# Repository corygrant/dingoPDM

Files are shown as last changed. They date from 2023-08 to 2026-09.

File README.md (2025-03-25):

 






## dingoPDM
dingoPDM is an Infineon Profet based Power Distribution Module. 

# [**Documentation**](https://corygrant.github.io/dingoPDM/)

# [**Store**](https://dingo-electronics.square.site/product/dingopdm/1)

## Disclaimer
Please note that this product has been designed by a hobbyist, not a professional. It is intended for off-road and testing use only. Users should operate the product at their own discretion and risk. The designer explicitly disclaims any responsibility for damage or injury that may result from the use of this product.

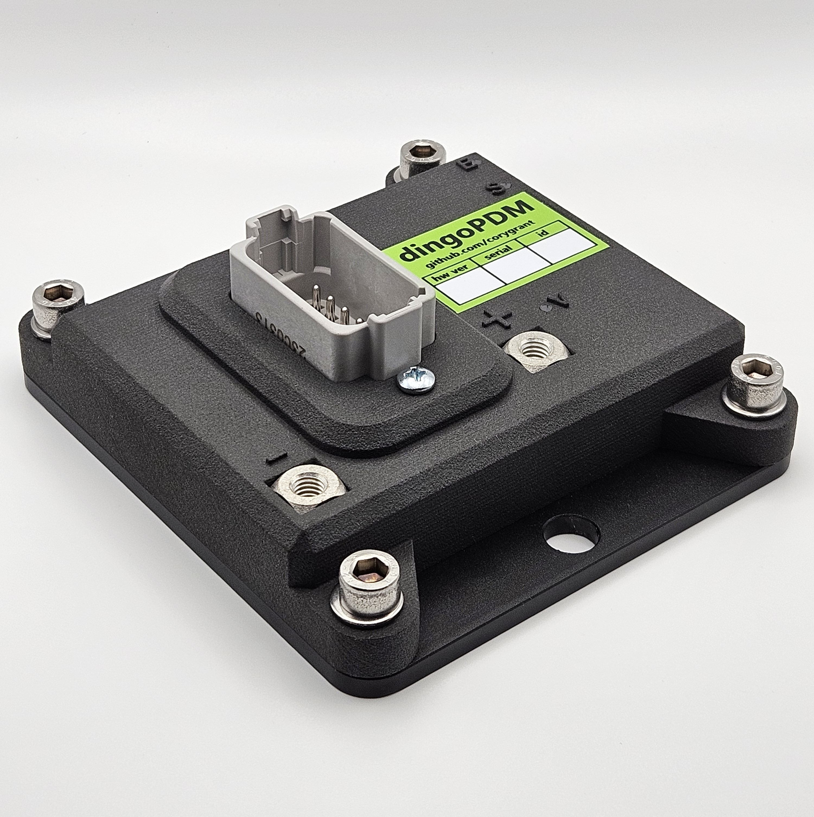
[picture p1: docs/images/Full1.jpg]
Full1


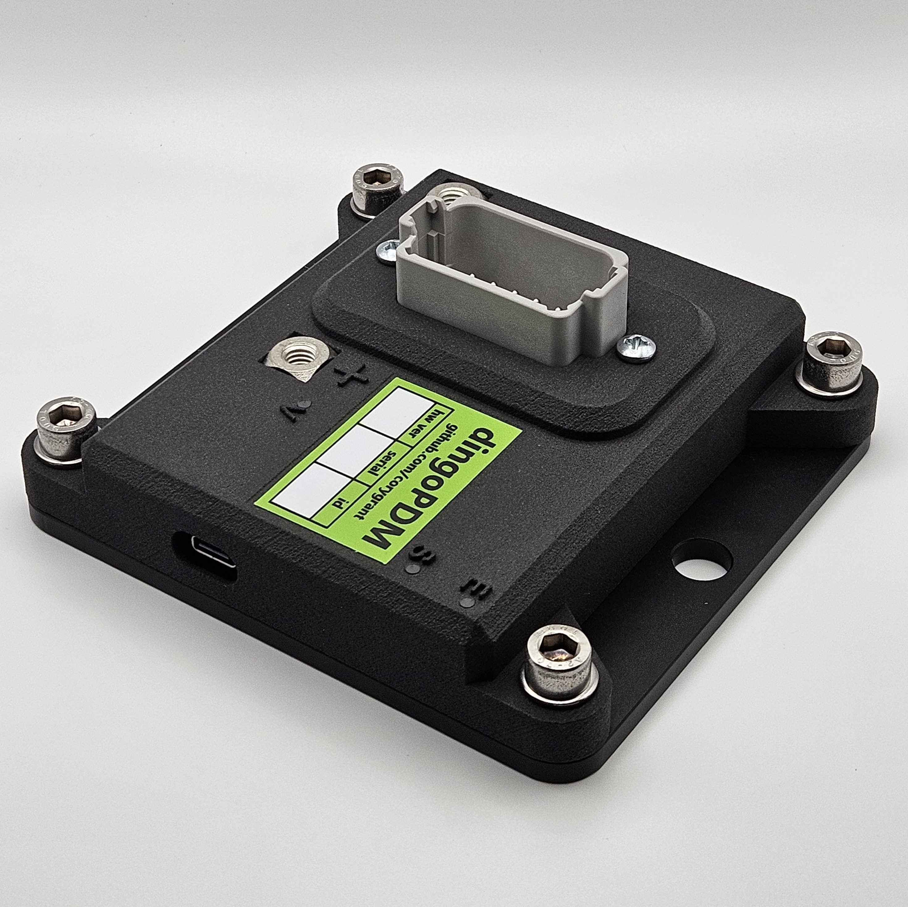
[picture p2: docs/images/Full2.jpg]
Full2


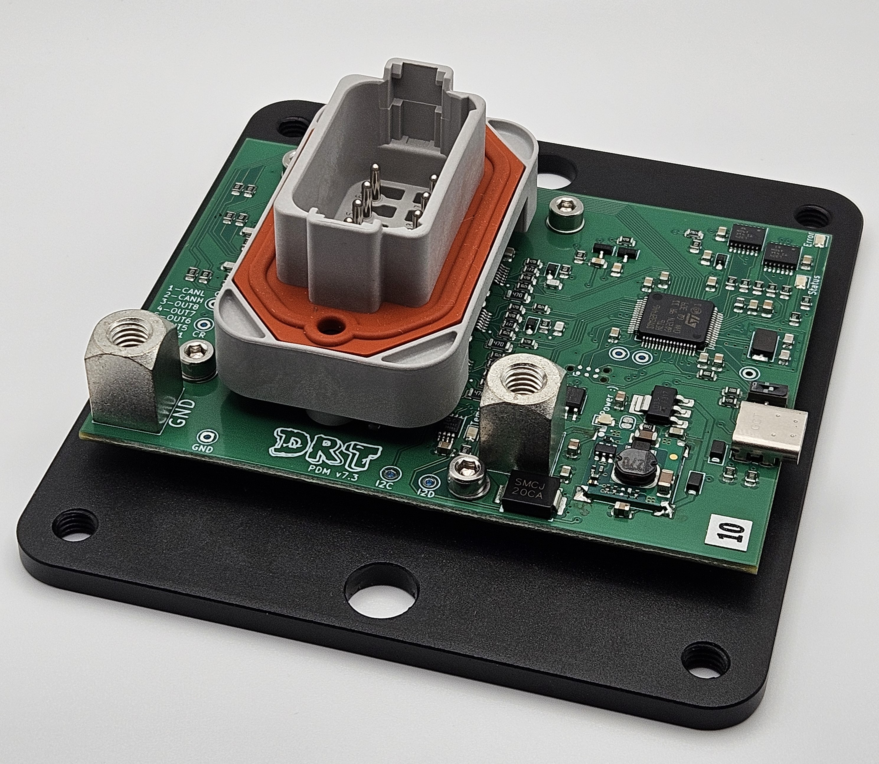
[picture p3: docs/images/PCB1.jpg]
PCB1


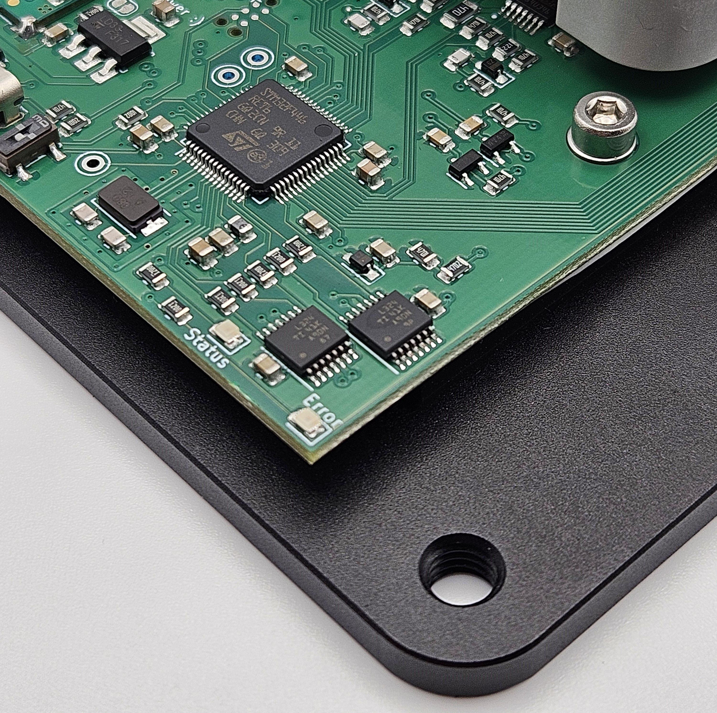
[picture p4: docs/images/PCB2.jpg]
PCB2


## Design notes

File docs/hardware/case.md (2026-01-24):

# Case

Exploded1
Exploded1

Exploded2
Exploded2

The mechanical design is centered around simple designs that can be created in a home shop. 

* 3D Printed Case
* Flat aluminum heatsink plate
* Flat aluminum baseplate
* The heatsink is designed to be 2 pieces. A heatsink plate and a baseplate
    * The heatsink plate provides clearance for the THT pins of the Deutsch connectors and the RedCube terminal while getting as close to the Profets as possible
    * !!! warning
        The heatsink plate should be covered on both sides with a thermal pad material to electricaly isolate the heatsink while still providing a thermal interface (Example: 3M 5583S)
    * The baseplate holds the case and also sandwiches the spacer plate to the PCB

## Exploded Assembly

| ID | Description | Details | Qty |
| ---- | --- | --- | --- |
| 1 | Baseplate | `Aluminum 6061` | 1 |
| 2 | Heatsink | `Aluminum 6061` | 1 |
| 3 | Case | `3D Print` | 1 |
| 4.1  | PCB | | 1 |
| 5.1  | Ring Lug | `M6` or `1/4"` | 1 |
| 5.2  | Lug Washers | `M6 Flat` | 2 |
| 5.3  | Lug Screws | `M6x1.0x14mm` | 2 |
| 5.5  | Case Washers | `M6 Flat` | 4 |
| 5.6  | Case Screws | `M6x1.0x14mm` | 4 |
| 5.7  | PCB Washers | `M3 Flat` | 4 |
| 5.8  | PCB Screws | `M3x0.5x12mm` | 4 |
| 6 | DT Connector | `12 Pin` | 1 |
| 10.1 | Light Pipe | `PLPC2-10MM` | 3 |
| 13 | Connector Screws | `No. 6, 5/8" Thread Forming` | 2 |

## Radlok

As an alternative, Amphenol Radlok 5.7mm connectors can be used for the battery connections instead of ring connectors. 

- Radlok 5.7mm pins and 4AWG connectors are rated at 120A
- Radlock 5.7mm 6AWG connectors are rated at 90A

???+ Note 

    Radlok M6 pin threads are slightly too long, use a washer under the pin to space the pin out. 

| Description | Detail | Rating | Qty | Part Number |
| --- | --- | --- | --- | --- |
| Pin | `M6x1.0` | 120A | 2 | `RL9057-101` |
| M6 Washer | `M6 Flat` | | 2 | |
| | | | | |
| Red Connector | `6AWG` / `16mm^2` | 90A | 1 | `RL0057-1-16RE` |
| Black Connector | `6AWG` / `16mm^2` | 90A | 1 | `RL0057-1-16BK` |
| Alternative Orange Connector | `6AWG` / `16mm^2` | 90A | 1 | `RL0057-1-16` |
| | | | | |
| Red Connector | `4AWG` / `25mm^2` | 120A | 1 | `RL00571-25RE`  |
| Black Connector | `4AWG` / `25mm^2` | 120A | 1 | `RL00571-25BK`  |
| Alternative Orange Connector | `4AWG` / `25mm^2` | 120A | 1 | `RL00571-25` |

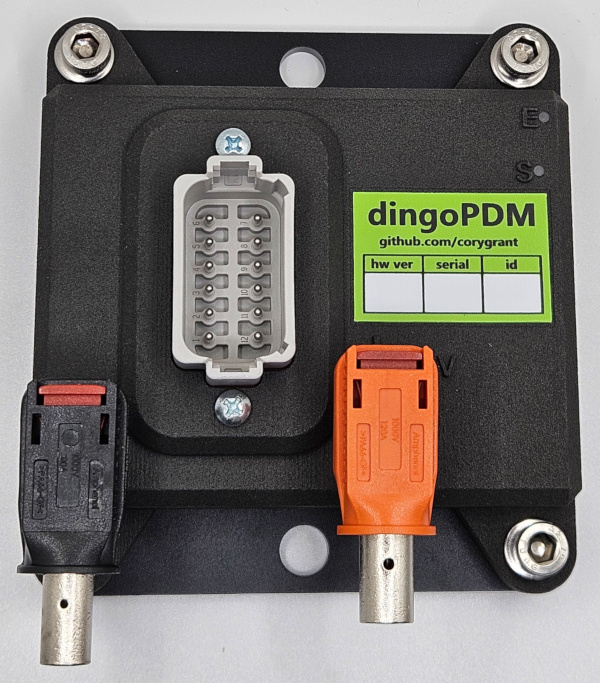
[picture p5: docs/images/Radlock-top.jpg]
RadlockTop


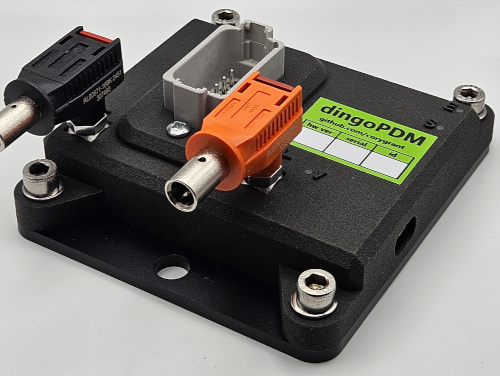
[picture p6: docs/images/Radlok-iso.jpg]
RadlockIso


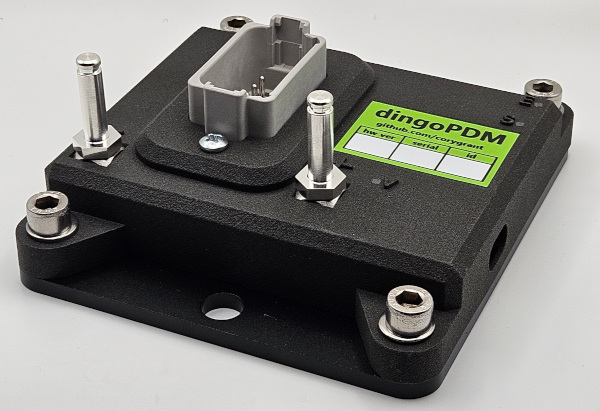
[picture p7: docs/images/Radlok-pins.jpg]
RadlockPins


## Models

Models of the baseplate, heatsink and case can be found here:

[**Case STEP Files**](https://github.com/corygrant/DingoPDM/tree/master/Export/V7.4/Case)

[**Complete STEP File**](https://github.com/corygrant/DingoPDM/tree/master/Export/V7.4) (DingoPDM_V7_4.step)

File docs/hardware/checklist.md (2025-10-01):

# Testing new boards 

These instructions will guide you through verifying some of the basic connections and functionalities.
It's adviced to go through the next steps **before** installing the main connector

|# | Task | Link |
| -| --- | --- |
| 1| Measure resistance between: TODO: verify measurement points | |
| 2| Connect USB and verify: 3v3, Power LED | |
| 3| Connect +12v and verify 5v | |
| 4| Write FW to processor | [FW Releases](https://github.com/corygrant/DingoPDM_FW/releases) |
| 5| Verify that the `Status` LED goes green after one power cycle of red LED (writed default config) | |
| 6| Enable each output in the Configurator. Verify that the output A values are 0. | |
| 7| Measure +12V at each output pad | |

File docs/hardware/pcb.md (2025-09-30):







# Introduction

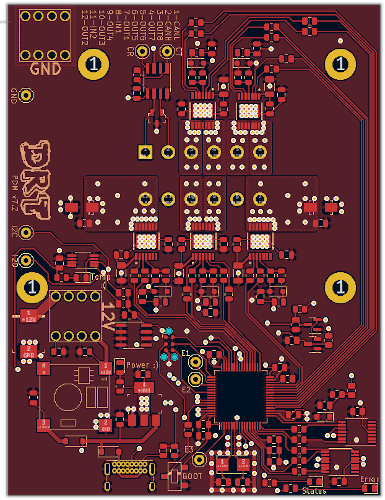
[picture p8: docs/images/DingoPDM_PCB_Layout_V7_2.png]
PCB Design


There are two versions of dingoPDM, standard and Max. 

dingoPDM = 8 outputs (shown above, low and medium current)

dingoPDM-Max = 4 outputs (high current)

## Components

**dingoPDM**

* 2x Profet `BTS7002-1EPP`
    * 2x 14A outputs 
    * With flyback diodes
* 3x Profet `BTS7008-2EPA`
    * 6x 8A outputs
* 2x Digital Inputs
    * Selectable pullup/pulldown
* `STM32F446RET6` Microcontroller
* 256Kbit `FRAM`
    * Settings storage
* CAN transceiver
    * No terminating resistor
* Board temperature measured using `MCP9808`
* 2x LEDs for power and temperature status
* 2x LEDs for status
* Onboard 12V to 5V to 3.3V regulation
* 2x M6 lug 12V power connection
    * Ground connection not used for output power, can be a small gauge (ex: 18AWG or 20AWG)
* 12V voltage measurement
* THT test pads for easy connection of logic analyzer (ex: Saleae leads)
* Deutsch `DT 12 pin` connector
    
**dingoPDM-Max (only differences listed)**

* 4x Profet `BTS70012-1ESP`
    * 4x 26A outputs 
    * With flyback diodes

## KiCad

* Designed using `KiCad v8.0.4`

## Design Notes

* Prior to V6, the design had a lot of features which meant a lot of parts
* To make the board cheaper, easier to source/produce and quicker to test the design was drastically simplified
* The Deutsch DT connector was selected due to it's popularity, part availability and ease of use
* BTS724 was used on V6, but removed for V7 due to thermal issues. It wouldn't trip until a very high current. 

## MCU Pinouts

### dingoPDM

| MCU Pin | Function | Type |
| --- | --- | --- |
| `PA0` | Output 1 Current Sense (IS) | Analog Input |
| `PA1` | Output 5/6 Current Sense (IS) | Analog Input |
| `PA2` | Output 7/8 Current Sense (IS) | Analog Input |
| `PA3` | Battery Voltage Sense | Analog Input |
| `PA4` | Output 8 Control Input (IN) | Digital Output |
| `PA5` | Output 7/8 Sense Select (DSEL)| Digital Output |
| `PA6` | Output 7/8 Sense Enable (DEN) | Digital Output |
| `PA7` | Output 7 Control Input (IN) | Digital Output |
| `PA8` | - | - |
| `PA9` | USB VBUS Sense | Digital Input  |
| `PA10`  | Input 1 | Digital Input  |
| `PA11`  | USB D- (DM) | |
| `PA12`  | USB D+ (DP) | |
| `PA13`  | SWDIO | |
| `PA14`  | SWCLK | |
| `PA15`  | - | - |
| `PB0` | Output 5/6 Sense Enable (DEN) | Digital Output |
| `PB1` | Output 1 Control Input (IN) | Digital Output |
| `PB2` | Output 1 Sense Enable (DEN) | Digital Output |
| `PB3` | SWO | |
| `PB4` | - | - |
| `PB5` | - | - |
| `PB6` | I2C1 SCL | |
| `PB7` | I2C1 SDA | |
| `PB8` | CAN RX | |
| `PB9` | CAN TX | |
| `PB10`  | Output 1 Control Input (IN) | Digital Output |
| `PB12`  | Output 4 Control Input (IN) | Digital Output |
| `PB13`  | - | - |
| `PB14`  | Output 3/4 Sense Select (DSEL)| Digital Output |
| `PB15`  | Output 3/4 Sense Enable (DEN) | Digital Output |
| `PC0` | Status LED | Digital Output |
| `PC1` | Error LED | Digital Output |
| `PC2` | Output 2 Current Sense (IS) | Analog Input |
| `PC3` | Output 3/4 Current Sense (IS) | Analog Input |
| `PC4` | Output 6 Control Input (IN) | Digital Output |
| `PC5` | Output 5/6 Sense Select (DSEL)| Digital Output |
| `PC6` | Output 3 Control Input (IN) | Digital Output |
| `PC7` | Output 2 Sense Enable (DEN) | Digital Output |
| `PC8` | Output 2 Control Input (IN) | Digital Output |
| `PC9` | Input 2 | Digital Input  |
| `PC10`  | Extra 1 | Undefined |
| `PC11`  | Extra 2 | Undefined |
| `PC12`  | CAN Standby | Digital Output |
| `PC13`  | Extra 3 | Undefined |
| `PC14`  | - | - |
| `PC15`  | - | - |
| `PD2` | - | - |
| `PH0` | Oscillator | |
| `PH1` | Oscillator | |

### dingoPDM-Max

| MCU Pin | Function | Type |
| --- | --- | --- |
| `PA0` | Output 3 Current Sense (IS) | Analog Input |
| `PA1` | Output 4 Current Sense (IS) | Analog Input |
| `PA2` | - | |
| `PA3` | Battery Voltage Sense | Analog Input |
| `PA4` | - | |
| `PA5` | Output 4 Sense Enable (DEN) | Digital Output |
| `PA6` | Output 4 Control Input (IN) | Digital Output |
| `PA7` | - | |
| `PA8` | - | - |
| `PA9` | USB VBUS Sense | Digital Input  |
| `PA10`  | Input 1 | Digital Input  |
| `PA11`  | USB D- (DM) | |
| `PA12`  | USB D+ (DP) | |
| `PA13`  | SWDIO | |
| `PA14`  | SWCLK | |
| `PA15`  | - | - |
| `PB0` | Output 3 Control Input (IN) | Digital Output |
| `PB1` | - | |
| `PB2` | - | |
| `PB3` | SWO | |
| `PB4` | - | - |
| `PB5` | - | - |
| `PB6` | I2C1 SCL | |
| `PB7` | I2C1 SDA | |
| `PB8` | CAN RX | |
| `PB9` | CAN TX | |
| `PB10`  | - | |
| `PB12`  | - | |
| `PB13`  | Output 1 Sense Enable (DEN) | Digital Output |
| `PB14`  | Output 1 Control Input (IN) | Digital Output |
| `PB15`  | - | |
| `PC0` | Status LED | Digital Output |
| `PC1` | Error LED | Digital Output |
| `PC2` | Output 2 Current Sense (IS) | Analog Input |
| `PC3` | Output 1 Current Sense (IS) | Analog Input |
| `PC4` | - | Digital Output |
| `PC5` | Output 3 Sense Enable (DEN) | Digital Output |
| `PC6` | Output 2 Sense Enable (DEN) | Digital Output |
| `PC7` | Output 2 Control Input (IN) | Digital Output |
| `PC8` | - | |
| `PC9` | Input 2 | Digital Input  |
| `PC10`  | Extra 1 | Undefined |
| `PC11`  | Extra 2 | Undefined |
| `PC12`  | CAN Standby | Digital Output |
| `PC13`  | Extra 3 | Undefined |
| `PC14`  | - | - |
| `PC15`  | - | - |
| `PD2` | - | - |
| `PH0` | Oscillator | |
| `PH1` | Oscillator | |

## BOMs

[dingoPDM BOM](../bom/dingoPDM/ibom.html)

[dingoPDM-Max BOM](../bom/dingoPDM-Max/ibom.html)

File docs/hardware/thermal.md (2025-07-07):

## Full Load Test

```vegalite 
{
    "schema-url": "assets/charts/dingopdm_stresstest.json"
}
```

```vegalite 
{
    "schema-url": "assets/charts/dingopdmmax_stresstest.json"
}
```

!!! Tip
    - Pan: click + drag
    - Zoom: mouse wheel
    - Reset: double click

!!! Warning
    If chart does not load, refresh the page

- Full load tests were conducted with a dummy load at 71A total.
- The device was mounted horizontaly (worst case).
- Ambient temperature `19°C`
- Resistive load on all outputs
- Temperature taken with onboard temperature sensor, unless otherwise noted
- All outputs on and under load
- All outputs wired using 14AWG TXL in free air and approx. 2 feet long
- Battery power wired using 4AWG cable and copper lug
- Ground wired using 20AWG TXL
- `DC_100`
    - `100%` duty cycle
    - No case
- `DC_50`
    - `50%` duty cycle @ `400Hz`
    - No case
- `CLOSED`
    - `100%` duty cycle
    - Case installed
- `TOP`
    - `100%` duty cycle
    - Case installed
    - Temperature taken at top of Profet (output 3/4) using thermocouple
- `Yellow`
    - Warning temperature limit `55°C`
    - Reaction: warning message sent
- `Red`
    - Critical temperature limit `80°C`
    - Reaction: device shutdown, power cycle required

!!! note "Notes"
    - Thermal performance is similar with or without PWM (on resistive loads)
    - The onboard temperature sensor follows the junction temperature within a few degrees after 10 minutes
    - Installing the case increases the temperature by a maximum of `5°C`
    - The temperatures seen by the onboard sensor and thermocouple are much lower than the maximum temperature of the Profet junction `150°C`

## Thermal Images

These images were captured during the 100% duty cycle full load test. 

The highest temperature recorded was 61°C at the top of the output 3/4 Profet (BTS7008-2EPA). 

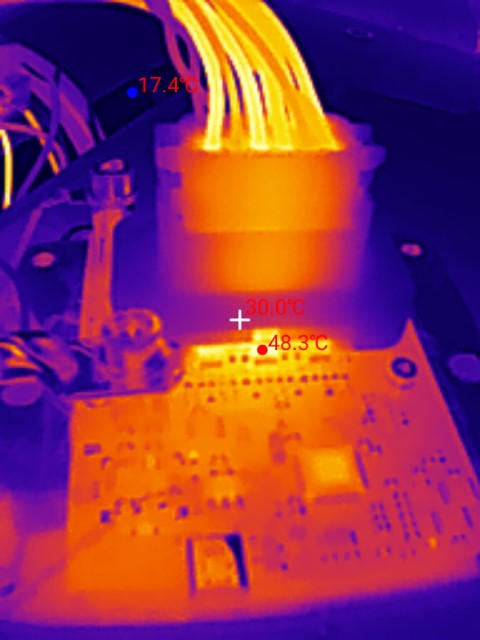
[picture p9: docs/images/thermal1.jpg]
Thermal1

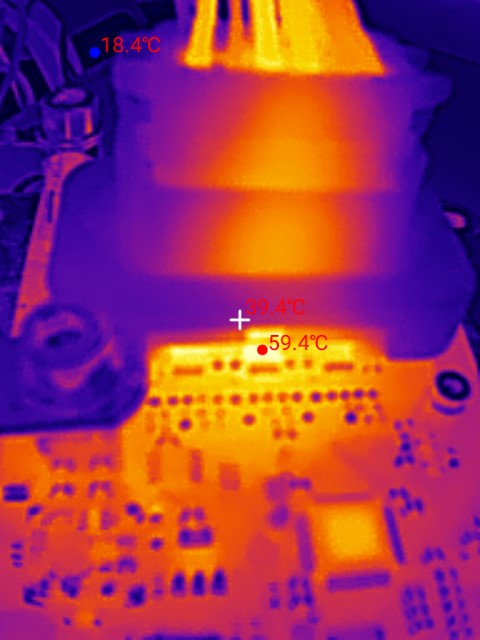
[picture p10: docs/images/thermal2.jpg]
Thermal2

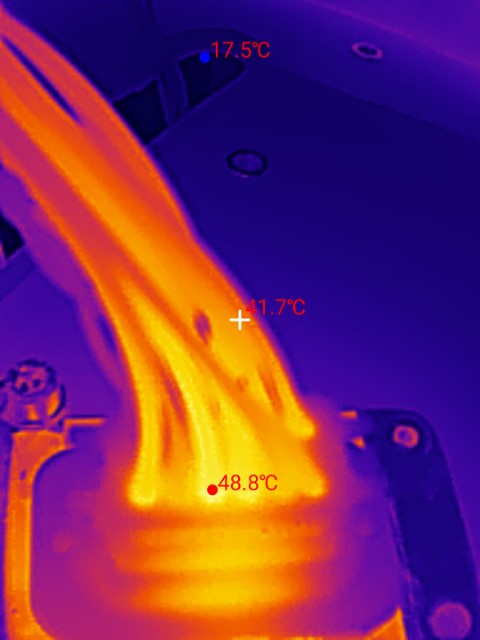
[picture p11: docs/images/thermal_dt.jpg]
ThermalDT

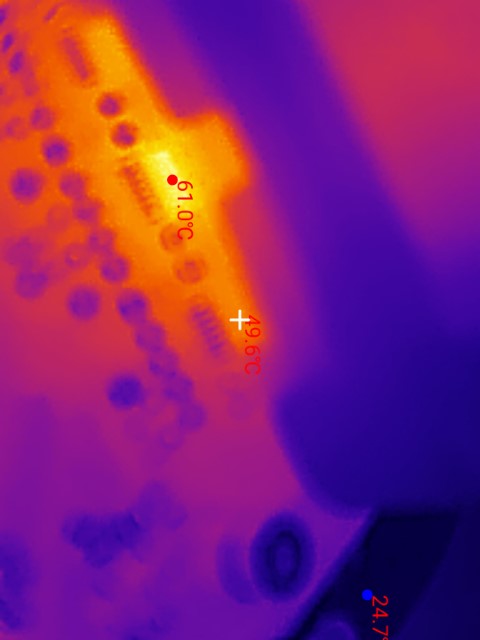
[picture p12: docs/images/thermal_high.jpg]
ThermalHigh


!!! note "Notes"
    - Deutsch DT connectors have an operating temperature range up to `125°C`
      - While we do not know the actual internal temperature, the highest recorded external temperature during these tests was around `50°C`
      - That is much lower than the rated operating temperature, which suggests higher current may be possible

## Thermal Resistance

Before building or testing any hardware, we can calculate the expected temperature on the top of the Profet. 

To do this, we need these values:

- Ambient temperature (°C)
- Total current (A)
- R<sub>thJA</sub> (K/W)
    - See Infineon datasheet section 4.4
    - Thermal Resistance Junction to Ambient, (K/W)=(C/W)
    - Temperature rise per dissipated watt from the internal junction to ambient
    - Value calculated by Infineon at natural convection on a 4 layer PCB:
        - 2oz outer copper
        - 1oz inner copper
        - 76.2mm x 114.3mm board
    - The resulting value is added to the ambient temperature
    - Infineon uses Kelvin/Watt, this is equal to Celsius/Watt
- Ψ<sub>JTOP</sub> (K/W)
    - See Infineon datasheet section 4.4
    - Thermal Characterization Parameter Junction Top, (K/W)=(C/W)
    - Thermal resistance between the internal junction and the top of chip case
    - Value calculated by Infineon using the same test parameters as R<sub>thJA</sub> above
    - The resulting value will be subtracted from the junction temperature to find the expected temperature at the top of the chip case
- R<sub>DS(ON)</sub> (mΩ)
    - See Infineon datasheet section 7.5.1
    - On State Resistance (mΩ)
    - Resistance between the battery connection and the output when the Profet is on, varies with junction temperature
    - Use this to calculate the heat generated by the chip
    - Assuming the junction temperature is 60°C, use R<sub>DS(ON)</sub> of 3.2mΩ and 11mΩ

BTS7002-1EPP

`Power(W)` = (Current x R<sub>DS(ON)</sub>) x Current = 12<sup>2</sup> x 3.2 = `0.461 W`

`Junction Temp(°C)` = Ambient + (Power x R<sub>thJA</sub>) = 19 + (0.461 x 30.7) = `33°C`

`Case Top(°C)` = Junction Temp - (Power * Ψ<sub>JTOP</sub>) = 33 - (0.461 x 3) = `32°C`

BTS7008-2EPA

`Power(W)` = (Current x R<sub>DS(ON)</sub>) x Current = 8<sup>2</sup> x 11 = `0.704 W` x 2 = `1.408 W`

`Junction Temp(°C)` = Ambient + (Power x R<sub>thJA</sub>) = 19 + (1.408 x 30.9) = `63°C`

`Case Top(°C)` = Junction Temp - (Power * Ψ<sub>JTOP</sub>) = 63 - (1.408 x 1.7) = `60°C`

Table format:

| Model | R<sub>DS(ON)</sub> @ 25°C (mΩ) | R<sub>DS(ON)</sub> @ 150°C (mΩ) | R<sub>DS(ON)</sub> (mΩ) | Current Per Output (A) | Dissipated Power (W) | # Channels | Total Dissipated Power (W) | Ambient Temp (°C) | R<sub>thJA</sub> (C/W) | Junction Temp (°C) | Ψ<sub>JTOP</sub> (C/W) | Case Top (°C) |
|:---:|:---:|:---:|:---:|:---:|:---:|:---:|:---:|:---:|:---:|:---:|:---:|:---:|
| BTS7002-1EPP | 2.6 | 4.8 | 3.2 | 12 | 0.461 | 1 | 0.461 | 19 | 30.7 | 33 | 3 | 32 |
| BTS7008-2EPA | 9 | 16 | 11 | 8 | 0.704 | 2 | 1.408 | 19 | 30.9 | 63 | 1.7 | 60 |

!!! note "Notes"
    - The BTS7008-2EPA expected case temperature (`60°C`) is close to the measured values
        - Thermocouple = `55°C` 
            - May be reduced due to glue used to hold thermocouple
        - Thermal camera = `61°C`
    - The BTS7002-1EPP expected case temperature (`32°C`) is lower than the measured value
        - Thermal camera = `50°C`
        - This may be caused by the adjacent BTS7008-2EPA which is at a higher temperature of `60°C`
    - The Profet maximum junction temperature is `150°C`, much higher than the temperatures we are seeing in these full load tests

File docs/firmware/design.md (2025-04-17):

# Design

## Device State

dingoPDM uses a simple state machine to control overtemperature, sleep and error behavior. 

``` mermaid
stateDiagram
    [*] --> Run : Power On
    Run --> OverTemp : Temp > Max
    OverTemp --> Run : Temp < Max
    Run --> Sleep : Timeout
    Sleep --> Run : Activity
    Run --> Error : Error
    OverTemp --> Error : Temp > Critical
    Error --> [*] : Power Cycle Required
```

See [Sleep](./sleep.md) for information on the sleep timeout and wake

See [Errors](./errors.md) for information on possible fatal errors

See [LEDs](./leds.md) for possible status and error LED states

- `Run`
    - Default state
- `Sleep`
    - All outputs off
    - Low power state
- `OverTemp`
    - Temperature sensor mounted to PCB over max temp
    - Warning message sent
    - Outputs remain on
- `Error`
    - Fatal error state, power cycle required to recover

## Files

dingoPDM firmware files can be divided between ChibiOS, OpenOCD and dingoPDM specific files

### ChibiOS

- cfg/ 
    - ChibiOS configuration files
- ChibiOS/
    - ChibiOS repository files
- boards/./board (.h / .c / .mk)
    - ChibiOS configuration files
    - Unique between dingoPDM and dingoPDM-Max
  
### OpenOCD

- interface/
    - ST Link debug interface
- target/
    - STM32F4 debug configuration
  
### dingoPDM

#### Folders

- boards/
    - dingoPDM and dingoPDM-Max specific config and utils
    - hw_devices
        - 
- boards/cortex-m4/
    - MCU specific utils (stop/bootloader)
- devices/ 
    - External devices (future)
- hardware/
    - Onboard hardware devices (FRAM/temperature)
- keypad/
    - CAN keypads
- wiper/
    - Wiper function

#### Declaration

| File | |
| :--- | :--- |
| dingopdm_config | FW version / delays / limits / etc. |
| enums | All enum declarations |

#### Entry Point

| File | |
| :--- | :--- |
| main | Init ChibiOS + start PDM |

#### PDM Main

| File | |
| :--- | :--- |
| pdm  | Main PDM logic |

#### Hardware

| File | |
| :--- | :--- |
| can  | CAN Tx/Rx - Post/Fetch Mailboxes |
| led  | Status/Error LEDs |
| usb  | USB Tx/Rx - Post/Fetch Mailboxes |

#### Configuration 

| File | |
| :--- | :--- |
| config_handler | Process setting change |
| config | Read/Write config in FRAM |
 
#### Functions

| File | |
| :--- | :--- |
| can_input | CAN Rx decoding / logic |
| condition | Condition logic |
| counter | Counter logic |
| digital | Digital input logic |
| flasher | Flasher logic |
| input | Momentary/latching logic |
| profet | Output logic + current measurement  |
| pwm | Output Pulse Width Modulation logic |
| starter | Starter disable logic |
| virtual_input | Virtual input logic |

#### Utilities

| File | |
| :--- | :--- |
| crc | Calculate CRC |
| edge | Detect edge - rising/falling  |
| error | Fatal error - Flash LED |
| mailbox | CAN/USB Tx/Rx mailbox buffers |
| msg | Status Tx messages |

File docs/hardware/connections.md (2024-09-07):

# Connections

## Connectors

Connections
Connections

|ID| Connector | Details | Qty | Note |
| -| --- | --- | --- | --- |
| 1| DT 12 Pos Connector | `DT06-12SA` | 1 | |
|  | DT 12 Wedgelock | `W12S` | 1 | |
|  | 14-16AWG Socket | `0462-209-16141` | 2 | |
|  | 16-20AWG Socket | `0462-201-16141` | 10  | |
| 2| 12V DC Power Lug | `M6` or `1/4"` lug  | 1 | Large gauge wire required (4 to 10AWG) |
| 3| Ground Lug | `M6` or `1/4"` lug  | 1 | Small gauge wire can be used (18 to 20 AWG) |
| 4| USB Type C | | 1 | USB C-C cables are not supported with v7.2 hardware |

## USB

!!!warning
    USB C-C cables are not supported with v7.2 hardware

| Hardware | USB C-C | USB A-C |
|---| ---| ---|
| v7.2 | :red_square:  | :green_square: |
| v7.3 and up | :green_square:| :green_square: |

## Pinout

DT 12
DT 12

# dingoPDM

| Pin | Function| Current |
| --- | --- | --- |
| 1 | CAN L | |
| 2 | CAN H | |
| 3 | Output 8| 8A |
| 4 | Output 7| 8A |
| 5 | Output 6| 8A |
| 6 | Output 5| 8A |
| 7 | Output 1| 13A |
| 8 | Input 1 | |
| 9 | Output 4| 8A |
| 10  | Output 3| 8A |
| 11  | Input 2 | |
| 12  | Output 2| 13A |

!!! note
    The current outputs are estimates and based on the maximum current rated by Deutsch.
    The possible current may be higher depending on the installation and configuration. 

!!! note
    No internal terminating resistor on CAN connection, must be added externally    

# dingoPDM-Max

| Pin | Function| Current |
| --- | --- | --- |
| 1 | Output 4| 26A |
| 2 | Output 4| 26A |
| 3 | CAN L | |
| 4 | CAN H | |
| 5 | Output 3| 26A |
| 6 | Output 3| 26A |
| 7 | Output 1| 26A |
| 8 | Output 1| 26A |
| 9 | Input 1 | |
| 10  | Input 2 | |
| 11  | Output 2| 26A |
| 12  | Output 2| 26A |

!!! note
    The current outputs are estimates and based on the maximum current rated by Deutsch.
    The possible current may be higher depending on the installation and configuration. 

!!! note
    No internal terminating resistor on CAN connection, must be added externally

## Test Points

Test Points
Test Points

| Label | Function | MCU Pin |
| --- | --- | --- |
| I2C | I2C1 Clock | `PB6` |
| I2D | I2C1 Data | `PB7` |
| CR | CAN Receive  | `PB8` |
| CT | CAN Transmit | `PB9` |
| E1 | Extra 1 | `PC10`  |
| E2 | Extra 2 | `PC11`  |
| E3 | Extra 3 | `PC13`  |
| GND | Ground | `Ground`|
| TagConnect| Debugger | |

## Wipers

To control a wiper motor directly from dingoPDM a WiperModule is required. 
The WiperModule uses 3 relays to properly control the slow, fast and brake functions of a wiper motor. 
The internal connections are made based on the slow input (which also supplies all power to the motor) and the fast input. 
The ground and park signals are passed through the module. 

Information about the WiperModule can be found here: [WiperModule](https://github.com/corygrant/WiperModule)

WiperModuleConnections
WiperModuleConnections

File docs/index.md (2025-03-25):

# dingoPDM

 


dingoPDM and dingoPDM-Max are open source Infineon Profet based Power Distribution Modules. 

<span style="font-size: 1.5em;">
**[Getting Started](./gettingstarted/introduction.md)**
</span>

Full1

Full2

PCB1

PCB2

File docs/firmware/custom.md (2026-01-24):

# Adding Custom Board Support to dingoPDM Firmware

## Overview

This guide walks you through adding support for a custom PDM board to the dingoPDM firmware. By following these steps, you'll build the firmware to run on your custom hardware while reusing existing functionality.

## Hardware

### Pins

The pins you need depend on which Profets (switching devices) you're planning to use.

#### BTS7002-1EPP

| Pin Type | Count | Name  | Purpose |
| --- | ----- | ----- | --- |
| Analog Input | 1 | `IS`  | Current feedback |
| Digital Output | 1 | `IN`  | Drive transistor ON/OFF (PWM-enabled) |
| Digital Output | 1 | `DEN` | Enable current sensing |

#### BTS7008-2EPP Variant

| Pin Type | Count | Name | Purpose |
| --- | ----- | --- | --- |
| Analog Input | 1 | `IS` | Current feedback |
| Digital Output | 1 | `IN` | Drive transistor ON/OFF (PWM-enabled) |
| Digital Output | 1 | `DSEL` | Select which output's current is measured |
| Digital Output | 1 | `DEN`  | Enable current sensing |

> **Note:** The BTS7008-2EPP uses a single shared current feedback channel with multiplexing via `DSEL`, while the BTS7002-1EPP has a dedicated feedback pin. All `IN` pins must support PWM; other outputs can use regular GPIO.

### PCB Design

!!! warning "To Do"
    *Schematic recommendations and layout guidelines*

---

## Firmware

The dingoPDM firmware is modular—adding a new board requires minimal changes outside the `boards/` folder. Follow these steps in order:

### Overview

- [ ] Copy and rename an existing board folder
- [ ] Update the `.ld` linker script
- [ ] Configure `board.mk`
- [ ] Define pins in `board.h`
- [ ] Set output count in `port.h`
- [ ] Declare outputs in `hw_devices.cpp`
- [ ] Update message handling in `msg.cpp`
- [ ] Update root `Makefile`
- [ ] Add PWM configuration in `port_pwm.h`
- [ ] Enable timers in `mcuconf.h` (if needed)

---

### Files

#### Linker Script (`.ld`)

**Location:** `boards/your_board_name/`

**Changes needed:**
- Rename the `.ld` file to match your board name exactly

---

#### Board Configuration (`board.mk`)

**Location:** `boards/your_board_name/`

???+ Example

    ```makefile
    # List of all the board related files
    BOARDSRC = ./boards/your_board_name/board.c

    # Required include directories
    BOARDINC = ./boards/your_board_name
    ```

---

#### Pin Definitions (`board.h`)

**Location:** `boards/your_board_name/`

This file initializes all MCU pins and their configurations. Define each pin type with the settings below:

!!! Note
    Refer to ChibiOS documentation on `board.h` configuration

???+ abstract "`IN` Pin Configuration"

    ```c
    Mode     = OUTPUT
    Otype    = PUSHPULL
    Ospeed   = HIGH
    Pupdr    = PULLDOWN
    Odr      = LOW
    Afio     = AF
    ```

???+ abstract "`DEN` Pin Configuration"

    ```c
    Mode     = OUTPUT
    Otype    = PUSHPULL
    Ospeed   = HIGH
    Pupdr    = PULLDOWN
    Odr      = LOW
    Afio     = AF
    ```

???+ abstract "`DSEL` Pin Configuration"

    ```c
    Mode     = OUTPUT
    Otype    = PUSHPULL
    Ospeed   = HIGH
    Pupdr    = PULLDOWN
    Odr      = LOW
    Afio     = AF
    ```

???+ abstract "`IS` Pin Configuration"

    ```c
    Mode     = ANALOG
    Otype    = PUSHPULL
    Ospeed   = LOW
    Pupdr    = FLOATING
    Odr      = LOW
    Afio     = AF
    ```

---

#### Counts (`port.h`)

**Location:** `boards/your_board_name/`

???+ Example

    ```c
    #define PDM_TYPE 2              // 0 = PDM, 1 = PDM-MAX, 2 = your new board
    #define PDM_NUM_OUTPUTS 8       // Total number of Profet outputs on your board
    #define PDM_NUM_INPUTS 2        // Total number of digital inputs on your board
    ```

!!! warning "To Do"

    Setting up and using VarMap

---

#### Output Declarations (`hw_devices.cpp`)

**Location:** `boards/your_board_name/`

**Key points:**
- Only modify the `#if PDM_TYPE == 2` section (match your PDM_TYPE value)
- Declare outputs in order: `IN`, `DEN`, `DSEL`, `IS`
- `&PWMD` specifies the timer module (must be unique per output)
- `&pwmCfg` references the PWM configuration (defined in `port_pwm.h`)

???+ Example

    ```c
    #if PDM_TYPE == 2
    // Output declarations for your board
    // Each output needs timer assignment and config reference
    #endif
    ```

---

#### CAN/USB Message Handling (`msg.cpp`)

**Location:** `common/` (root-level modification)

Update this file to transmit the status of your new outputs in both CAN and USB streams. Check existing board implementations for the pattern.

---

#### Root Makefile

**Location:** `Makefile` (repository root)

???+ Example "Changes needed"

    ```makefile
    ifeq ($(BOARD),)
        BOARD = your_board_name
    endif
    ```

---

#### PWM Configuration (`port_pwm.h`)

**Location:** `boards/your_board_name/`

**Steps:**
1. Copy an existing PWM configuration and rename it for your board
2. Declare the `.callback` member for each output
3. Add callback functions in two sections:
   - **Output PWM period callbacks** – called when PWM period changes
   - **Output PWM duty cycle callbacks** – called when duty cycle changes

???+ Example "Example callback pattern"

    ```c
    static void your_board_pwm_period_callback(uint16_t value) {
        // Handle period change
    }

    static void your_board_pwm_duty_callback(uint16_t value) {
        // Handle duty cycle change
    }
    ```

---

#### Timer Configuration (`mcuconf.h`)

**Location:** `boards/your_board_name/`

**When needed:**
- Enable new timer peripherals **only if** your PWM configuration uses timers not already enabled
- Check existing boards to see which timers are already configured
- If reusing timers from the reference board, no changes needed

---

## Build and Flash

Once all files are configured:

- **Build the firmware**
   ```bash
   make BOARD=your_board_name
   ```

- **Flash to your STM32**
    - Follow the existing [firmware flashing wiki](https://corygrant.github.io/dingoPDM/firmware/updating/)

---

## Validation Checklist

Before testing your custom board:

- [ ] All pin definitions in `board.h` match your schematic
- [ ] `PDM_NUM_OUTPUTS` matches your physical output count
- [ ] `PDM_NUM_INPUTS` matches your physical input count
- [ ] `PDM_TYPE` is unique and consistent across all files
- [ ] All PWM timer assignments are unique (no conflicts)
- [ ] `msg.cpp` includes your outputs in CAN/USB telemetry
- [ ] `.ld` linker script is renamed correctly
- [ ] Firmware builds without errors: `make BOARD=your_board_name`

---

## Common Issues & Troubleshooting

| Issue | Cause | Solution |
| --- | --- | --- |
| **Linker errors** | `.ld` file not renamed or path wrong | Verify `.ld` filename matches board name exactly |
| **Undefined PDM_TYPE** | Inconsistent `PDM_TYPE` values across files | Search all files and ensure consistency |
| **PWM conflicts** | Timer assigned to multiple outputs | Review `hw_devices.cpp` and use unique timers |
| **Build fails: unknown board** | Root Makefile not updated | Add board to `ifeq` block in root `Makefile` |
| **Outputs not responding** | Wrong pin configuration | Double-check `board.h` pin modes and alternate functions |

---

## Reference: File Structure

```
DingoPDM_FW/
├── Makefile
├── boards/
│   ├── existing_board_1/
│   │   ├── board.c
│   │   ├── board.h
│   │   ├── board.mk
│   │   ├── board_name.ld
│   │   ├── hw_devices.cpp
│   │   ├── mcuconf.h
│   │   ├── port.h
│   │   └── port_pwm.h
│   └── your_board_name/          ← Copy here
│       ├── board.c
│       ├── board.h
│       ├── board.mk
│       ├── your_board_name.ld
│       ├── hw_devices.cpp
│       ├── mcuconf.h
│       ├── port.h
│       └── port_pwm.h
└── common/
    ├── msg.cpp                    ← Update here
    └── ...
```

---

## Next Steps

After building and flashing:

- Verify all outputs turn on/off correctly
- Monitor current feedback (`IS`) pins via CAN/USB telemetry
- Test PWM duty cycle control on `IN` pins
- Validate multiplexing on `DSEL` (BTS7008-2EPP only)

For questions, refer to the main [dingoPDM GitHub repository](https://github.com/corygrant/DingoPDM_FW)

!!! Note
 
    Thanks to **jabbarider** for this write up

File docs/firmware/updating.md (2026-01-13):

dingoPDM firmware can be updated using the onboard USB-C connection. 

## Latest Firmware

The latest built firmware can be found on the repo on [the release page](https://github.com/corygrant/DingoPDM_FW/releases)

## STM32CubeProgrammer

To update the firmware, the STMicroelectronics STM32CubeProgrammer is used. 

This software can be downloaded here: [STM32CubeProgrammer](https://www.st.com/en/development-tools/stm32cubeprog.html)

## Entering Bootloader

To update the firmware, the device must be put into the bootloader. 

This can be done using one of these methods:

* Remove the case and move the [boot switch](#boot-switch) to the bootloader position
* Use DingoConfigurator [FwUpdate button](#fwupdate) to jump the device to the bootloader

## Boot Switch

To update the firmware, the device must be put into bootloader

One option is using the `boot` switch on the PCB. 

!!! Note
    The case must be removed to access the boot switch.

    * Remove the DT connector and any wires going to the power/ground connections
    * Remove the 2x Philips screws next to the DT connector
    * Remove the 4x M6 screws around the perimeter of the device
    * Slide/wiggle the case up and off the device

To enter the bootloader, move the slide switch to the position that aligns it with the lines on the switch body

BootSwitch1
BootSwitch1

!!! Warning
    After updating, remember to set the boot switch back to the original position

## FwUpdate

After connecting to the dingoPDM using dingoConfigurator, the `FwUpdate` button on the toolbar to send the `~BOOTL` message to put the device into the bootloader.

!!! Warning
    Pressing the `FwUpdate` button will stop the PDM and drop communication to DingoConfigurator

## Connection

Connect a USB-C to USB-A cable to the PC. 

!!! Note
    V7.2 PCBs do not support USB-C to USB-C cables, a USB-C to USB-A cable must be used

!!! Note
    12V power is not required to perform the firmware update, the device will be powered by the USB cable

To verify that the device has entered the bootloader:

* Open the Windows `Device Manager`
* Expand `Universal Serial Bus devices`
* The `STM32 BOOTLOADER` should be listed
* DeviceManager

## Applying Update

* Install `STM32CubeProgrammer`
* Open `STM32CubeProgrammer`
* Change connection type to `USB`
* Press the refresh button to update the port

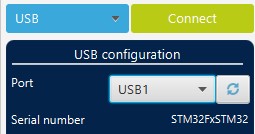
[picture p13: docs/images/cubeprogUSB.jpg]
CubeProgUSB
* 

* Press the `Connect` button, after successful connection the `Target Information` should be updated
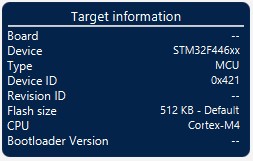
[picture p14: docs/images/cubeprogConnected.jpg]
CubeProgConnected
* 
* Select the second icon on the left, `Erasing & Programming`
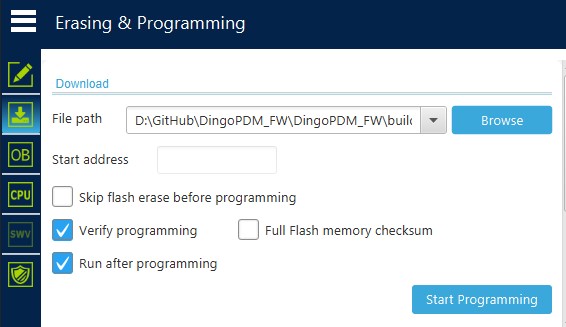
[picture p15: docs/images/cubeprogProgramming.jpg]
CubeProgProgramming
* 
* Press `Browse` and select the new firmware .hex file
* Verify `Skip flash erase before programming` is unchecked
* Verify `Verify programming` and `Run after programming` are checked
* Press `Start Programming`
* After successful programming, the device will disconnect
* You should also receive pop-ups verifying successful programming
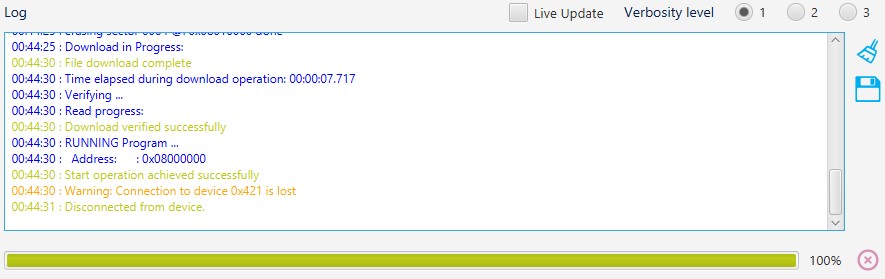
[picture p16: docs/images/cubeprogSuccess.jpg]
CubeProgSuccess
* 

## Success

Congrats! You successfuly updated the dingoPDM firmware. 

The firmware version can be verified using DingoConfigurator

!!! Warning
    Don't forget to set the boot switch back to the original position!

!!! Danger
    A POWER CYCLE IS REQUIRED any time the boot switch is changed

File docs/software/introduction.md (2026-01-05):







!!! warning
    DingoConfigurator has been replaced by [dingoConfig](https://github.com/corygrant/dingoConfig/releases). Documentation will be updated. 

DingoConfigurator is a Windows application designed to configure and monitor dingoPDM. 

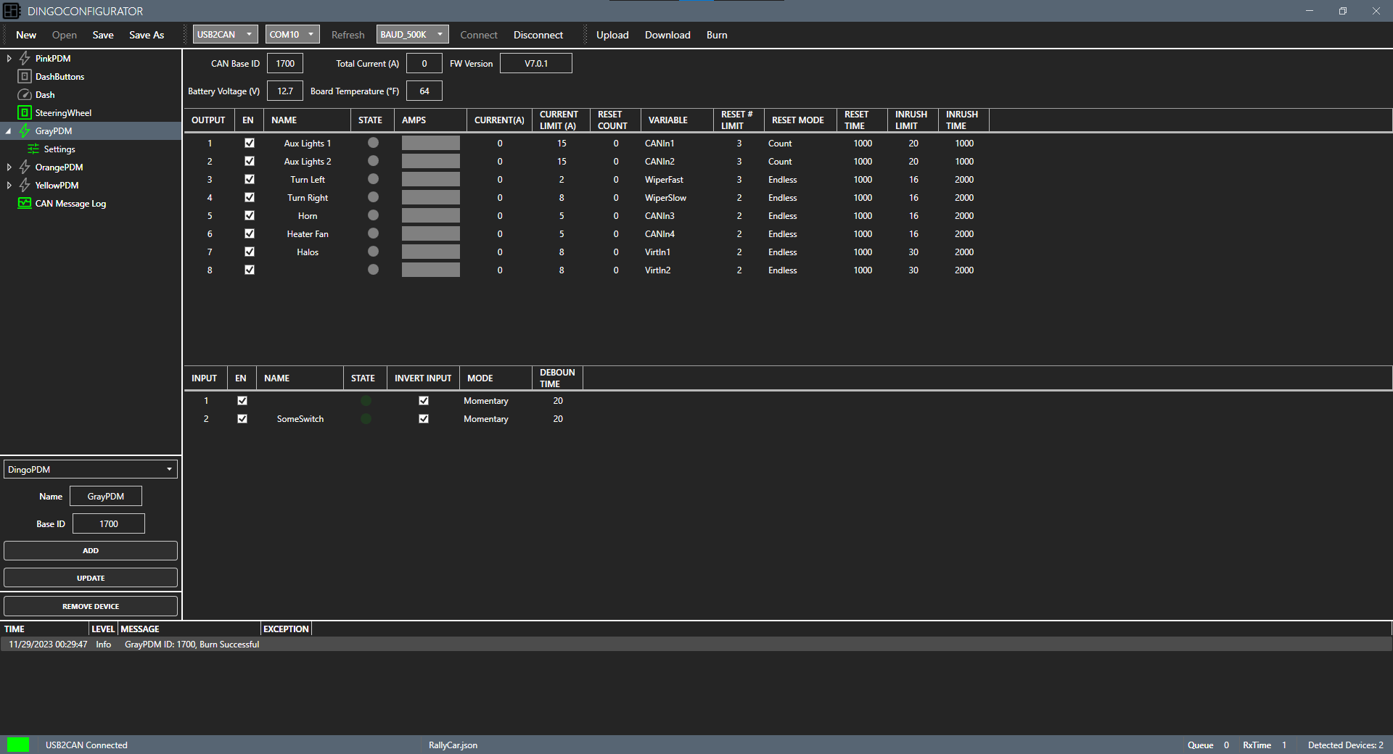
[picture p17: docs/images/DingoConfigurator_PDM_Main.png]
PDM Main


## Download

The latest version can be downloaded here: [DingoConfigurator](https://github.com/corygrant/DingoConfigurator/releases)

## Installation

!!!Info
    The installer has not been built yet.

    First install [STM32CubeProgrammer](https://www.st.com/en/development-tools/stm32cubeprog.html) 

    Download the `.zip` from the link above, unzip and run `DingoConfigurator.exe`

## Supported Devices

DingoConfigurator currently supports these devices:

| Manufacturer | Device |
| --- | --- |
| Dingo Electronics | [dingoPDM](https://github.com/corygrant/dingoPDM) |
| Dingo Electronics | [CANBoard](https://github.com/corygrant/CANBoard_HW)  |

!!! Note
    New devices can/will be added when I have access to the hardware 

## Supported CAN Interfaces

DingoConfigurator currently supports these CAN interfaces.

| Manufacturer | Device |
| --- | --- |
| Dingo Electronics | [USB2CAN](https://github.com/corygrant/USB2CAN_HW) |
| PEAK-System | [PCAN-USB](https://www.peak-system.com/PCAN-USB.199.0.html?&L=1)  |

!!! Note
    New devices can/will be added when I have access to the hardware 

## Sections

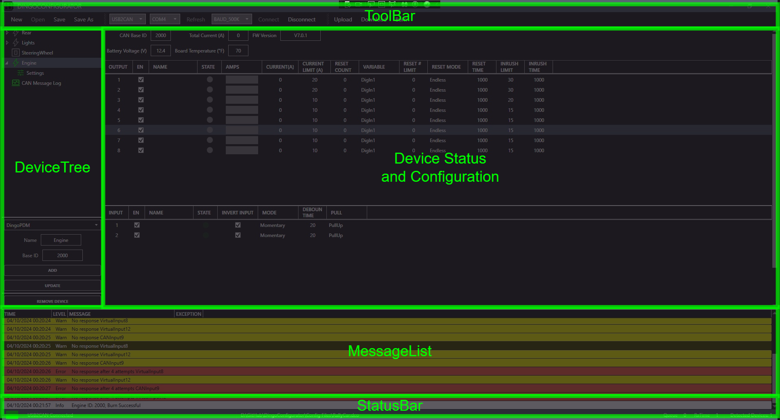
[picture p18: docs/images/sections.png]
PDM Sections


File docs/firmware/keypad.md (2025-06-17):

## Introduction

dingoPDM supports up to 2 CANopen keypads per device as the keypad CANopen master node. 
 
As the keypads CANopen master node dingoPDM will:

- Send the start transmitting message
- Set the backlight color
- Set the button colors or LEDs

Each keypad needs only 1 CANopen master node. 

Additional keypad CANopen messages can be configured as CAN inputs without needing to be the CANopen master node. 

### Models

!!! Warning
    Only CANopen keypads are currently supported

- :green_square: : Tested
- :yellow_square: : Supported, Untested
- :blue_square: : Supported in the future
- :red_square: : Unsupported
  
| Brand | Model | Protocol  | Status |
| :--- | :--- | :--- | :---: |
| `Blink Marine` | `PKP-1600-SI` | `CANopen` | :yellow_square: |
| `Blink Marine` | `PKP-2200-SI` | `CANopen` | :yellow_square: |
| `Blink Marine` | `PKP-2300-SI` | `CANopen` | :yellow_square: |
| `Blink Marine` | `PKP-2400-SI` | `CANopen` | :yellow_square: |
| `Blink Marine` | `PKP-2500-SI` | `CANopen` | :yellow_square: |
| `Blink Marine` | `PKP-2600-SI` | `CANopen` | :green_square:  |
| `Blink Marine` | `PKP-3500-SI` | `CANopen` | :yellow_square: |
| `Blink Marine` | `PKP-3500-SI-MT` | `CANopen` | :yellow_square: |
| `Blink Marine` | `PKP-1200-LI` | `CANopen` | :yellow_square: |
| `Blink Marine` | `PKP-1500-LI` | `CANopen` | :yellow_square: |
| `Blink Marine` | `PKP-2200-LI` | `CANopen` | :yellow_square: |
| `Blink Marine` | `PKP-2400-LI` | `CANopen` | :yellow_square: |

!!! Note
    If you've tested one of the :yellow_square: marked models above please let me know

## Initial Setup

### Setting Node ID

### Setting Transmit Rate

## Blink Marine

### Backlight

### Button Backlight

### Dial

## Grayhill

### Button LEDs

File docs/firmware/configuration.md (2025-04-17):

## Introduction

To enable changes to the dingoPDM configuration and to persist those changes across a power cycle dingoPDM uses a configuration struct that is read from and written to FRAM over I2C. 

## Read

When dingoPDM is powered on, the first thing it does after initializing ChibiOS and I2C is read the configuration from FRAM over I2C. 

Read sequence:

1. Check the FRAM I2C communication and chip IDs (manufacturer and product ID)
2. Read the configuration starting at address 0
3. Check the version number stored in the configuration matches the current configuration
4. Read the configuration checksum stored at the memory address immediatley following the end of the configuration
5. Calculate the configuration checksum for the current configuration read from FRAM
6. Verify that the checksum stored in FRAM matches the one calculated from the configuration stored in FRAM
7. Continue intialization

## Updating

The values of the dingoPDM configuration are updated using CAN or USB messages. 

The format of these messages can be found in [CAN](./can.md)

There is no special mode required to update configuration values, update settings messages can be sent at any time (besides a fatal error state). 

!!! Note
    When a value is updated using a CAN or USB the value is immediately changed in the dingoPDM firmware

    But, the value will not persist over a power cycle

    To keep the updated value send a Burn message to write the new configuration to FRAM

## Write

To reduce the number of writes to FRAM the configuration is not written to FRAM on configuration changes. 

The updated value is immediately changed in the dingoPDM firmware but a Burn message must be received to write the new configuration to FRAM

The [Burn](./can.md#burn) message is the only way to trigger a write of the current configuration. 

Write sequence:

1. Check the FRAM I2C communication and chip IDs (manufacturer and product ID)
2. Write the configuration starting at address 0
3. Calculate the checksum of the current configuration
4. Write the checksum to the memory address immediatley following the end of the configuration
5. Send the write result out on the Burn response message (0 = fail, 1 = success)
    
## Read Failure

If checking I2C communication and chip IDs fails dingoPDM enters the fatal error state and will not go into run.

If any of the other read steps fail:

- Check for I2C errors
    - Errors = true, go to the fatal error state
- Write the firmware default configuration to FRAM
    - If this fails, check for I2C errors again:
        - Errors = true, go to the fatal error state
    - If this succeeds, go to the fatal error state

!!! Info
    Writing the firmware default configuration on a failure allows dingoPDM to recover from a firmware configuration change. 

    Some firmware updates include a change to the configuration struct which means the configuration stored in FRAM no longer matches what the firmware expects.

    On the next power cycle, FRAM will contain the correct memory values and will pass the version and CRC checks but the configuration will be the default blank configuration.

    Write the new desired configuration with the updated format to the dingoPDM using DingoConfigurator.

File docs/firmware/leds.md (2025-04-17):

## `V` - Power

The Power LED, `V` on the case, indicates that the 3.3V power is on. 

!!! Tip
    To reduce power consumption, this LED can be disabled by cutting a jumper on the PCB.

    To restore the LED, the jumper can be bridged with solder. 

## `S` - Status

The Status LED, 'S' on the case, is used to indicate the status of the device. 

## `E` - Error

The Error LED, 'E' on the case, is used to indicate an error on the device. 

See [Error State](./errors.md) for more information. 

## States

- :black_large_square: : LED Off
- :green_square: or :red_square: : LED On
- :green_square: :fontawesome-solid-burst: or :red_square: :fontawesome-solid-burst: : LED Blinking
- :red_square: :fontawesome-solid-burst::octicons-number-24: : LED Blinking Code

| V | S | E | State | Description |
| :---: | :---: | :---: | :---: | :--- |
| :black_large_square: | :black_large_square: | :black_large_square: | | Power off or power not ok. Check power input |
| :green_square: | :black_large_square: | :black_large_square: |  `Sleep` | Device sleep |
| :green_square: | :green_square: | :black_large_square: | `Run` | Device operating properly |
| :green_square: | :green_square: :fontawesome-solid-burst: | :black_large_square: | `Run` | Output overcurrent detected |
| :green_square: | :green_square: :fontawesome-solid-burst: | :red_square: | `Run` | Output overcurrent count limit reached |
| :green_square: | :green_square: :fontawesome-solid-burst: | :red_square:  :fontawesome-solid-burst: | `Overtemp` | Device overtemp reached (State=`Overtemp`) |
| :green_square: | :black_large_square: | :red_square: :fontawesome-solid-burst::octicons-number-24: |  `Error` | Blink error number, see [Error State](./errors.md) |

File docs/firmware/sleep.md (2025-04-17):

Sleep state will be be entered when these conditions are met:

- No USB connected
- No CAN traffic for 30 seconds
- No outputs on for 30 seconds

Sleep state can be exited by one of these Wake inputs:

- Any CAN traffic
- Digital Input changing state
- USB cable connected

!!!Tip
    To further reduce power consumption, the power LED can be disabled by cutting the solder bridge near the LED

!!!Note "v7.2 Hardware"
    v7.2 hardware does not have the power LED solder bridge or CAN disable pin connected.

    To further reduce consumption, the LED or resistor must be de-soldered. 

    A jumper wire can be added between E3 test pad and the CAN transceiver pin 8 (Rs)

Test results

- :green_square: : Enabled
- :red_square: : Disabled
- :yellow_square: : Requires modification

| State | LED | CAN Transceiver | Current (@12V) | v7.2 HW |
| --- | --- | ---  | --- | --- |
| Run (no outputs) | :green_square: | :green_square:  | 40-50mA | :green_square:  |
| Run (no outputs) | :red_square: | :green_square:  | 35-45mA | :yellow_square: |
| Sleep | :green_square: | :green_square:  | 17mA | :green_square:  |
| Sleep | :red_square: | :green_square:  | 13mA | :yellow_square: |
| Sleep | :green_square: | :red_square: | 8mA | :yellow_square: |
| Sleep | :red_square: | :red_square: | 6mA | :yellow_square: |

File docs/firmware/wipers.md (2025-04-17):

# Functionality

dingoPDM includes the ability to control a simple DC wiper motor. 

## Wiring

To wire the wiper motor to the dingoPDM, a [WiperModule](https://dingo-electronics.square.site/product/wipermodule/4) or similar relay setup is required. 

The relays are used to correctly isolate the slow and fast motor windings. 

See [Wiper Connections](../hardware/connections.md#wipers) for more information. 

## Outputs

To control the wiper motor, dingoPDM uses 2 outputs. 

These outputs are available in the var map and can be set to any outputs. 

- Slow output
- Fast output

## Inputs

### Park Switch

To correctly control the wiper motor, dingoPDM requires 1 input to be wired to the park switch of the wiper motor. 

The parked position logic level can be changed using the `Park Stop Level` setting.

### Slow In

- Slow input = true
    - Wiper motor runs at slow speed
- Slow input = false
    - Motor moves to the park position. 

### Fast In

- Fast input = true
    - Wiper motor runs at fast speed
- Fast input = false
    - Motor moves to the park position. 

### Intermittent In

When the intermittent input is true, the wiper motor runs at slow speed and pauses at the end of every cycle. After the pause is elapsed, the motor does another cycle and repeats. 

The intermittent time can be set as a fixed value or a variable value depending on the [mode](#modes). 

### Wash In

On the rising edge of the wash input the wiper motor runs at slow speed (unless previously running at fast speed). 

When the input goes false, the wiper motor continues to run for the number of cycles set in Wash/Wipe cycles.

After completing the cycles the wiper motor parks.

!!! Tip
    To control a washer pump motor, use the `Wash In` variable as the output variable for a dingoPDM output wired to the pump motor

### Swipe In

On the rising edge of the swipe input the wiper motor runs at fast speed for one cycle and then parks. 

### Speed In

When in the `IntIn` or `MixIn` mode this numeric input is used to set the speed from the speed map. 

### On in

When in `MixIn` mode the on input controls whether the motor is running or not. 

## Modes

A dingoPDM wiper can be controlled using a few different modes. 

- `DigIn`
- `IntIn`
- `MixIn`

### DigIn

In `DigIn` mode the wiper motor is controlled with simple digital inputs. 

Intermittent pause delay is set the value in `Intermit 1` and is not variable. 

Required inputs:

- `Park In`
- `Slow In`

Optional inputs:

- `Fast In`
- `Inter In`
- `Swipe In`
- `Wash In`

Unused inputs:

- `On In`
- `Speed In`

### IntIn

In `IntIn` mode the wiper motor is controlled using a numeric input value.

This could be a CAN input value or a Counter value. 

The value of the numeric input is mapped to the values set in `Wiper Speed Map`

!!! Example
    - `Speed 0` = `Park`
    - `Speed 1` = `Slow`
    - `Speed 2` = `Fast`
    - `Speed 3` = `Inter1`
    - `Speed 4` = `Inter2`
    - `Speed 5` = `Inter3`
    - `Speed 6` = `Inter4`
    - `Speed 7` = `Inter5`

      `Speed In` value sets motor to:

      - `Speed In` = 2
          - `Fast`
      - `Speed In` = 5
          - `Intermittent` with a delay of `Intermit 3`

The numeric input value can be any value between 0 and 7, all values do not have to be provided.

>Note: One value must always be `Park` or the motor will never stop

Required inputs:

- `Park In`
- `Speed In`

Optional inputs:

- `Swipe In`
- `Wash In`

Unused inputs:

- `Slow In`
- `Fast In`
- `Inter In`
- `On In`

### MixIn

`MixIn` mode is similar to `IntIn` mode but with the addition of `On In`. 

The speed map works the same as `IntIn` mode but `Park` is not required as a possible speed. 

The wiper motor uses the `On In` to control whether the motor is running:

- `On In` = On
    - Motor running
- `On In` = Off
    - Motor parking/parked

Required inputs:

- `Park In`
- `Speed In`
- `On In`

Optional inputs:

- `Swipe In`
- `Wash In`

Unused inputs:

- `Slow In`
- `Fast In`
- `Inter In`

## States

dingoPDM wipers can be in one of these states:

- `Parked`
    - At the park position
    - Waiting for inputs to change state
    - Slow = off
    - Fast = off
- `Parking`
    - Inputs off, moving to the park position
    - Outputs = previous state (slow or fast)
- `Slow`
    - Slow input on
    - Slow = on
    - Fast = off
- `Fast`
    - Fast input on
    - Slow = off
    - Fast = on
- `IntermittentPause`
    - Intermittent input on
    - At the park position
    - Waiting for intermittent delay to expire
    - Slow = off
    - Fast = off
- `IntermittentOn`
    - Intermittent input on
    - Motor moving at slow speed
    - Slow = on
    - Fast = off
- `Wash`
    - Wash input on or (off and wipes not complete)
    - Outputs = previous state (slow or fast)
- `Swipe`
    - Swipe input on
    - Motor moving at fast speed
    - Slow = off
    - Fast = on

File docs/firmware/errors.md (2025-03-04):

## Error State

The device will enter an error state when a non-recoverable issue occurs.

A [message](./can.md#messages) will be sent over CAN and/or USB and the [Error LED](./leds.md#e---error) will flash the error number. 

!!! Warning
    The only way to reset from an error is to cycle power on the device. 

## Error Numbers

| Error # | Description |
|:---:|---|
| 1 | Watchdog |
| 2 | Message Queue |
| 3 | Task |
| 4 | Configuration |
| 5 | FRAM |
| 6 | ADC |
| 7 | Temperature Sensor |
| 8 | USB |
| 9 | CAN |
| 10 | CRC |
| 11 | I2C |
| 12 | RCC |
| 13 | Temperature |
| 14 | PWM |

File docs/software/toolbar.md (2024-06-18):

ToolBar

The ToolBar is divided into 3 sections:

* [File Operations](./toolbar.md#file-operations)

* [Interface Connection](./toolbar.md#interface-connection)

* [Settings Communication](./toolbar.md#settings-communication)

!!! Note
    The sections of the ToolBar can be rearranged by dragging the sections using the handle on the left of each section

## Keyboard Shortcuts

| Function | Key |
| --- | ---  |
| New | ++ctrl+n++ |
| Open | ++ctrl+o++ |
| Save | ++ctrl+s++ |
| Connect | ++ctrl+c++ |
| Disconnect | ++ctrl+d++ |
| Read | ++ctrl+r++ |
| Write | ++ctrl+w++ |
| Burn | ++ctrl+b++ |

## File Operations

DingoConfigurator uses standard `JSON` configuration files with the extension `.dco`. 

The modified extension enables setting the Windows default app to DingoConfigurator.

!!! warning
    Do not edit the `.dco` file outside of DingoConfigurator unless you are familiar with `JSON`. 

    Errors will make the file unusable with DingoConfigurator. 

### New

`New` clears the current configuration.

No file is created, just a new clean configuration. 

After adding new devices, press `Save As` to save the new `.dco` file. 

!!! warning
    Save the current configuration before pressing `New` to prevent losing the current configuration settings

### Open

`Open` launches a file dialog to select a `.dco` file. 

The directory will repeat to the same directory as previously used after the first use. 

!!! warning
    `Open` clears the current configuration, `Save` before pressing `Open` to prevent losing the current configuration settings

### Save

`Save` saves the `.dco` file after an `Open` or `Save As`

### Save As

`Save As` saves a new `.dco` file from a new configuration or saves a copy of an existing configuration

## Interface Connection

### Interfaces

Select the interface to connect to the devices. 

Currently supported interfaces:

| Interface |
| --------  |
| USB2CAN   |
| PCAN      |
| USB       |

!!! Note
    USB only allows connection to one device at a time, versus CAN which connects to all devices on the bus

### Port

Select the COM port to use with the selected interface, if required. 

`PCAN` does not require a COM port, therefore the port selection is disabled when `PCAN` is selected.

### Refresh

`Refresh` updates the `Port` selection with the current list of available COM ports. 

### Baud

Select the required CAN baud rate. 

`USB` does not require a baud rate, therefore the baud rate selection is disabled when `USB` is selected. 

### Connect

`Connect` opens a connection to the interface device.

After a successful connection, the StatusBar at the bottom of the window should update with a green box and the name of the interface followed by "Connected".

The StatusBar will also update with the number of Detected Devices in the bottom right. 

!!! Tip
    The Detected Devices count means messages in the range of the configured devices are being received.

    For each device the count is increased by 1 

### Disconnect

`Disconnect` closes the currently open connection. 

## Settings Communication

The `Settings Communication` section of the ToolBar enables uploading, downloading and burning the configuration to the currently selected Device. 

!!! Tip
    To enable the buttons, select a device in the DeviceTree. 

!!! Note
    Some devices do not support settings communication, therefore the buttons are disabled. 

### Read

`Read` reads the settings from the selected device and updates the current configuration. 

!!! Warning
    `Read` will overwrite the current configuration settings for the selected device

### Write 

`Write` sends the current configuration to the selected device. 

### Burn

`Burn` sends a burn command to the selected device. 

This command tells the device to write the current configuration to non-volatile memory. 

!!! Danger
    If a `Burn` is not performed after a `Download` the current configuration in the device will be lost on a power cycle

### Sleep/Wake

`Sleep` sends a sleep command to the selected device. 

This command immediately sets the device to sleep state. 

`Wake` sends a wake command to the selected device.

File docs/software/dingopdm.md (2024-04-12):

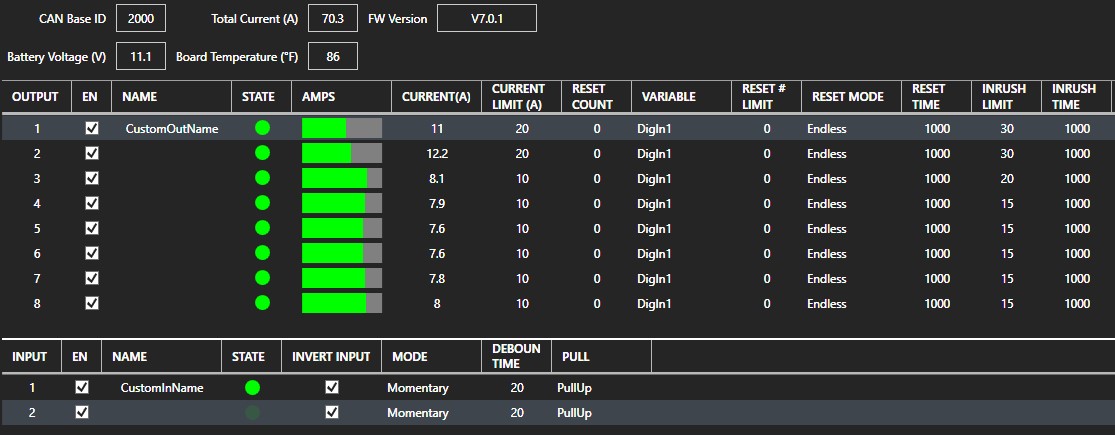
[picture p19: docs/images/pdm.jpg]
dingoPDM


## Settings

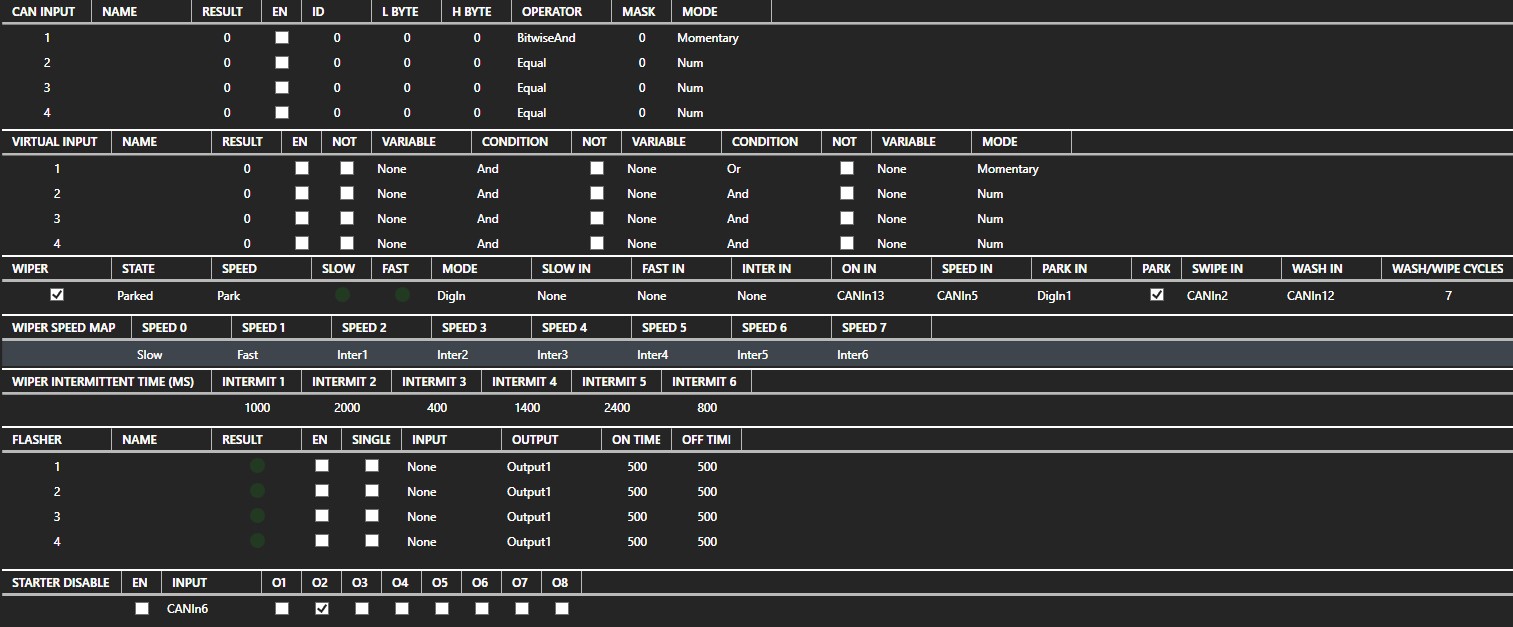
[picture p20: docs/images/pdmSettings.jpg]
dingoPDMsettings


## CAN Input

### Enable

The CAN Input is enabled and evaluated in the device. 
Setting the unused inputs to not enabled reduces the amount of processing time on the device. 

### ID

### Low Byte

### High Byte

### Operator

### Mask

### Mode

### Examples

## Virtual Input

### Enable

The Virtual Input is enabled and evaluated in the device. 
Setting the unused inputs to not enabled reduces the amount of processing time on the device. 

### Not

### Variable

### Condition

### Mode

### Examples

## WiperModule

To control a wiper motor directly from dingoPDM a WiperModule is required. 
The WiperModule uses 3 relays to properly control the slow, fast and brake functions of a wiper motor. 
The internal connections are made based on the slow input (which also supplies all power to the motor) and the fast input. 
The ground and park signals are passed through the module. 

Information about the WiperModule can be found here: [WiperModule](https://github.com/corygrant/WiperModule)

WiperModuleConnections
WiperModuleConnections

## Wiper

### Enable

The Wiper is enabled and evaluated in the device. 
Setting the unused Wiper to not enabled reduces the amount of processing time on the device. 

### State

### Speed

### Slow

### Fast

### Mode

### Slow In

### Fast in

### Intermittent In

### On In

### Speed In

### Park In

### Park Stop Level

### Swipe In

### Wash In

### Wash/Wipe Cycles

## Wiper Speed Map

### Speed 0-7

## Wiper Intermittent Time

### Intermittent Time 1- 6

## Flasher

### Enable

The Flasher is enabled and evaluated in the device. 
Setting the unused Flahser to not enabled reduces the amount of processing time on the device. 

### Single

### Input

### Output

### On Time

### Off Time

## Starter Disable

### Enable

The Starter Disable is enabled and evaluated in the device. 
Setting the unused Starter Disable to not enabled reduces the amount of processing time on the device. 

### Input

### O1-8

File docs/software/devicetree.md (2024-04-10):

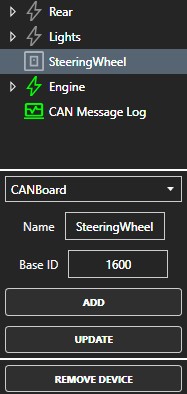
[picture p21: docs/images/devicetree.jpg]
DeviceTree


The DeviceTree is divided into 2 sections:

* `DeviceTree`

* `Device Management`

## DeviceTree

### Icons

Each device type has a different icon in the DeviceTree. 

When the device is detected the icon change from gray to green. 

| Device Type | Icon |
| --- | --- |
| dingoPDM | dingoPDM |
| CANBoard | CANBoard |
| CANMsgLog | CANMsgLog |

!!! Note
    Devices are considered detected when CAN messages are received in their ID range based on the `Base ID`

### Device Order

The order of devices in the DeviceTree is based on the `Base ID`.

The lowest `Base ID` are shown at the top. 

`CANMsgLog` always has a `Base ID` value of `9999`, making sure it is always at the bottom.

## Device Management

### Type

Select the `Type` of device to add. 

### Name

Set or edit the `Name` of the device in the DeviceTree.

### Base ID

Set or edit the `Base ID` of the device. 

!!! Info
    Currently `Base ID` must be within the 11 bit range of the standard CAN ID (0-2048)

### Add

`Add` a new device to the DeviceTree with the `Name` and `Base ID` as set.

### Update

`Update` the `Name` and/or `Base ID` values of the selected device in the DeviceTree.

### Remove

`Remove` the selected device from the DeviceTree.

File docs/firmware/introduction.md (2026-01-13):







!!! bug
    Firmware documentation is a work in progress

dingoPDM uses [ChibiOS](https://www.chibios.org/dokuwiki/doku.php) RTOS 

Chibi

dingoPDM and dingoPDM-Max both use the same firmware, with only a variable change during build.

## Download

The latest version can be downloaded here: [DingoPDM_FW](https://github.com/corygrant/DingoPDM_FW/releases)

## Update

See [Updating](./updating.md) for firmware updating instructions

## Build

To build dingoPDM firmware on your machine refer to [Build](./build.md)

## Custom PCB Firmware

dingoPDM firmware was designed to be easily modified to work on custom PCBs with varying numbers of outputs and inputs. 

See [Customization](./custom.md) for information on customizing dingoPDM firmware to match your custom hardware.

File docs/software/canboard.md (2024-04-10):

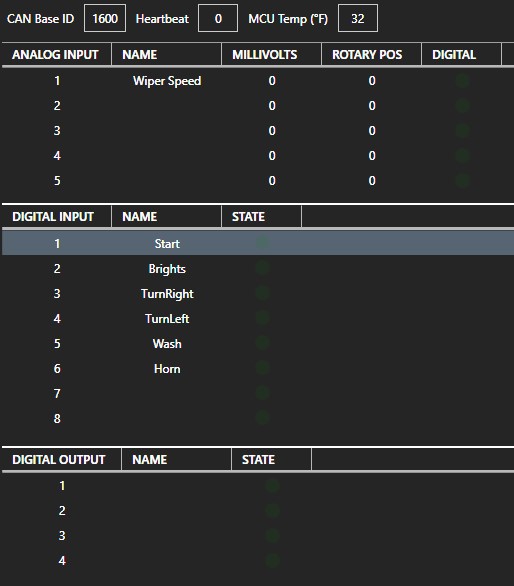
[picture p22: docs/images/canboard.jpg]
CANBoard


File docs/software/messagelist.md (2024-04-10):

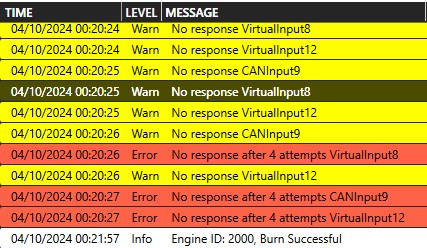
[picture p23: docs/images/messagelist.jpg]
MessageList


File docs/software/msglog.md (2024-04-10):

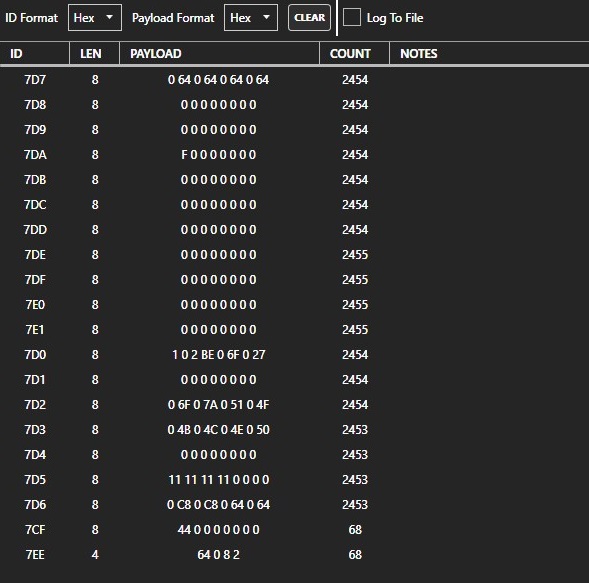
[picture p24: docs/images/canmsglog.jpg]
msglog


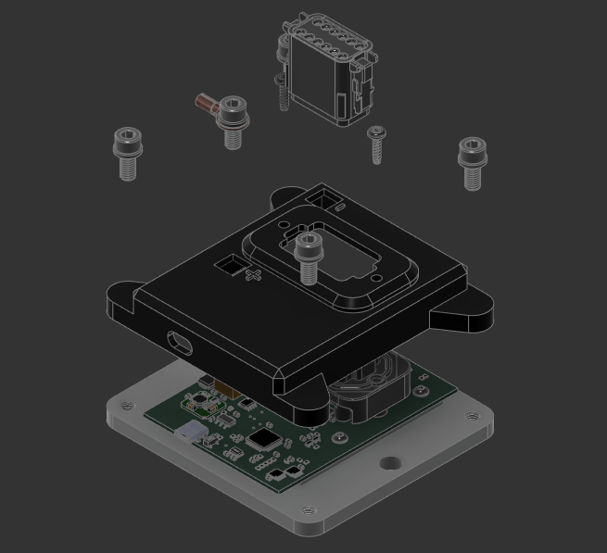
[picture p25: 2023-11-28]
docs/images/DingoPDM_Case_Explode.png

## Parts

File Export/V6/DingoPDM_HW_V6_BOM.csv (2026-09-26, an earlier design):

Reference | Value | Footprint | Digi-Key_PN | LCSC | Qty
C1 | 100nF | Capacitor_SMD:C_0805_2012Metric | 478-1395-1-ND | C49678 | 1
C2 | 100nF | Capacitor_SMD:C_0805_2012Metric | 478-1395-1-ND | C49678 | 1
C3 | 10uF | Capacitor_SMD:C_0805_2012Metric | 445-11516-1-ND | C15850 | 1
C4 | 22uF | Capacitor_SMD:C_0805_2012Metric | 490-10749-1-ND | C45783 | 1
C5 | 100nF | Capacitor_SMD:C_0805_2012Metric | 478-1395-1-ND | C49678 | 1
C6 | 10uF | Capacitor_SMD:C_0805_2012Metric | 445-11516-1-ND | C15850 | 1
C7 | 27pF | Capacitor_SMD:C_0805_2012Metric | 478-10518-1-ND | C1808 | 1
C8 | 27pF | Capacitor_SMD:C_0805_2012Metric | 478-10518-1-ND | C1808 | 1
C9 | 100nF | Capacitor_SMD:C_0805_2012Metric | 478-1395-1-ND | C49678 | 1
C11 | 100nF | Capacitor_SMD:C_0805_2012Metric | 478-1395-1-ND | C49678 | 1
C12 | 100nF | Capacitor_SMD:C_0805_2012Metric | 478-1395-1-ND | C49678 | 1
C13 | 100nF | Capacitor_SMD:C_0805_2012Metric | 478-1395-1-ND | C49678 | 1
C14 | 4.7uF | Capacitor_SMD:C_0805_2012Metric | 1276-2873-1-ND | C1779 | 1
C15 | 10nF | Capacitor_SMD:C_0805_2012Metric | 311-1136-1-ND | C1710 | 1
C16 | 1uF | Capacitor_SMD:C_0805_2012Metric | 311-1365-1-ND | C28323 | 1
C17 | 100nF | Capacitor_SMD:C_0805_2012Metric | 478-1395-1-ND | C49678 | 1
C18 | 1uF | Capacitor_SMD:C_0805_2012Metric | 311-1365-1-ND | C28323 | 1
C19 | 10nF | Capacitor_SMD:C_0805_2012Metric | 311-1136-1-ND | C1710 | 1
C20 | 10nF | Capacitor_SMD:C_0805_2012Metric | 311-1136-1-ND | C1710 | 1
C21 | 100nF | Capacitor_SMD:C_0805_2012Metric | 478-1395-1-ND | C49678 | 1
C22 | 47nF | Capacitor_SMD:C_0805_2012Metric | 399-1166-1-ND | C520039 | 1
C23 | 100nF | Capacitor_SMD:C_0805_2012Metric | 478-1395-1-ND | C49678 | 1
C24 | 10nF | Capacitor_SMD:C_0805_2012Metric | 311-1136-1-ND | C1710 | 1
C25 | 220pF | Capacitor_SMD:C_0805_2012Metric | 399-1138-1-ND | C576920 | 1
C26 | 47nF | Capacitor_SMD:C_0805_2012Metric | 399-1166-1-ND | C520039 | 1
C27 | 100nF | Capacitor_SMD:C_0805_2012Metric | 478-1395-1-ND | C49678 | 1
C28 | 10nF | Capacitor_SMD:C_0805_2012Metric | 311-1136-1-ND | C1710 | 1
C29 | 220pF | Capacitor_SMD:C_0805_2012Metric | 399-1138-1-ND | C576920 | 1
C30 | 47nF | Capacitor_SMD:C_0805_2012Metric | 399-1166-1-ND | C520039 | 1
C31 | 100nF | Capacitor_SMD:C_0805_2012Metric | 478-1395-1-ND | C49678 | 1
C32 | 220pF | Capacitor_SMD:C_0805_2012Metric | 399-1138-1-ND | C576920 | 1
D1 | 3.3V | Diode_SMD:D_SOD-323_HandSoldering | 1727-5150-1-ND | C177016 | 1
D2 | SMCJ20CA | digikey-footprints:DO-214AB_TVS | SMCJ20CABCT-ND | C152086 | 1
D3 | GRN | LED_SMD:LED_0805_2012Metric | 475-1410-1-ND | C2899888 | 1
D4 | NUP2105LT1G | digikey-footprints:SOT-23-3 | NUP2105LT1GOSCT-ND | C2976509 | 1
D5 | RED | LED_SMD:LED_0805_2012Metric | 475-1278-1-ND | C2899997 | 1
D6 | BAT54S | Package_TO_SOT_SMD:SOT-23 | BAT54SLT1GOSCT-ND | C47546 | 1
D7 | BAT54S | Package_TO_SOT_SMD:SOT-23 | BAT54SLT1GOSCT-ND | C47546 | 1
D8 | BYG23M | digikey-footprints:DO-214AC | BYG23M-E3/TR3GICT-ND | C141573 | 1
D9 | 3.3V | Diode_SMD:D_SOD-323_HandSoldering | 1727-5150-1-ND | C177016 | 1
D10 | BYG23M | digikey-footprints:DO-214AC | BYG23M-E3/TR3GICT-ND | C141573 | 1
D11 | 3.3V | Diode_SMD:D_SOD-323_HandSoldering | 1727-5150-1-ND | C177016 | 1
D12 | 3.3V | Diode_SMD:D_SOD-323_HandSoldering | 1727-5150-1-ND | C177016 | 1
FB1 | Ferrite_Bead_Small | Resistor_SMD:R_0805_2012Metric | 490-1054-1-ND | C85840 | 1
J1 | RedCubeTerminal | RedCube:M6_Hole_8Pin_7461084 | 732-3203-ND |  | 1
J2 | RedCubeTerminal | RedCube:M6_Hole_8Pin_7461084 | 732-3203-ND |  | 1
J3 | Conn_01x12 | Deutsch_DT:DT15-12PA | 1734-1027-ND |  | 1
R1 | 47k | Resistor_SMD:R_0805_2012Metric | 311-47.0KCRCT-ND | C327035 | 1
R2 | 10k | Resistor_SMD:R_0805_2012Metric | 311-10.0KCRDKR-ND | C17414 | 1
R3 | 120R | Resistor_SMD:R_0805_2012Metric | 311-120CRCT-ND | C229076 | 1
R4 | 10k | Resistor_SMD:R_0805_2012Metric | 311-10.0KCRDKR-ND | C17414 | 1
R5 | 1k | Resistor_SMD:R_0805_2012Metric | 311-1.0KARCT-ND | C17513 | 1
R6 | 10k | Resistor_SMD:R_0805_2012Metric | 311-10.0KCRDKR-ND | C17414 | 1
R7 | 10k | Resistor_SMD:R_0805_2012Metric | 311-10.0KCRDKR-ND | C17414 | 1
R8 | 120R | Resistor_SMD:R_0805_2012Metric | 311-120CRCT-ND | C229076 | 1
R9 | 4.7k | Resistor_SMD:R_0805_2012Metric | 311-4.70KCRCT-ND | C17673 | 1
R10 | 4.7k | Resistor_SMD:R_0805_2012Metric | 311-4.70KCRCT-ND | C17673 | 1
R11 | 1.2k | Resistor_SMD:R_0805_2012Metric | 311-1.20KCRCT-ND | C727987 | 1
R12 | 1.2k | Resistor_SMD:R_0805_2012Metric | 311-1.20KCRCT-ND | C727987 | 1
R13 | 4.7k | Resistor_SMD:R_0805_2012Metric | 311-4.70KCRCT-ND | C17673 | 1
R14 | 4.7k | Resistor_SMD:R_0805_2012Metric | 311-4.70KCRCT-ND | C17673 | 1
R15 | 1.2k | Resistor_SMD:R_0805_2012Metric | 311-1.20KCRCT-ND | C727987 | 1
R16 | 47R 1/4W | Resistor_SMD:R_1206_3216Metric | 311-47.0FRCT-ND | C2907508 | 1
R17 | 4.7k | Resistor_SMD:R_0805_2012Metric | 311-4.70KCRCT-ND | C17673 | 1
R18 | 4.7k | Resistor_SMD:R_0805_2012Metric | 311-4.70KCRCT-ND | C17673 | 1
R19 | 4.7k | Resistor_SMD:R_0805_2012Metric | 311-4.70KCRCT-ND | C17673 | 1
R20 | 4.7k | Resistor_SMD:R_0805_2012Metric | 311-4.70KCRCT-ND | C17673 | 1
R21 | 1.2k | Resistor_SMD:R_0805_2012Metric | 311-1.20KCRCT-ND | C727987 | 1
R22 | 47R 1/4W | Resistor_SMD:R_1206_3216Metric | 311-47.0FRCT-ND | C2907508 | 1
R23 | 4.7k | Resistor_SMD:R_0805_2012Metric | 311-4.70KCRCT-ND | C17673 | 1
R24 | 4.7k | Resistor_SMD:R_0805_2012Metric | 311-4.70KCRCT-ND | C17673 | 1
R25 | 1.2k | Resistor_SMD:R_0805_2012Metric | 311-1.20KCRCT-ND | C727987 | 1
R26 | 4.7k | Resistor_SMD:R_0805_2012Metric | 311-4.70KCRCT-ND | C17673 | 1
R27 | 4.7k | Resistor_SMD:R_0805_2012Metric | 311-4.70KCRCT-ND | C17673 | 1
R28 | 4.7k | Resistor_SMD:R_0805_2012Metric | 311-4.70KCRCT-ND | C17673 | 1
R29 | 4.7k | Resistor_SMD:R_0805_2012Metric | 311-4.70KCRCT-ND | C17673 | 1
R30 | 1.2k | Resistor_SMD:R_0805_2012Metric | 311-1.20KCRCT-ND | C727987 | 1
R31 | 47R 1/4W | Resistor_SMD:R_1206_3216Metric | 311-47.0FRCT-ND | C2907508 | 1
R32 | 4.7k | Resistor_SMD:R_0805_2012Metric | 311-4.70KCRCT-ND | C17673 | 1
R33 | 4.7k | Resistor_SMD:R_0805_2012Metric | 311-4.70KCRCT-ND | C17673 | 1
R34 | 4.7k | Resistor_SMD:R_0805_2012Metric | 311-4.70KCRCT-ND | C17673 | 1
R35 | 4.7k | Resistor_SMD:R_0805_2012Metric | 311-4.70KCRCT-ND | C17673 | 1
R36 | 4.7k | Resistor_SMD:R_0805_2012Metric | 311-4.70KCRCT-ND | C17673 | 1
R37 | 4.7k | Resistor_SMD:R_0805_2012Metric | 311-4.70KCRCT-ND | C17673 | 1
U1 | VXO780x-500-M | CUI_Regulators:VXO78x-500-M | 102-VXO7805-500-M-CT-ND |  | 1
U2 | LD1117S33CTR | digikey-footprints:SOT-223 | 497-1241-1-ND | C35879 | 1
U3 | PCA82C250 | Package_SO:SOIC-8_3.9x4.9mm_P1.27mm | 568-10316-1-ND | C7439 | 1
U4 | STM32F303CCTx | Package_QFP:LQFP-48_7x7mm_P0.5mm | 497-13318-ND | C81523 | 1
U5 | MB85RC256V | Package_SO:SOIC-8_3.9x4.9mm_P1.27mm | 865-1261-1-ND | C47538 | 1
U6 | MCP9808 | Package_SO:MSOP-8_3x3mm_P0.65mm | MCP9808T-E/MSCT-ND | C129490 | 1
U7 | LM324 | Package_SO:TSSOP-14_4.4x5mm_P0.65mm | 497-7330-1-ND | C7944 | 1
U8 | BTS700n-1EPP | Profet:TDSO-14 | BTS70021EPPXUMA1CT-ND | C534824 | 1
U9 | BTS700n-1EPP | Profet:TDSO-14 | BTS70021EPPXUMA1CT-ND | C534824 | 1
U11 | BTS7008-2EPA | Profet:TDSO-14 | BTS70082EPAXUMA1CT-ND | C2150060 | 1
U12 | BTS724G | Package_SO:Infineon_PG-DSO-20-32 | BTS724GXUMA1CT-ND | C82656 | 1
Y1 | 8mHz | Crystals_Modify:Crystal_SMD_5032-2Pin_5.0x3.2mm_HandSoldering | 535-10630-1-ND | C144380 | 1

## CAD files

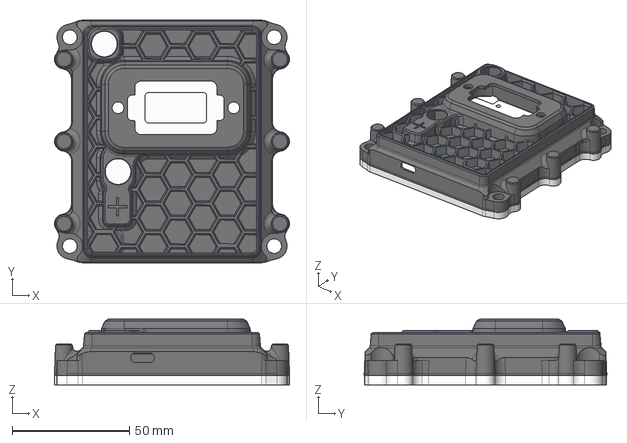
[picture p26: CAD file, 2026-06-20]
Export/V7.5/Case/Enclosure - paleppp/STEP/Case+Baseplate+Heatsink assy.step
100.1 x 103.4 x 28.1 mm

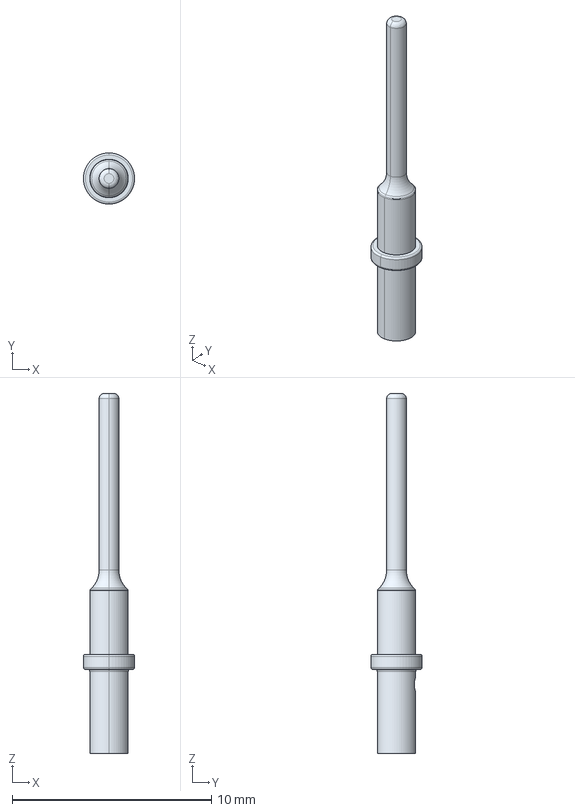
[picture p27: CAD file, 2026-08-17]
DingoPDM/Models/c-0460-202-20141-c-3d.stp
2.57 x 2.57 x 18.1 mm

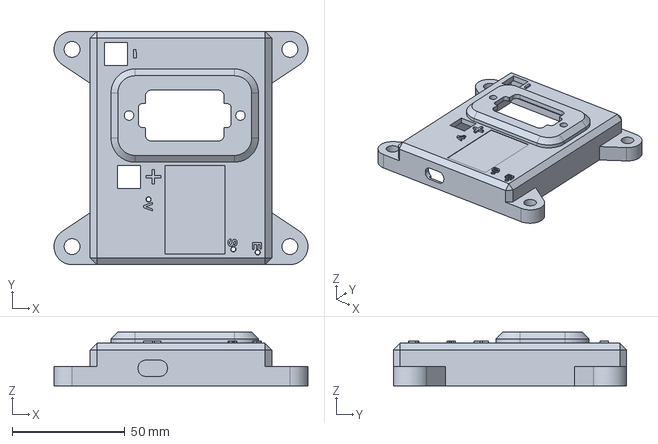
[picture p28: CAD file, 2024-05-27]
Export/V7.5/Case/Case.step
112.4 x 103.3 x 23.9 mm

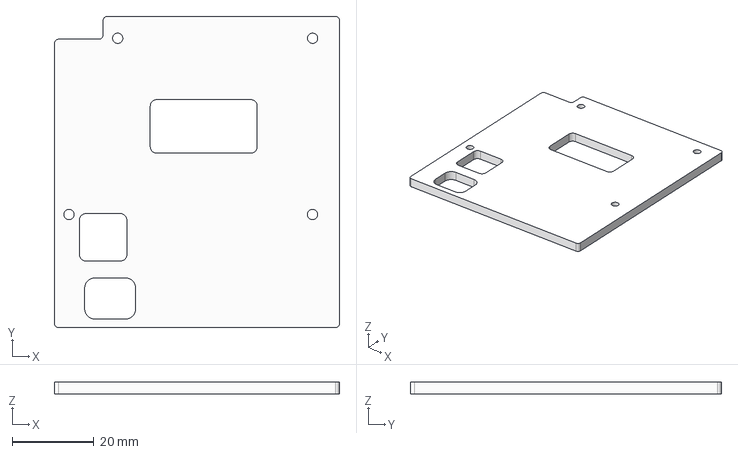
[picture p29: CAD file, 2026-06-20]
Export/V7.5/Case/Enclosure - paleppp/STEP/Heatsink.step
69.8 x 76.2 x 3.00 mm

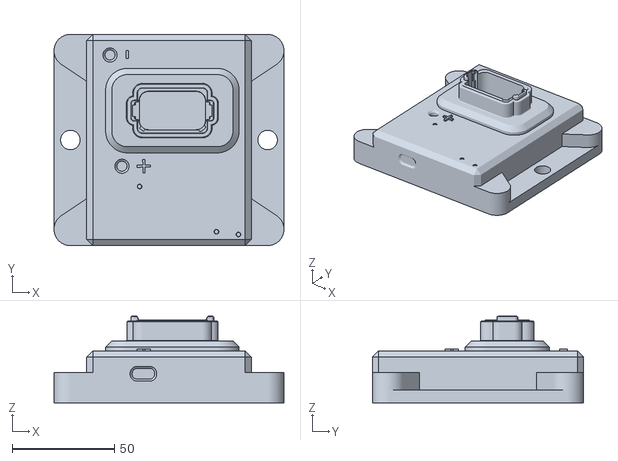
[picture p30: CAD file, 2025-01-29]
Export/V7.5/DingoPDM_V7_WiringAid.stl
112.4 x 103.2 x 42.3

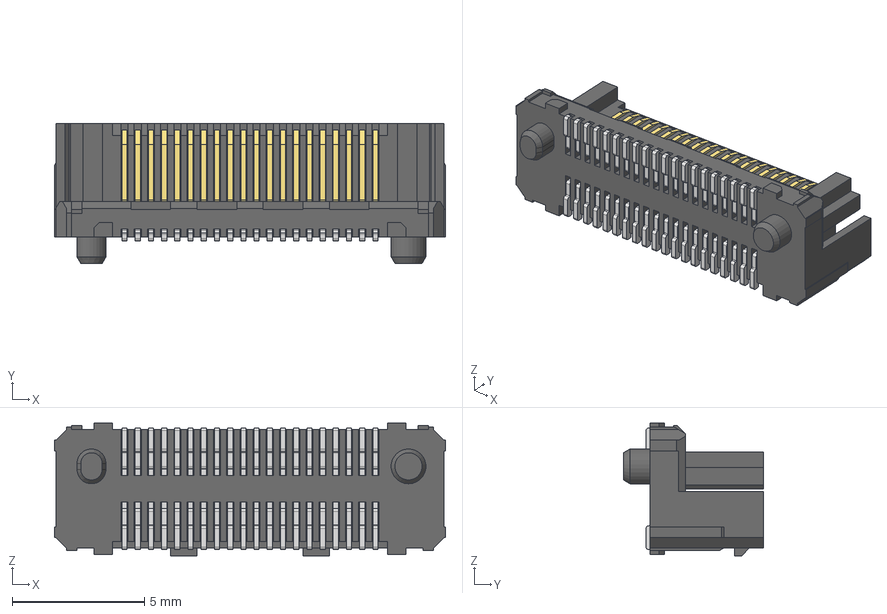
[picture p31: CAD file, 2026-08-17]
DingoPDM/Models/LSHM-120-03.0-L-DV-A-N-K-TR.step
14.8 x 5.30 x 5.03 mm
C-185--20-03.0-DV1P2 L__C-185--20-03.0-DV1P2 L
C-185--20-03.0-L-DV1P__C-185--20-03.0-L-DV1P
LSHM-20-03.0-DV-A-N_STRIP__LSHM-20-03.0-DV-A-N_STRIP

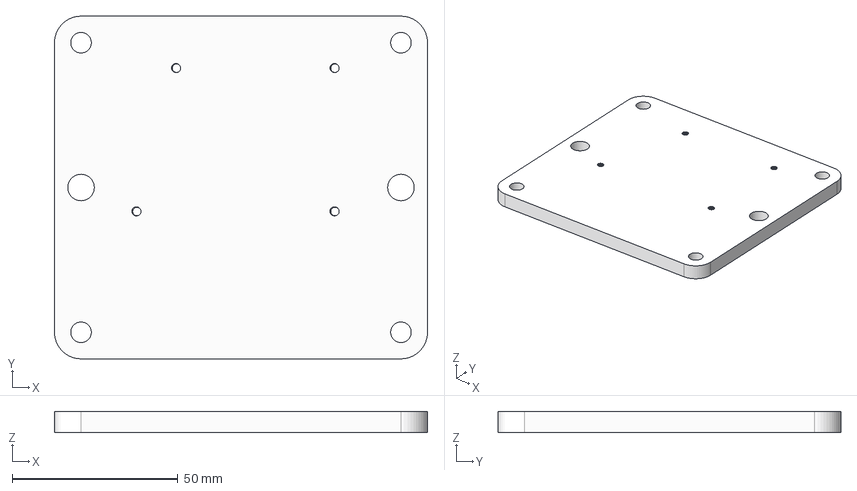
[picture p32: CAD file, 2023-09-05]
Export/V7.5/Case/Baseplate.step
112.4 x 103.2 x 6.35 mm

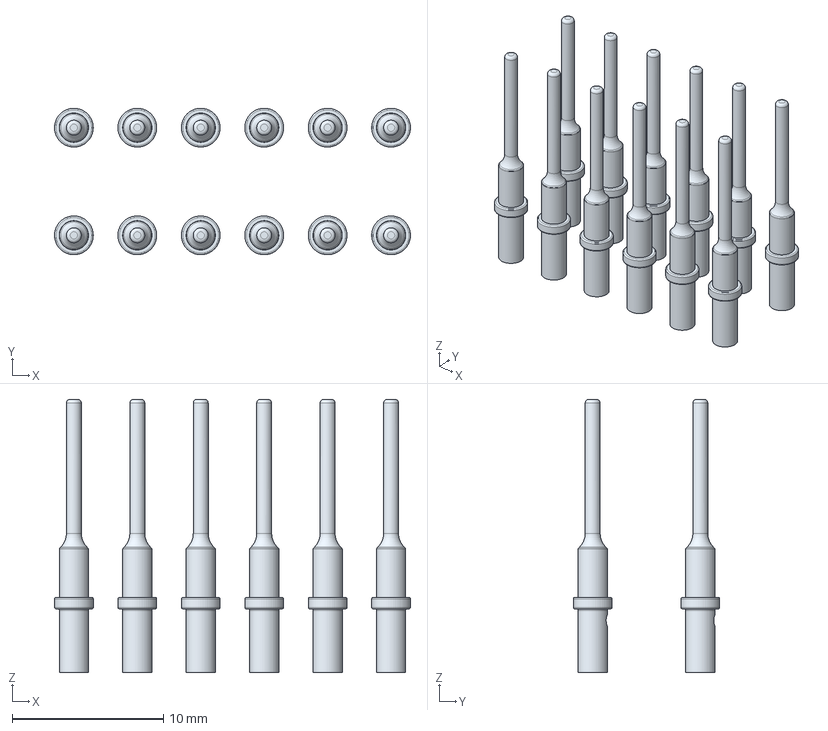
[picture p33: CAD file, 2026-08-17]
DingoPDM/Models/DTM_12Pins.step
23.5 x 9.67 x 18.1 mm

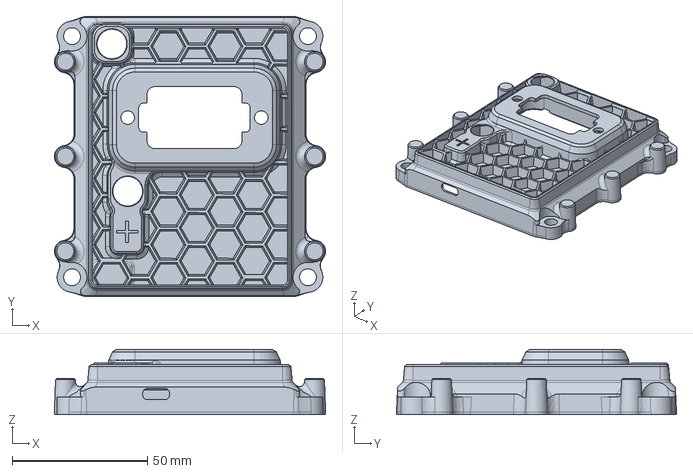
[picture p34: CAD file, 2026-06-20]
Export/V7.5/Case/Enclosure - paleppp/STEP/Case TOP.step
100.1 x 103.4 x 24.1 mm

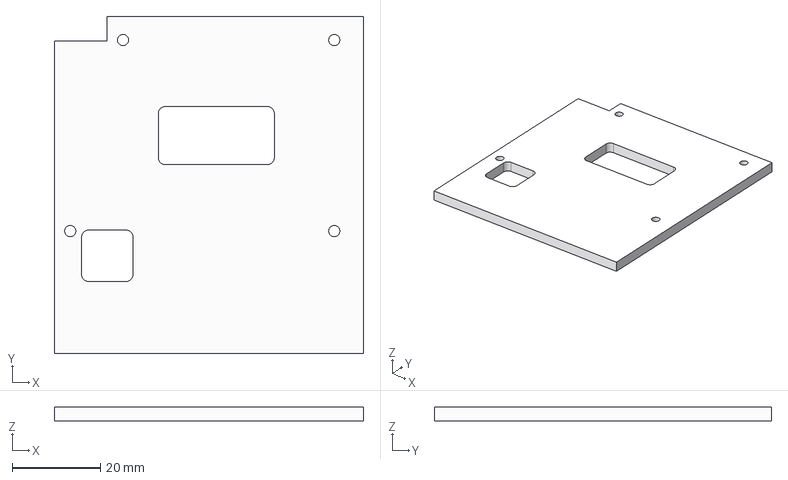
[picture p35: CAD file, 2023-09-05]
Export/V7.5/Case/HeatsinkPlate.step
69.8 x 76.2 x 3.17 mm

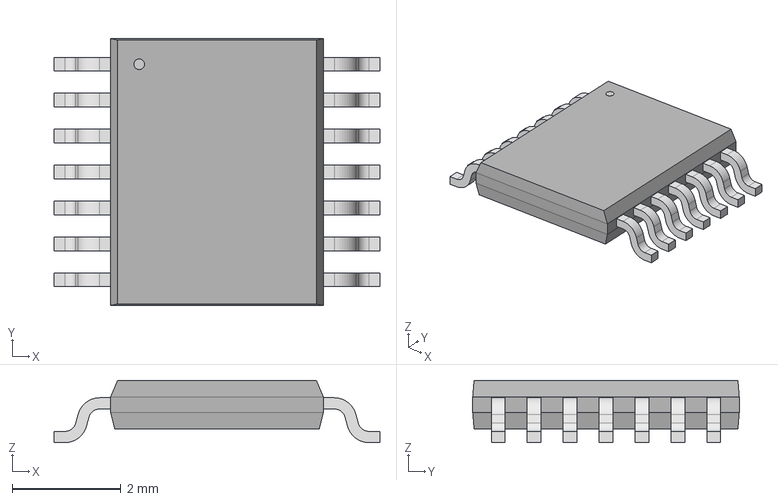
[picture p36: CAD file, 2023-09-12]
DingoPDM/Models/PG-TSDSO-14_INF.step
5.99 x 4.90 x 1.15 mm

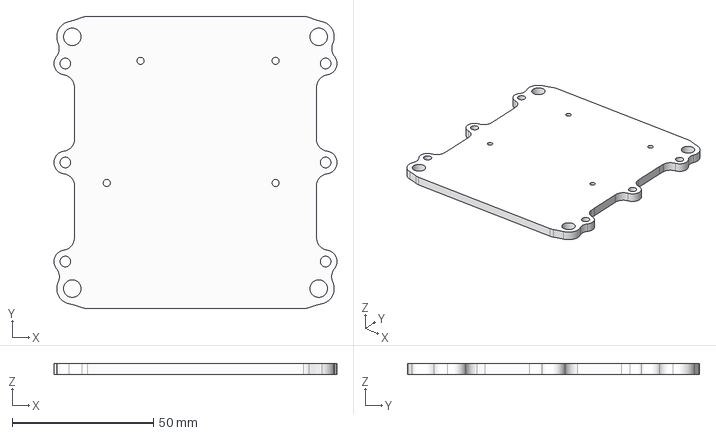
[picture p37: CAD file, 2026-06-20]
Export/V7.5/Case/Enclosure - paleppp/STEP/Baseplate.step
100.0 x 103.3 x 4.00 mm

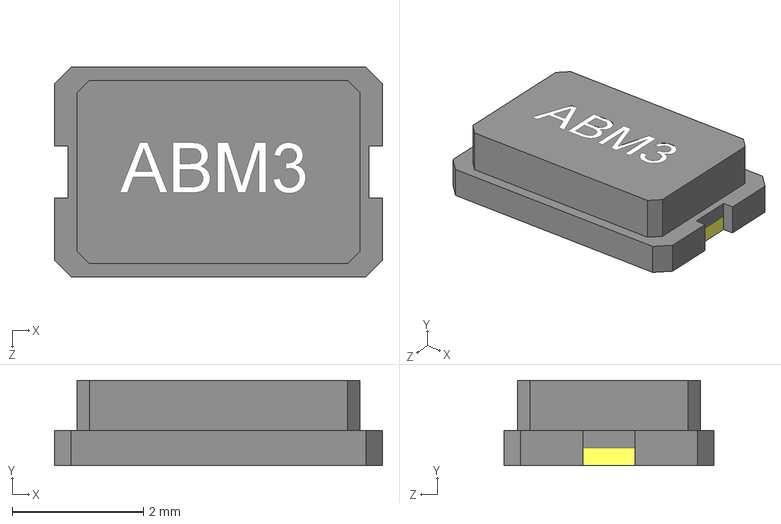
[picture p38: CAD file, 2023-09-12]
DingoPDM/Models/ABM3.STEP
5.00 x 1.30 x 3.20 mm

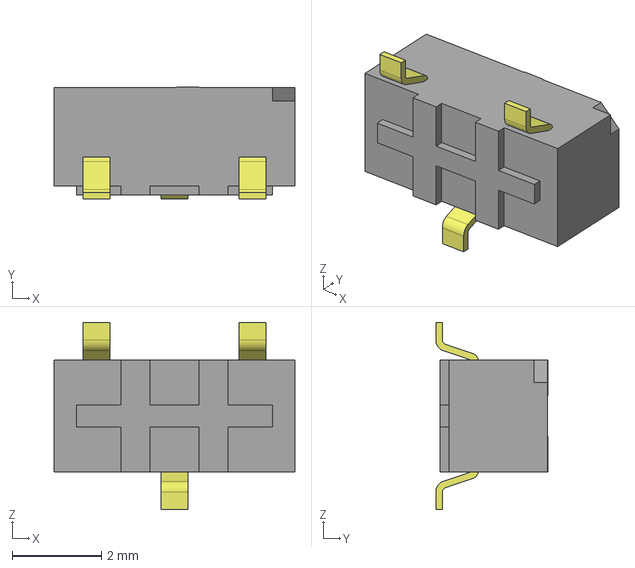
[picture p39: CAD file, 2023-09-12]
DingoPDM/Models/CJS-1200TB.stp
5.40 x 2.52 x 4.20 mm
_CJS_c_12
_CJS Slider_s

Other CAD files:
DingoPDM/Models/User Library-DO-214AC SMA.STEP
DingoPDM/Models/User Library-sot-223.STEP
DingoPDM/Models/USB4085-GF-A--3DModel-STEP-56544.STEP
DingoPDM/Models/c-dt15-12pa-e-3d.stp
DingoPDM/Models/7461084_Download_STP_7461084_rev1.stp
DingoPDM/Models/User Library-DO-214AB SMC.STEP
DingoPDM/Models/User Library-SOT23-3.step
Export/V7.5/Case/Enclosure - paleppp/3MF/Baseplate.3mf
Export/V7.5/Case/Enclosure - paleppp/3MF/Case TOP.3mf
Export/V7.5/Case/Enclosure - paleppp/3MF/Heatsink.3mf
Export/V7.5/Case/Enclosure - paleppp/DXF/Baseplate.dxf
Export/V7.5/Case/Enclosure - paleppp/DXF/Heatsink.dxf

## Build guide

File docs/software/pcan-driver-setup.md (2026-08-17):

# Installing the PEAK PCAN-USB Driver on Linux (with DKMS)

A guide for getting a PEAK-System **PCAN-USB** adapter working on a Debian/Ubuntu/Mint
based Linux machine, and setting it up so it **survives kernel upgrades** automatically.

The PEAK chardev (`pcan`) driver is an out-of-tree kernel module. If you install it with
a plain `make install`, it is compiled against *one specific kernel version*. The next time
your distro installs a new kernel, the module no longer matches and fails to load with an
error like:

```
pcan: disagrees about version of symbol module_layout
```

...and `/dev/pcanusb*` never appears, so tools like `pcanview` can't see the adapter.

Registering the driver with **DKMS** fixes this for good: DKMS automatically recompiles the
module whenever a new kernel is installed.

---

## 1. Prerequisites

Install the build tools, kernel headers for your *running* kernel, and DKMS:

```bash
sudo apt update
sudo apt install build-essential dkms "linux-headers-$(uname -r)"
```

Verify the headers are present (this should print a path, not an error):

```bash
ls -d "/lib/modules/$(uname -r)/build"
```

Plug in the PCAN-USB adapter and confirm the OS sees it on USB:

```bash
lsusb | grep -i peak
# e.g. Bus 005 Device 054: ID 0c72:000c PEAK System PCAN-USB
```

> If `lsusb` doesn't show it, it's a cable/port/hardware problem — fix that first.

---

## 2. Get the driver source

Download the **peak-linux-driver** source tarball from PEAK:
<https://www.peak-system.com/quick/PCAN-Linux-Driver>

Extract it. **IMPORTANT: extract it to a path that contains NO SPACES.**
The Linux kernel build system (kbuild) cannot handle spaces in the module path and the
build will fail with errors like `No rule to make target '.../PEAK'`.

```bash
# Good:
cd ~/Downloads
tar xzf peak-linux-driver-9.0.tar.gz
cd peak-linux-driver-9.0

# Bad (will break the build):
#   ~/Desktop/PEAK Setup/peak-linux-driver-9.0   <-- space in "PEAK Setup"
```

Adjust `9.0` to match the version you downloaded.

---

## 3. (Optional) Quick test build

Before involving DKMS, you can confirm the source compiles against your kernel:

```bash
cd ~/Downloads/peak-linux-driver-9.0
make clean
make
# Check the module matches your running kernel:
modinfo driver/pcan.ko | grep -E 'vermagic|version'
```

The `vermagic:` line must start with your running kernel version
(`uname -r`, e.g. `6.8.0-124-generic`).

---

## 4. Install via DKMS (recommended)

This copies the driver source into the standard DKMS location `/usr/src` and registers it.
With `AUTOINSTALL="yes"` (set in the driver's `dkms.conf`), DKMS will then rebuild the module
automatically on every future kernel upgrade.

Set the version once so the commands below are copy-paste safe:

```bash
VER=9.0   # change to match your downloaded version

# 1. Copy the driver source into the canonical DKMS location
sudo cp -a ~/Downloads/peak-linux-driver-$VER/driver /usr/src/peak-linux-driver-$VER

# 2. Register, build, and install with DKMS
sudo dkms add     -m peak-linux-driver -v $VER
sudo dkms build   -m peak-linux-driver -v $VER
sudo dkms install --force -m peak-linux-driver -v $VER

# 3. (If you previously did a manual `make install`) remove the stale copy
#    so there is a single source of truth, then refresh module dependencies
sudo rm -f "/lib/modules/$(uname -r)/misc/pcan.ko" 2>/dev/null
sudo depmod -a
```

> **Keep `/usr/src/peak-linux-driver-$VER` in place.** That directory is what DKMS rebuilds
> from on every kernel upgrade — don't delete it like a stray download.

---

## 5. Load the driver and verify

```bash
sudo modprobe pcan
```

Check everything is correct:

```bash
# DKMS shows the driver installed for your kernel:
sudo dkms status
#   peak-linux-driver/9.0, 6.8.0-124-generic, x86_64: installed

# modprobe resolves to the DKMS copy (.../updates/dkms/...):
modinfo pcan | grep -E 'filename|vermagic'

# Module is loaded:
lsmod | grep pcan

# Character device exists:
ls -l /dev/pcanusb*
#   crw-rw-rw- 1 root root 510, 32 ... /dev/pcanusb32
```

If `/dev/pcanusb*` exists, the adapter is ready. Launch `pcanview` (or
`pcanview-ncurses`) to confirm you can see CAN traffic.

---

## 6. Confirm it survives a kernel upgrade

After your distro installs a new kernel and you reboot into it, DKMS should have already
rebuilt the module. Verify:

```bash
uname -r                # new kernel version
sudo dkms status        # should list peak-linux-driver for the new kernel
ls -l /dev/pcanusb*     # device should be present
```

No manual rebuild needed. 🎉

---

## Troubleshooting

| Symptom | Cause | Fix |
| --- | --- | --- |
| `pcan: disagrees about version of symbol module_layout` | Module built for a different kernel | Rebuild for the current kernel — that's what DKMS automates (Section 4) |
| `No rule to make target '.../PEAK'` during build | Space in the source path | Move the source to a path with no spaces (Section 2) |
| `/dev/pcanusb*` missing after `modprobe` | Driver didn't load, or USB not detected | Check `dmesg | tail`, `lsusb | grep -i peak`, `lsmod | grep pcan` |
| Build can't find kernel headers | Headers for running kernel not installed | `sudo apt install "linux-headers-$(uname -r)"` |
| Want to use SocketCAN (`can0`) instead | PEAK installer blacklists `peak_usb` | See note below |

### chardev vs. SocketCAN

PEAK's installer blacklists the in-kernel SocketCAN `peak_usb` driver (in
`/etc/modprobe.d/blacklist-peak.conf`) so it doesn't conflict with the `pcan` chardev driver.
This guide installs the **chardev** driver, which exposes `/dev/pcanusbN` and is used by
`pcanview` and PCAN-Basic. If you instead want a SocketCAN `canX` network interface (for
`candump`/`cansend`/`ip link`), you would remove that blacklist and use `peak_usb` — but then
the chardev tools won't work. Pick one based on your tooling.

### Removing the DKMS driver

```bash
sudo dkms remove -m peak-linux-driver -v $VER --all
sudo rm -rf /usr/src/peak-linux-driver-$VER
```

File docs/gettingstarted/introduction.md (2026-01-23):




## What Is It?

dingoPDM is an automotive `Power Distribution Module`. 

PDMs can be used in place of fuses, circuit breakers and relays, including flasher and wiper relays. 

Each output channel of the PDM:
 
- Measures the active current and reacts by turning the output off if the current exceeds the limit
- Automatically resets after a cool down period a maximum number of times
- Can be turned on/off using various input sources
- Can be on constantly or with Pulse Width Modulation(PWM)

This makes PDMs a very flexible solution when designing the power system in any automotive application. 

## Features

A key feature of any PDM is flexible configuration to match the target application. 

To meet these needs, dingoPDM includes configurable:

- Outputs
- Digital inputs
- CAN inputs
- Virtual logic inputs
- Counters
- Logic conditions
- Wipers
- Flashers
- Starter disable

All settings on the dingoPDM can be controller by the custom Windows application [DingoConfigurator](../software/introduction.md) 

dingoPDM also includes:

- Cyclic CAN status messages (TX)
- Pulse Width Modulation (PWM)
    - Configurable base frequency
    - Fixed or variable duty cycle
- CAN keypad support (work in progress)
    - Blink Marine
    - Grayhill
- Battery voltage measurement
- Internal temperature sensor
- Status LEDs

## User Locations

:flag_us: :flag_de: :flag_fr: :flag_gb: :flag_pt: :flag_au: :flag_kn: :flag_jp: :flag_bh: :flag_it: :flag_fi: :flag_dk:

```vegalite 
{
    "schema-url": "assets/charts/countries_chart.json"
}
```

```vegalite 
{
    "schema-url": "assets/charts/states_chart.json"
}
```

## Configuration

The dingoPDM configuration can be accessed using:

- USB-C connected directly to the device, one at a time
- A CAN connection to one or many dingoPDMs at once using a USB to CAN adapter such as [USB2CAN](https://github.com/corygrant/USB2CAN_HW)

Configuration reading/writing and status monitoring are all done using the custom built Windows application [DingoConfigurator](../software/introduction.md) 

## Wiring Example

ExampleWiring
ExampleWiring

## Resources

### GitHub
dingoPDM is split between 3 GitHub repos.

The latest releases can be found on the Releases page for each repo:

- Hardware: [dingoPDM](https://github.com/corygrant/dingoPDM/releases)
- Firmware: [dingoPDM_FW](https://github.com/corygrant/DingoPDM_FW/releases)
- Software: [DingoConfigurator](https://github.com/corygrant/DingoConfigurator/releases)

dingoPDM-Max is split between 2 GitHub repos. 

The latest releases can be found on the Releases page for each repo:

- Hardware: [dingoPDM-Max](https://github.com/corygrant/dingoPDM-Max)
- Firmware: [dingoPDM-Max_FW](https://github.com/corygrant/dingoPDM-Max_FW)

!!! Note
    dingoPDM will ship with the latest firmware release installed at the time of shipping, but new firmware is released frequently. 

    Check the Releases page for a new release when receiving the dingoPDM and follow the [Firwmare Updating](https://corygrant.github.io/dingoPDM/firmware/updating/) instructions. 

### Store

Built and tested dingoPDMs can be purchased through the Dingo Electronics Store. 

All PDMs are assembled and tested in Virginia :flag_us:

[Dingo Electronics Store](https://dingo-electronics.square.site/)

### Discord

See invite link at the bottom right of the page

!!! Note
    If the link is expired, send a message on the store page 

### Facebook

See link at the bottom right of the page

## Test Config File

When first powering on dingoPDM, whether one received from the store or built yourself, the included test file can be used to verify functionality. 

The test file includes a very basic setup:

- All outputs:
    - Enabled
    - Set to turn on with input 1
    - Set to their max current limit with endless reset
- Input 1 set to: 
    - Pullup
    - Invert
    - Momentary
    
Connect input 1 to ground to turn all outputs on. 

## Changing CAN ID

The CAN Base ID default value is 2000. 

To change this, modify the value in the [DeviceTree](../software/devicetree.md) and press `Update` and then `Burn` to save the setting. 

On the next power up, the CAN Base ID will be updated. 

## Goals

- [X] Learn more about PDMs and high DC current devices
- [X] Learn about developing firmware for a more complex STM32 based project
- [X] Create a low cost device that my friends and I can use in our project cars
- [X] Layout the board to fit simple case designs
    * [X] 3D printed top shell and flat aluminum heatsinks (no machining)
- [X] Use low cost 1oz/0.5oz 4 layer PCBs (low cost 2oz/1oz now available from JLCPCB)
- [X] Share my work with others for reference, inspiration or collaboration. 
- [X] Document the project in a professional way to make it easy to use and access
- [X] Develop an easy to use configuration PC software
- [X] Offer fully built devices for sale

!!! info
    If this project helps you in any way, I'd appreciate a message!

## Project Status

- :green_square: : Complete
- :yellow_square: : In Progess
- :red_square: : Not Started

| Recent Open Items | Status |
| --- | --- |
| Finish case design | :green_square:  |
| Test thermal performance | :green_square:  |
| Support USB C to C cables  | :green_square:  |
| Develop dingoPDM-Max | :green_square:  |
| Finish documentation | :yellow_square: |
| Add device sleep | :green_square:  |
| Add verbose error handling | :green_square:  |
| Add keypad support | :yellow_square: |
| Add PWM output support | :green_square:  |
| Switch-less bootloader | :green_square:  |
| Add soft HMI buttons | :yellow_square: |
| Finish plots in software | :yellow_square: |
| Move to ChibiOS | :green_square:  |

## Documentation Status

???+ Note

    Any help with the documentation is always welcome. 
    
    If you're familiar with git, submit a PR with your updates. 
    
    If not, you can message me the updates/additions on Discord and I can make the changes. 

    Markdown preferred, but not required. 

- :yellow_square: : Needs to be updated
- :red_square: : Does not exist

| Section | Status | Notes |
| --- | --- | --- |
| [Customization](../firmware/custom.md) | :yellow_square: | PCB and VarMap info needs to be added |

## Disclaimer

!!! warning
    Please note that this product has been designed by a hobbyist, not a professional. 
    It is intended for off-road and testing use only. 
    Users should operate the product at their own discretion and risk. 
    The designer explicitly disclaims any responsibility for damage or injury that may result from the use of this product.

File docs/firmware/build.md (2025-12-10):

Building dingoPDM firmware locally on your machine

!!! Note
    dingoPDM firmware is already pre-built and ready for use on [the release page](https://github.com/corygrant/DingoPDM_FW/releases)

## Linux

### ARM Toolchain

Download the relevant ARM toolchain from the [ARM website](https://developer.arm.com/downloads/-/arm-gnu-toolchain-downloads)

> x86_64 Linux hosted cross toolchains

> AArch32 bare-metal target (arm-none-eabi)

> `arm-gnu-toolchain-14.3.rel1-x86_64-arm-none-eabi.tar.xz`

The ARM toolchain needs to be on your PATH in order to use it on your machine. 

- Extract to a folder on your machine
- Put the folder on your PATH (example with version 14.2 and folder in /opt/):
    - `nano ~/.bashrc`
    - Place this at the bottom of the `.bashrc` file
        - `export PATH="/opt/arm-gnu-toolchain-14.2.rel1-x86_64-arm-none-eabi/bin:$PATH"`
    - Save and close nano
    - Restart terminal (or run `source ~/.bashrc`)
    - Validate with `arm-none-eabi-gcc -v`

### OpenOCD

OpenOCD can be installed using: `sudo apt install openocd`

Validate with `openocd -v`

## Windows

### ARM Toolchain

Download the relevant ARM toolchain from the [ARM website](https://developer.arm.com/downloads/-/arm-gnu-toolchain-downloads)

> Windows (mingw-w64-x86_64) hosted cross toolchains

> AArch32 bare-metal target (arm-none-eabi)  

> `arm-gnu-toolchain-14.3rel1-mingw-w64-x86_64-arm-none-eabi.zip`

The ARM toolchain needs to be on your PATH in order to use it on your machine. 

- Unzip to a folder on your machine
- Put the folder on your PATH:
    - Open Environment Variables (Windows key, type Environment Variables)
    - Add the path to the `/bin` folder to your PATH variable
    - Open terminal
    - Validate with `arm-none-eabi-gcc -v`
        - If you receive an error, restart your terminal (or VS Code if using VS Code)

### OpenOCD

I've found that the easiest way to use OpenOCD on Windows is to use the xPack OpenOCD packages. 

- Download the xPack OpenOCD package [from the repo](https://github.com/xpack-dev-tools/openocd-xpack/releases)
    - Example `xpack-openocd-0.11.0-1-win32-x64.zip`
    - **Note: I've only been able to get v0.11 to work on my machine**
- Unzip to a folder on your machine
- Put the `/bin` folder on your PATH (same process as ARM toolchain above)
- Validate with `openocd -v`
    - If you receive an error, restart your terminal (or VS Code if using VS Code)

### Make

Use MSYS2 to add make and other Linux tools to Windows

- Install from the [MSYS2 site](https://www.msys2.org/#installation)
- Add the MSYS2 `usr/bin` folder to PATH
    - `C:\msys64\usr\bin`
- Check by running `pacman -V`
    - Note the capital -V
    - If you receive an error, restart your terminal (or VS Code if using VS Code)
- Install make using `pacman -S make'

## VS Code

The dingoPDM firmware repo includes VS Code settings to make working with the firmware easier. 

### Setup

The path to your ARM toolchain must be set in these settings files so VS Code can find the toolchain. 

- `c_cpp_properties.json`
    - Change `compilerPath` to the toolchain `/bin` path on your machine
    - Note that there are two configurations: `STM32-ChibiOS-Windows` and `STM32-ChibiOS-Linux`, make sure you're editing the correct configuration
- `settings.json`
    - Find the correct configuration: `windows` or `linux`
    - Edit `cortex-debug.armToolchainPath` to the toolchain `/bin` path on your machine
    - If on Windows, edit `cortex-debug.openocdPath` to the OpenOCD `.exe` path on your machine

### Build

To build the firmware in VS Code, press ++ctrl+shift+b++

VS Code will ask you which board type to build for, select the board type and press ++enter++

### Debug

To debug the firmware, press ++ctrl+shift+d++

Select the debug type from the dropdown based on the board type

Press ++f5++ to start debugging with OpenOCD

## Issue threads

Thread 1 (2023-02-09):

How can we obtain pre-assembled units?

ElDominio, 2023-02-09:
I know a large group of software guys who might be interested in acquiring a pre-assembled unit to play around with code. Where can I point them to? Is there a Slack channel for this project?

corygrant, 2023-02-09:
Currently the only units are the ones I've built, but if you'd like we can talk about building some more.
There's no Slack channel yet, but I could create one if you like?

bryanbendall, 2023-02-16:
I would be interested in it as well.

corygrant, 2023-02-16:
I'm going to build a batch of V4 boards soon, would you be interested in buying an assembled unit?

bryanbendall, 2023-02-16:
Yes an assembled one would be good. I would like to try it out with the software I'm working on. I made some of my own boards but they need to be updated. Hard to find parts right now. Any idea on the cost of them yet?

corygrant, 2023-02-17:
It's probably not cost effective (or timely) for me to do assembly by hand.
Purchasing parts from Digikey/Mouser the BOM cost is around $150 right now, plus maybe $4 for a PCB.
But, it takes me hours to assemble one of these by hand.

Maybe the next step should be getting this setup for PCBA through JLC or similar.

JZXPacky, 2023-06-27:
Any chance you've got this setup for JLC etc yet? I'm very interested in building one of these units and incorporating into my car with a Haltech Elite 2500.

corygrant, 2023-06-29:
@JZXPacky no not yet. I've done a little testing when I've been able to find the time, but not to a point that I would want to order more assembled boards.
Feel free to use the Kicad files and BOMs to set it up though!

corygrant, 2024-04-24:
Just finished a batch of pre built PDMs.
Working on getting the online shop set up, but PayPal also works

ZHoob2004, 2024-05-06:
Based on the new pictures in the repo, it looks like you have some units in hand. I could be interested in buying one, but I'm not sure how to contact you outside of github issues.

corygrant, 2024-05-06:
@ZHoob2004 I just opened the store site up, first shipments from the store going out Monday 5/13.
https://dingo-electronics.square.site/

Closed 2024-05-06.

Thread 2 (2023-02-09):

Some humans love looking at PDF files, gerbers are usually consumed together

rusefillc, 2023-02-09:
Let me mix two pretty separate but a bit related minor usability issues

* fab houses usually needs gerbers.zip not individual files, even tools sometimes open gerbers.zip not individual file
* some humans love looking at PDFs without firing up proper KiCad to look at schematics

together see https://github.com/mck1117/proteus/tree/master/export/v0.1 as an example of a friendly "export/vX" approach for artifacts both gerbers, pdf and bill/placement

corygrant, 2023-02-10:
Yea that's a good idea, I usually keep a folder with PDFs but I didn't have it in this folder.
Closed with commit c598e04

Closed 2023-02-10.

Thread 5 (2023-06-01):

Is there software for this yet?

MatteBSki, 2023-06-01:
I came across this and its something I'd love to help develop.  I've been working on creating a multi PDM system that uses smaller PDMs around the vehicle to keep harness size and current draw to a minimum.  While yours is a single setup, I dont see why the concept couldnt be modified for different use cases.

What I didnt see is any type of control software.  Is this current being programmed straight from code or is there something like TunerStudio being used as a GUI for flashing and monitoring the module?

corygrant, 2023-06-02:
The firmware and software are both in progress, but I've been super busy at work this year so I haven't been able to get them done as fast as I would like.
The firmware is currently set up to be built with the settings hard-coded in, that's what I've been using for testing.
But lately I've been working on the program to get status/send new settings from a PC over CAN or USB.

Having no background in this type of thing I spent way too long trying to figure out how to make settings changes over CAN and USB work.
Over USB is pretty easy as you can stuff a lot of data into a few messages, but CAN made it a lot more restrictive.
In the end I decided to use an alpha numeric upper/lower case prefix system with identical data sets between CAN and USB.
That seems to work pretty well, but it needs more development and testing.

I'm hoping to have it finished by the end of the year.

As far as the size of the unit, I went back and forth between different output counts and form factors for a while before landing on the 12 outputs.
There are a lot of units out there that have many more, but for my use cases 12 outputs is plenty.
If I need more, it's easy enough to use 2 units as the size is still fairly compact.
I could definitely make it more compact if I left some hardware features out, but at such low volumes it's much easier to leave them on for possible future developments.

Are you interested in helping with the firmware/software?

MatteBSki, 2023-06-02:
The amount of outputs is fine, no issue at all.  I've been also slowly designing a system that would have micro PDMs instead of a single one for ease of install.  Basicallly, you'd have a module for front lighting, horn, fans.  In the back, youd have one that handles the running lights, turns, brakes, fuel pump, then one for running loads under the dash along with a CAN input board for switches and such.  The thinking is that you can wire the car with harnesses that are only a few feet long and then interconnect them with a bat lead and CAN bus.

I'd definitely be happy to help, I'd need to build a board first, but you have some pretty interesting designs and if I can help get them working, I'd be down.

corygrant, 2023-06-02:
That's definitely a cool way to do it, it seems like Link is trying to go that way with their Razor PDM.

I decided against a more distributed approach due to:
-Weatherproofing and temperature requirements for under hood (I use these in rally cars, so extreme weather resistance required)
-Needing to run large fused conductors from the battery to each device, rather than 1 large fused conductor that I can branch between multiple devices locally
-Needing to have different spares with different settings pre-loaded for fast changes in service/pits (important for race/rally situations)

MatteBSki, 2023-06-02:
Yeah, waterproofing and building to be reliable at 125c for extended periods has been a hangup of mine as I've been choosing components.  Good thing is that when you run less loads per module, the heating from them is less as well so you can work more on heatsinking.  3D printing an enclosure may not work, but there are sealed enclosures available that will work. Similarly, since each module may only be responsible for 25-30A in general, you can power it with a 12-10AWG lead instead of a 4 or 6AWG lead.

Regarding having to have separately programmed modules, that I would differ.  I want to use a single universal module and be able to program them over CAN (preferablly) from a central location, so as long as each has module has a bootloader, you should be able to plug in another and flash it in the car with a laptop.

I'd think that if the base programming of the Dingo is built out correctly, you should be able to do all that with your design using multiple modules versus a mini version of the same system (just gotta keep an eye on modularity in code).

rusefillc, 2024-01-30:
Just checking how SW is going :) is there a URL for anything-firmware or is it not publicly available in any shape or form?

rusefillc, 2024-01-30:
PS: there are screen shots at https://corygrant.github.io/DingoPDM/software/introduction/ so something seems to exist :)

corygrant, 2024-01-31:
Yes something does exist, good find! :)
I was making good progress on it, but then things got busy with the holidays and work projects.
Hopefully finish it up soon and make it public.
I did get 10 assembled boards in along with heatsink plates.
Just need to finish printing some more cases.

danamaniac, 2024-05-05:
Hi mate thankyou for your devalopment on this, i have 5 boards made. Just waiting on the software. Hows it coming along?

corygrant, 2024-05-05:
Went ahead and made it public.
Still working on it, but it has enough functionality to use.
https://github.com/corygrant/DingoConfigurator

And the firmware
https://github.com/corygrant/DingoPDM_FW

danamaniac, 2024-05-06:
Thankyou Thankyou, legend.

On 6 May 2024, at 5:14 AM, Cory Grant ***@***.***> wrote:

Went ahead and made it public.
Still working on it, but it has enough functionality to use.
https://github.com/corygrant/DingoConfigurator

And the firmware
https://github.com/corygrant/DingoPDM_FW

—
Reply to this email directly, view it on GitHub<https://github.com/corygrant/dingoPDM/issues/5#issuecomment-2094917550>, or unsubscribe<https://github.com/notifications/unsubscribe-auth/APZD3YBAEONREORWOJNMO43ZA2AI5AVCNFSM6AAAAAAYXRMXI2VHI2DSMVQWIX3LMV43OSLTON2WKQ3PNVWWK3TUHMZDAOJUHEYTONJVGA>.
You are receiving this because you commented.Message ID: ***@***.***>

Closed 2024-05-05.

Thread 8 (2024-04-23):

Holes Misaligned Between Baseplate and Case

ZHoob2004, 2024-04-23:
First of all, I really like the project, and I'm looking into having a few units produced so I can start to play with them and help out.

While going through the release files you've provided, I noticed that 3 of the 4 holes do not line up between the case and the base plate. Assuming this was meant to be a rectangular pattern, I determined the error is in the case and I'm working on a fix.

Related to this issue, is there any reason behind the chosen bolt pattern? I measure the bolt square as 96.39x87.25mm, which both seem like pretty random numbers. I feel like it would be beneficial to use a nice square number so it's easier to mark and drill holes for installation.

corygrant, 2024-04-24:
Weird! I have made a bunch of cases but haven't noticed any misalignment, I can check the source model later.

Regarding the bolt pattern, I think that may be aligned to inches in Kicad but I'm not certain. I probably scooted the bolt holes around to improve trace placement to make life easier for myself haha.

I like use a paper template with an optical punch for stuff like this so the round numbers aren't a big deal.

By the way, I just finished a batch of PDMs.
Working on getting the online shop up, but PayPal works too if you'd rather start with a pre-built one.

corygrant, 2024-04-24:
Good catch @ZHoob2004!
I had moved the case up to make room for the thermal pads but accidentaly bumped it over as well.
That explains why one screw was always a bit harder to get in and why the USB hole was a bit misaligned.

Case step file is updated now.

I also see what you're saying about the holes being at weird dimensions.
The hole positions came from a very early sketch where I had placed them based on the edge of the board.
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

I'll look at fixing that spacing on the next batch of cases/baseplates

ZHoob2004, 2024-04-24:
Sounds good.

Another thing I ran into is the baseplate and heatsink are step files, but they probably only need to be dxf since they're two dimensional.

Normally this would be a non issue but I was quoting the parts for laser cutting and the baseplate was problematic with the modeled threads (which is what led to me finding the misalignment)

And I could be interested in a prebuilt unit if you have one. I can always reprint the case and change the baseplate if needed to change the bolt pattern.

Closed 2024-05-21.

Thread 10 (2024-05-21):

Determine max and critical board temperatures

corygrant, 2024-05-21:

corygrant, 2025-03-19:
dingoPDM thermal tests: https://corygrant.github.io/dingoPDM/hardware/thermal/

Need to complete thermal tests on dingoPDM-Max and then update the limits

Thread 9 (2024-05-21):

Increase screw hole size

corygrant, 2024-05-21:
Increase screw hole size to allow for a small misalignment in the baseplate mounting holes.
It also allows for a bit of squish when the thermal pad material is compressed without bowing.
The current holes are very tight to the screws, which can lead to bowing in the center.

corygrant, 2024-06-04:
c667686d73b3e01ca5473f0d3c5ea3fbcb77be04

Closed 2024-06-04.

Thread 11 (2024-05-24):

Connect CAN transceiver Rs (standby) pin to MCU

corygrant, 2024-05-24:
To put the transceiver into Standby when the MCU goes to sleep to save power

corygrant, 2024-06-04:
c667686d73b3e01ca5473f0d3c5ea3fbcb77be04

Closed 2024-06-04.

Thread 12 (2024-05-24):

Change power LED

corygrant, 2024-05-24:
Having the power LED on all the time uses extra power when the MCU enters sleep mode.
If the device is used without a battery disconnect this is not ideal.
There are a few options:
- Not easily changed:
  - Add a solder bridge
    - An open one that must be soldered to get the LED
    - Or a closed one that must be cut to disable the LED
  - Add a 0 ohm resistor
  - Desolder the LED or resistor
- Easy to change:
  - Slide switch (like boot switch, requires extra parts)
  - Pin jumper (thru hole and extra parts)
  - Go to a MCU output (uses up a pin)
    - Would also not represent power correctly

This is something that is dependent on the installation, so I don't think it needs to be easy to change.
A solder bridge is probably the best approach, either an open or closed one.

corygrant, 2024-06-04:
c667686d73b3e01ca5473f0d3c5ea3fbcb77be04

Closed 2024-06-04.

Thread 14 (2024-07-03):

Add reverse battery protection

corygrant, 2024-07-03:
Need a diode between 12V and the VXO7805 power module.
I missed that the power module doesn't have reverse battery protection.

That became apparent when I accidentaly hooked the power up backwards.
That killed the power module which put 12V on the 5V output and killed the CAN transceiver.
Everything else was protected by the 3.3V regulator.
Profets were protected according to their datasheet.

corygrant, 2024-09-06:
Included on v7.4 PCBs

Closed 2024-09-06.

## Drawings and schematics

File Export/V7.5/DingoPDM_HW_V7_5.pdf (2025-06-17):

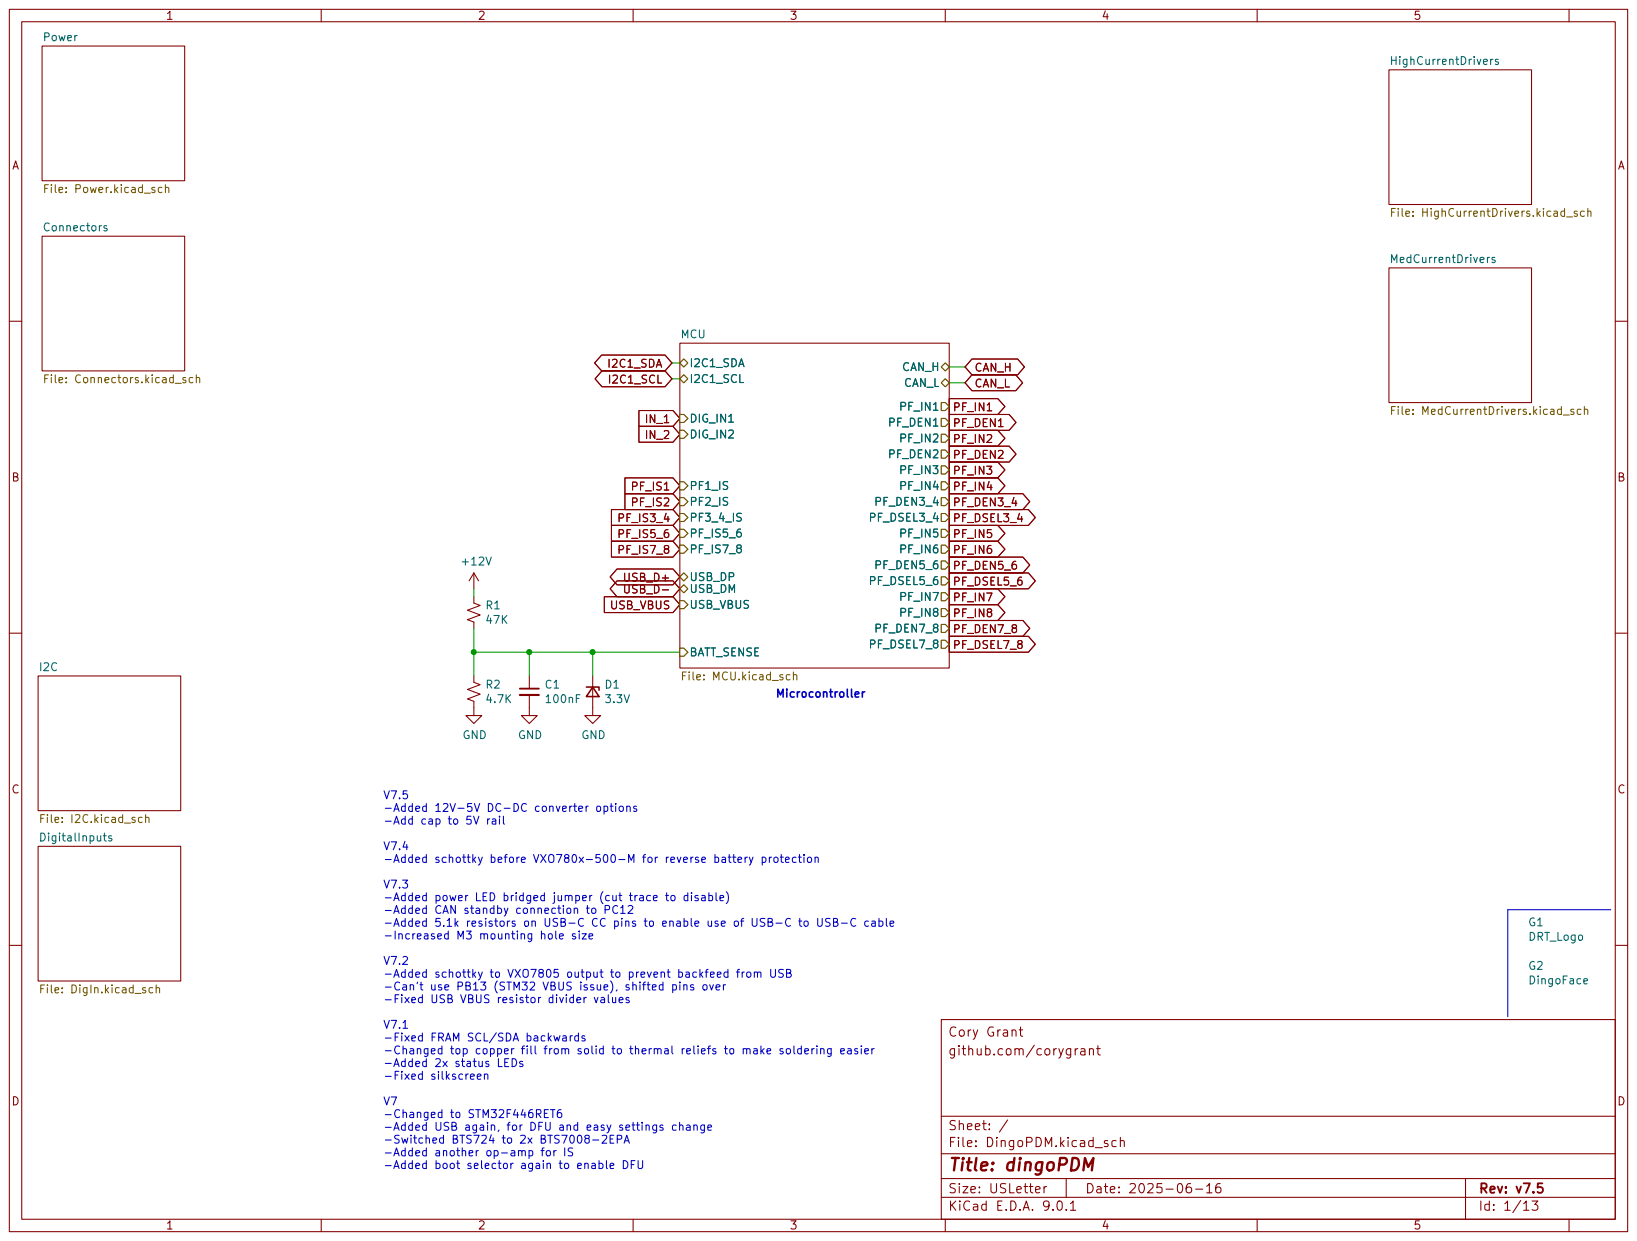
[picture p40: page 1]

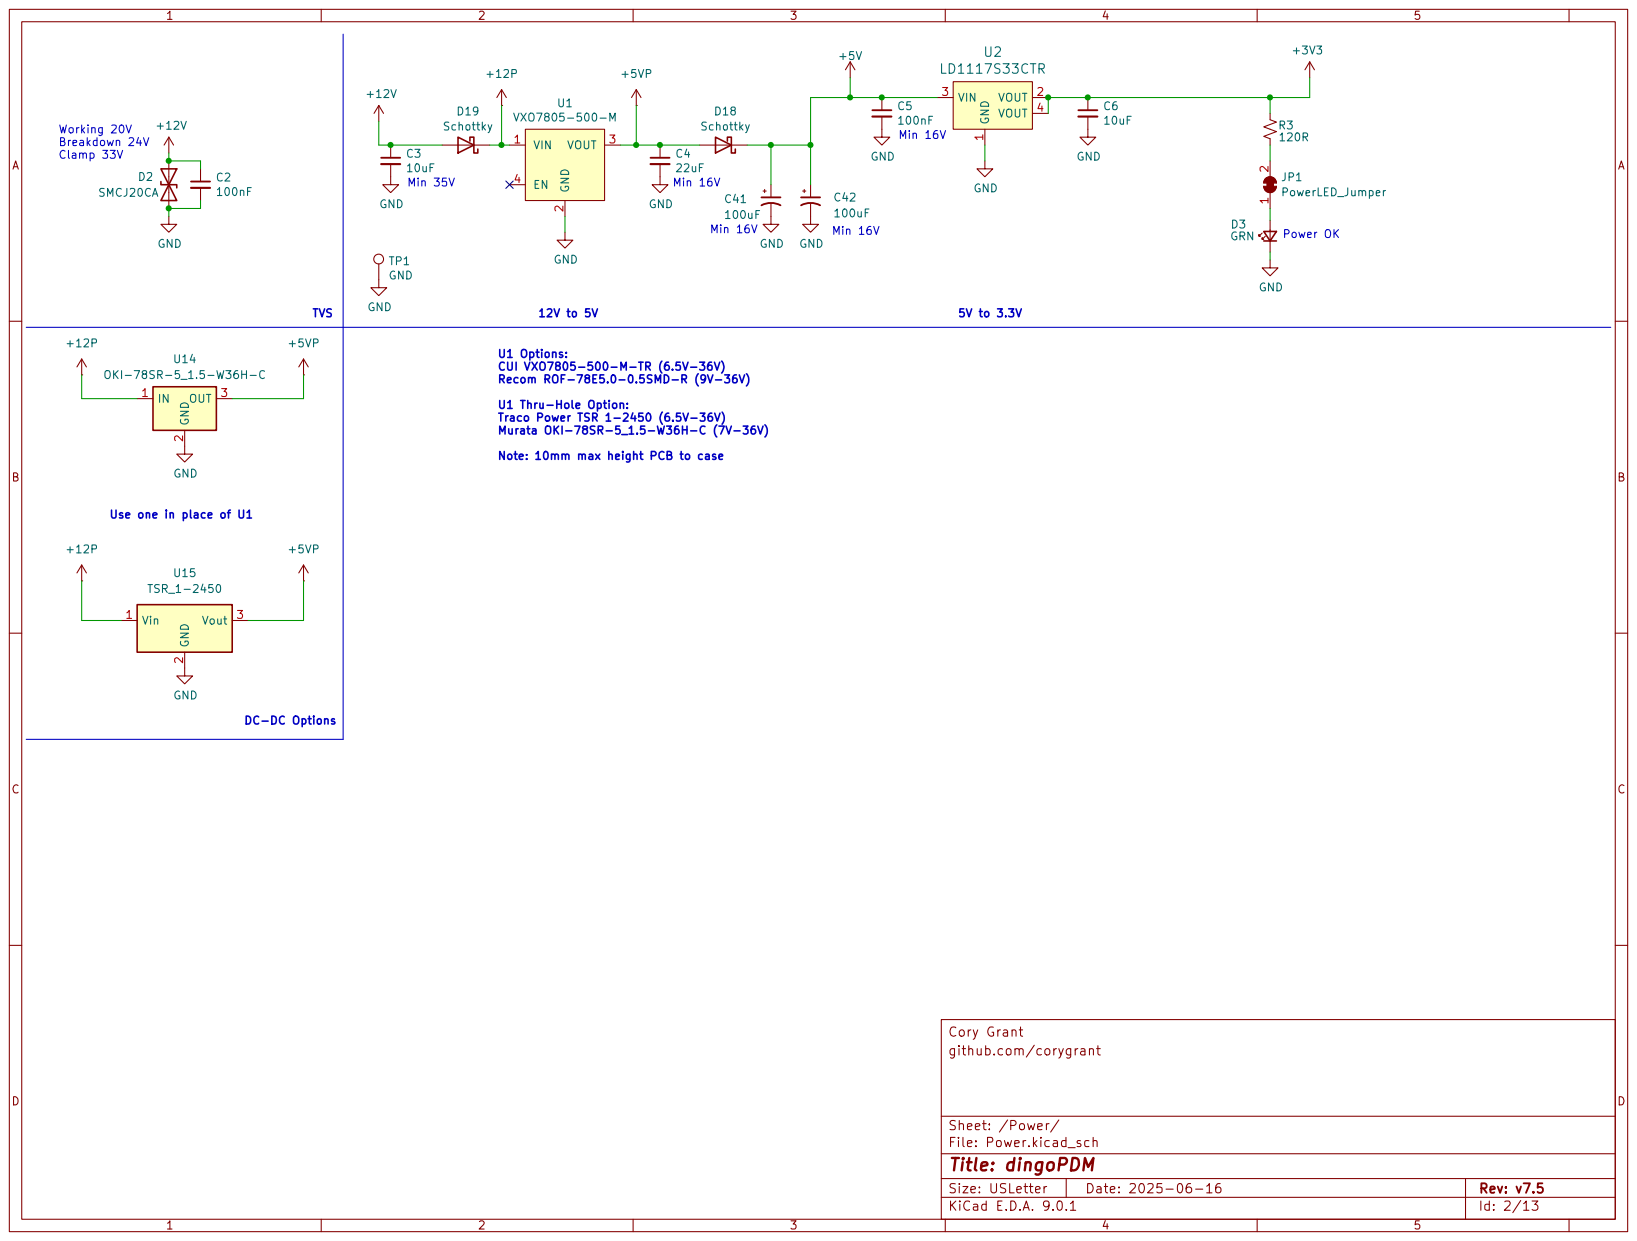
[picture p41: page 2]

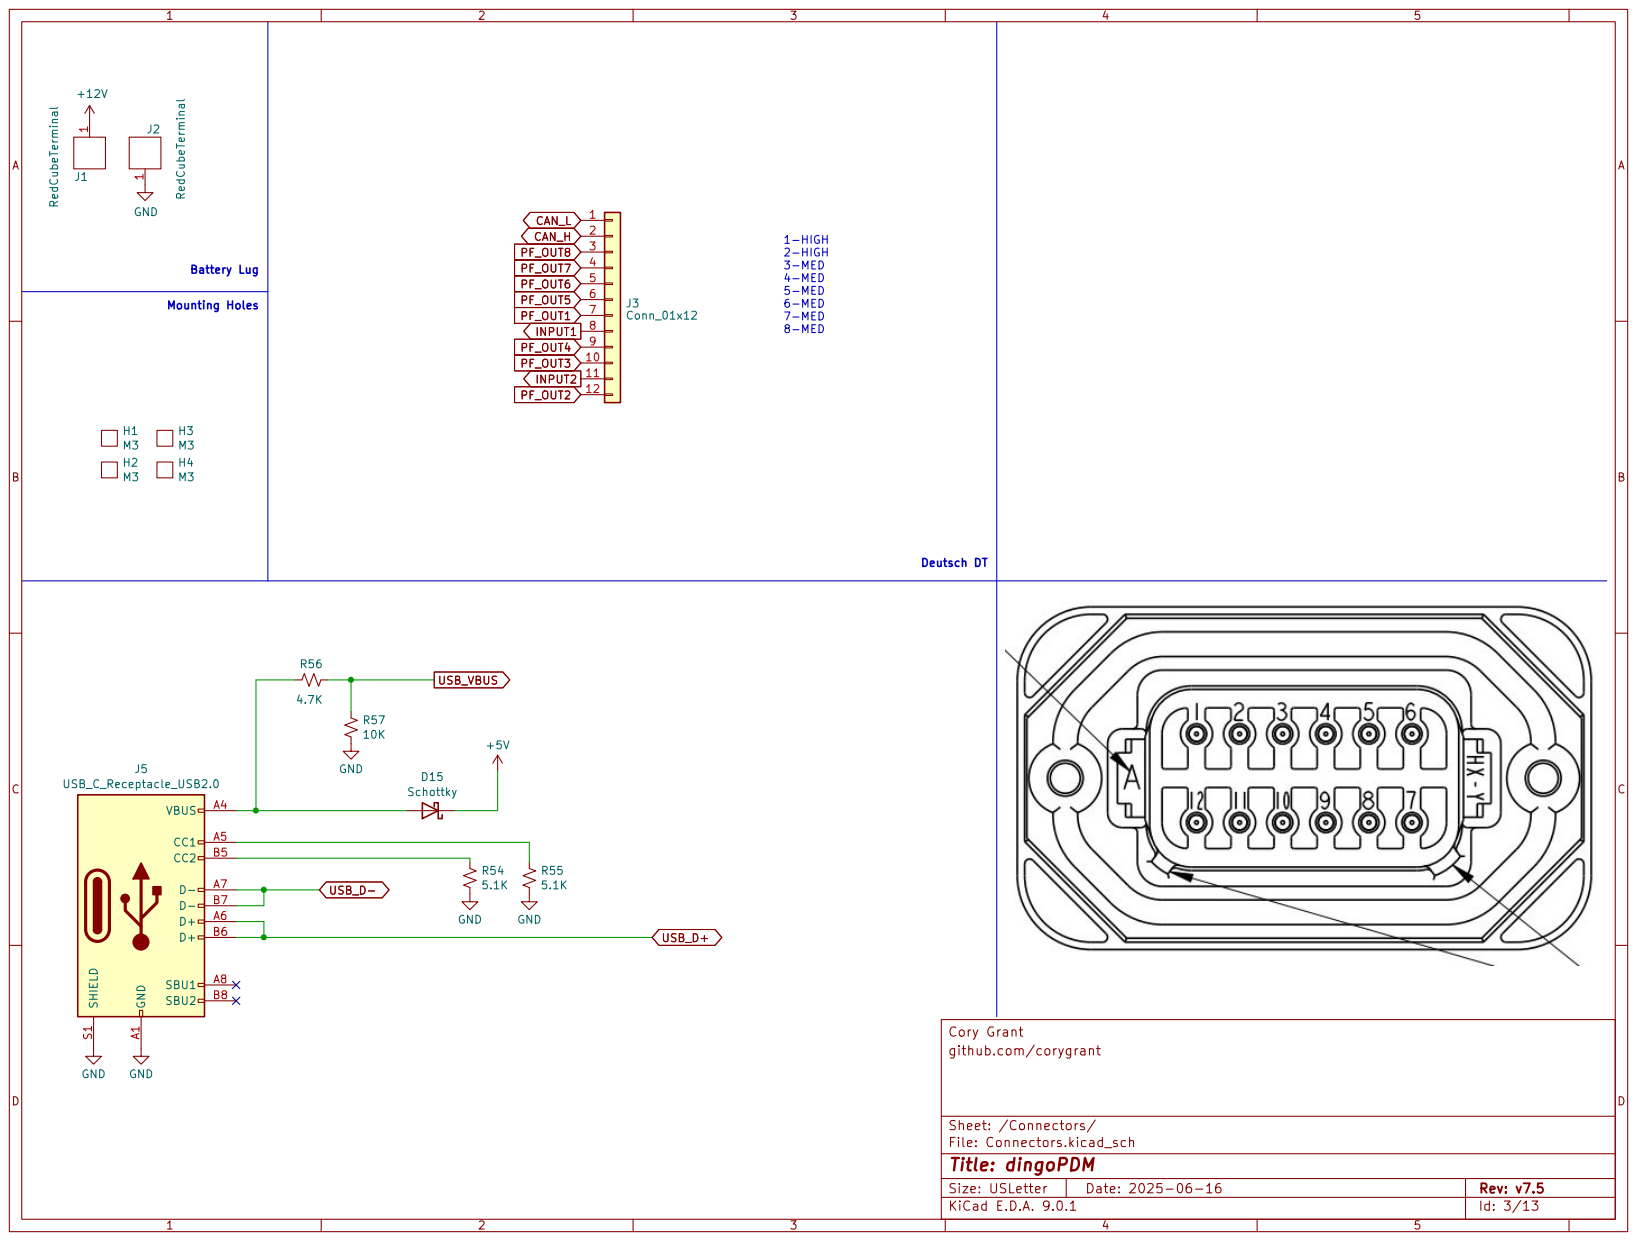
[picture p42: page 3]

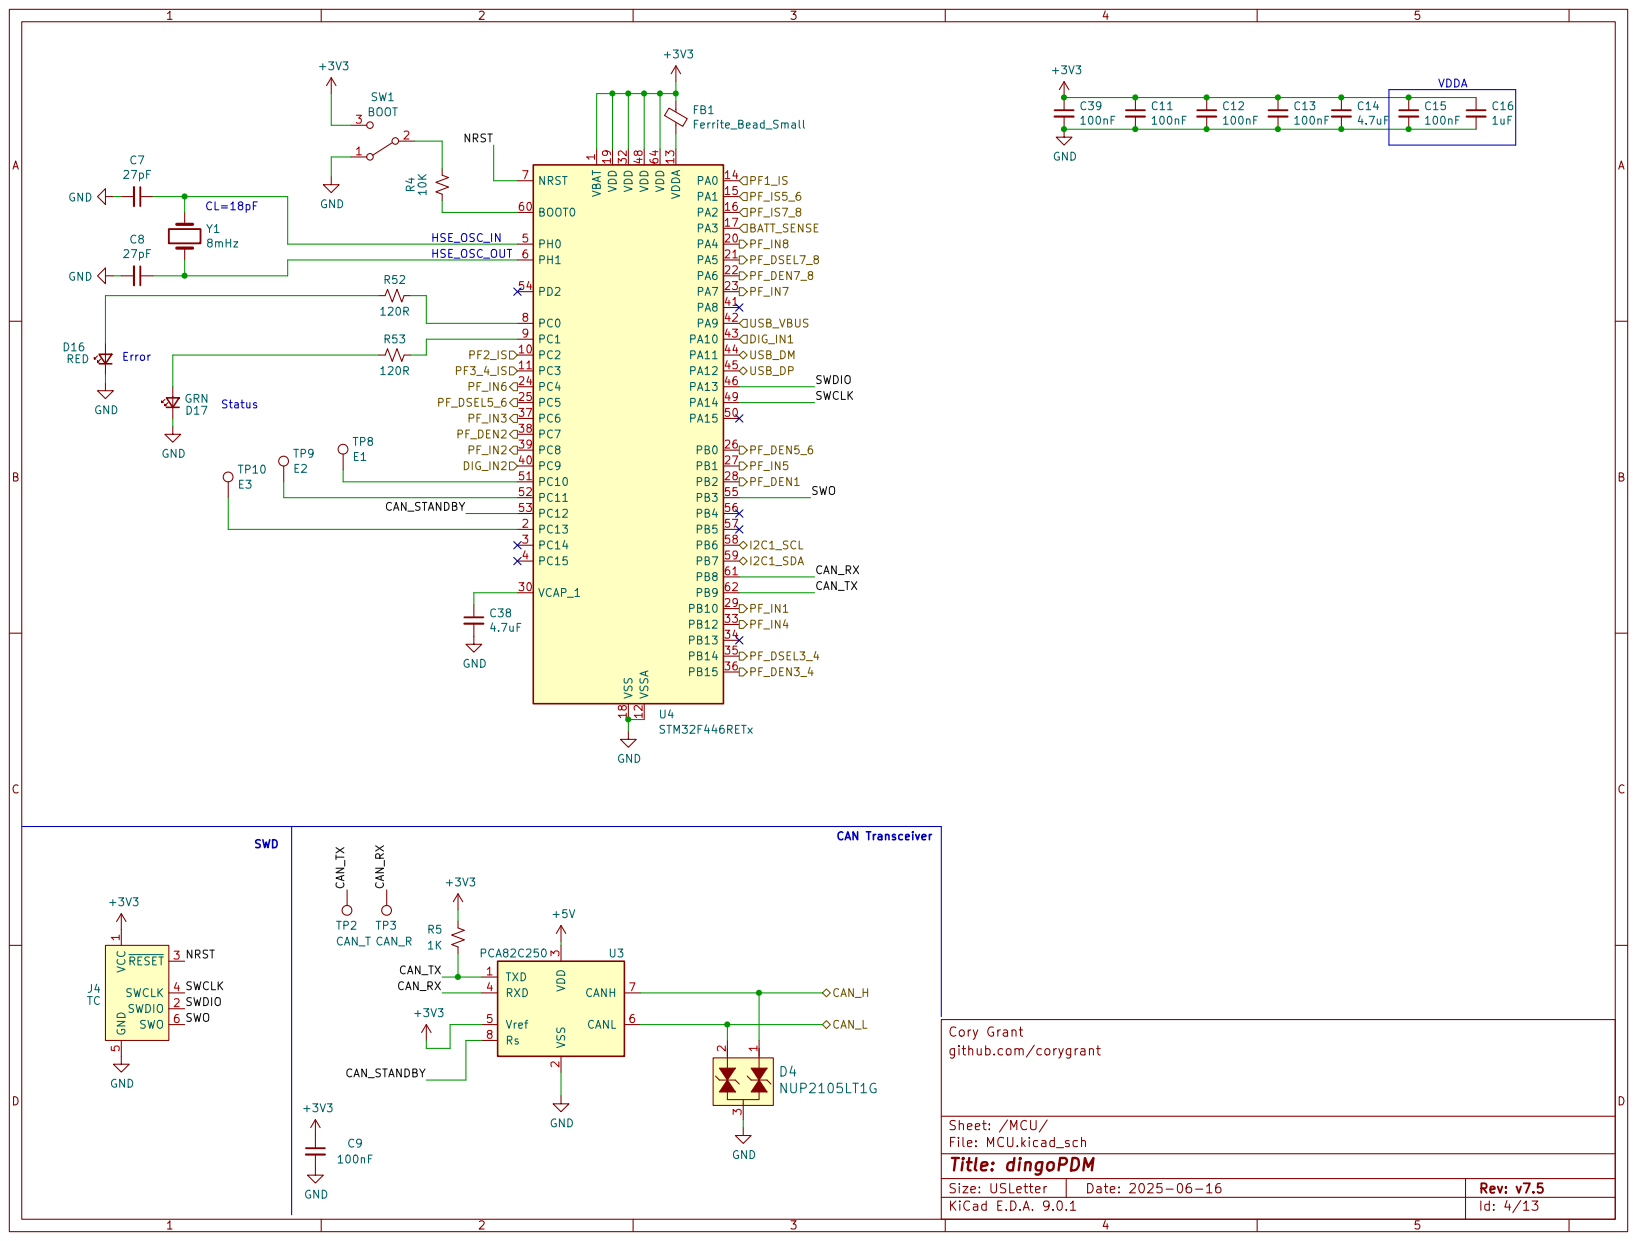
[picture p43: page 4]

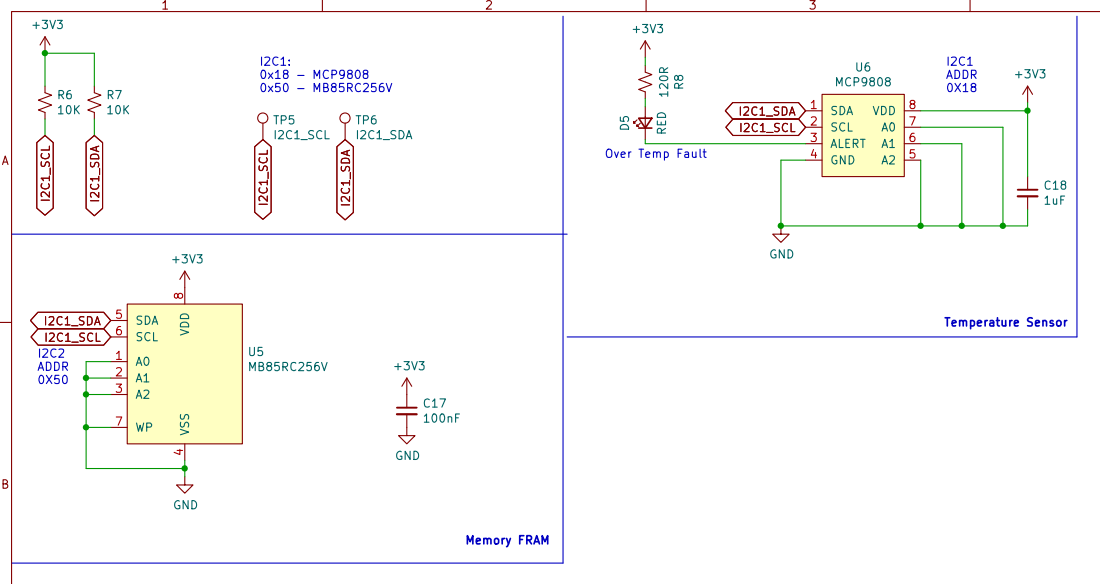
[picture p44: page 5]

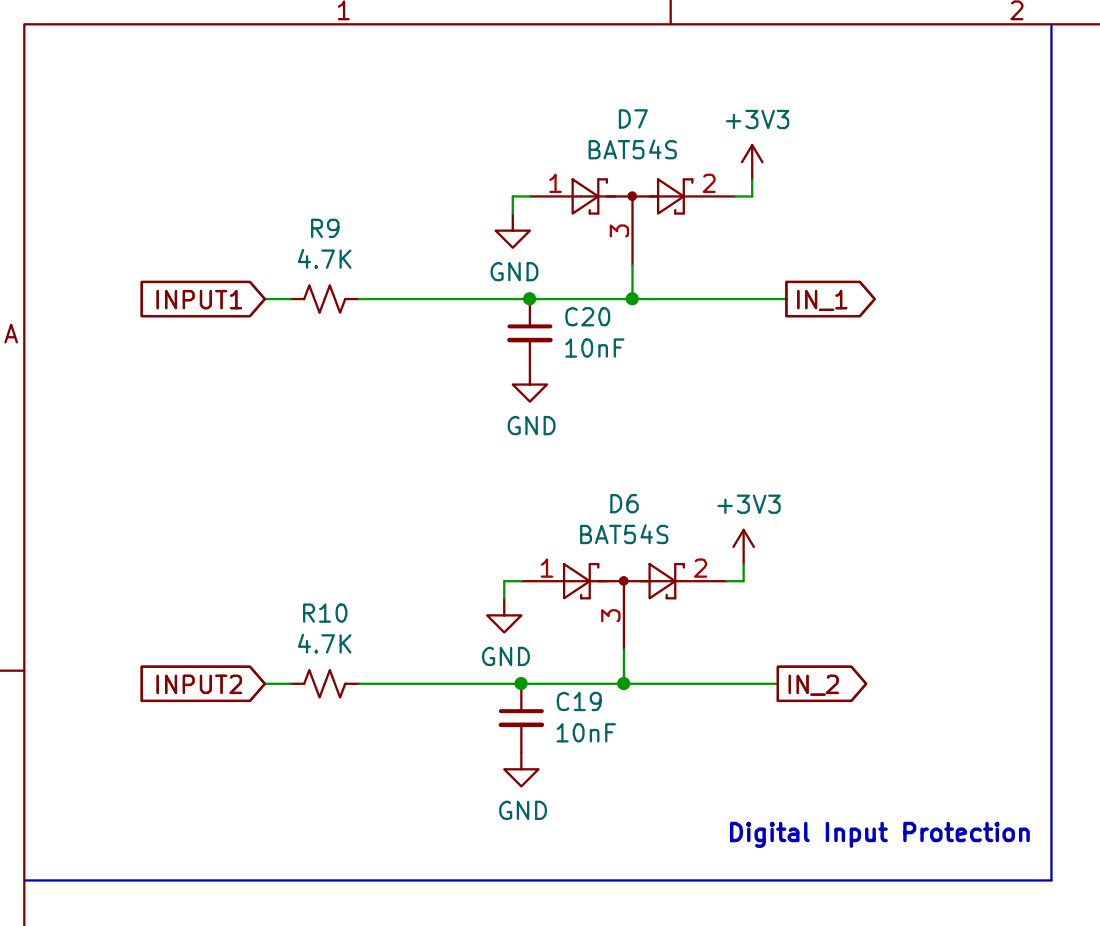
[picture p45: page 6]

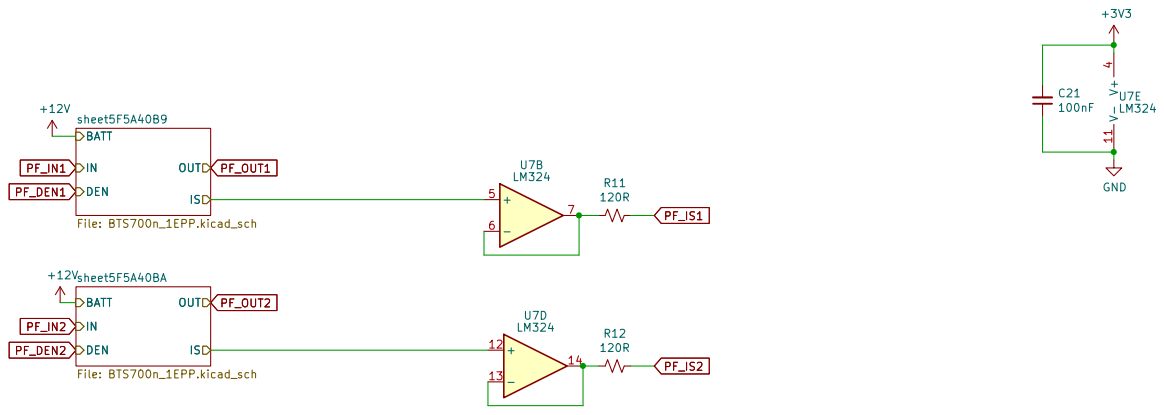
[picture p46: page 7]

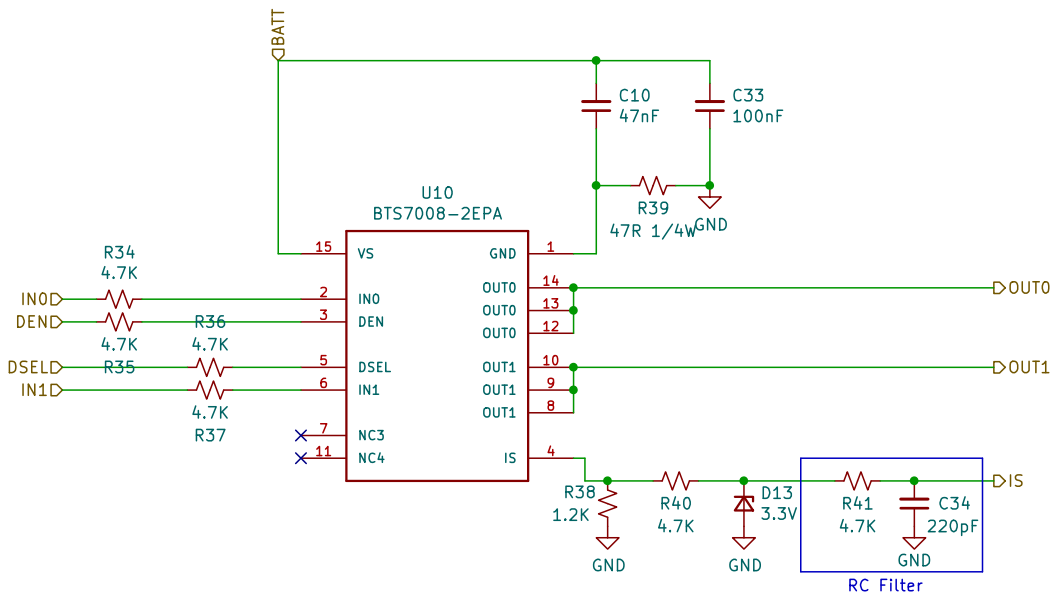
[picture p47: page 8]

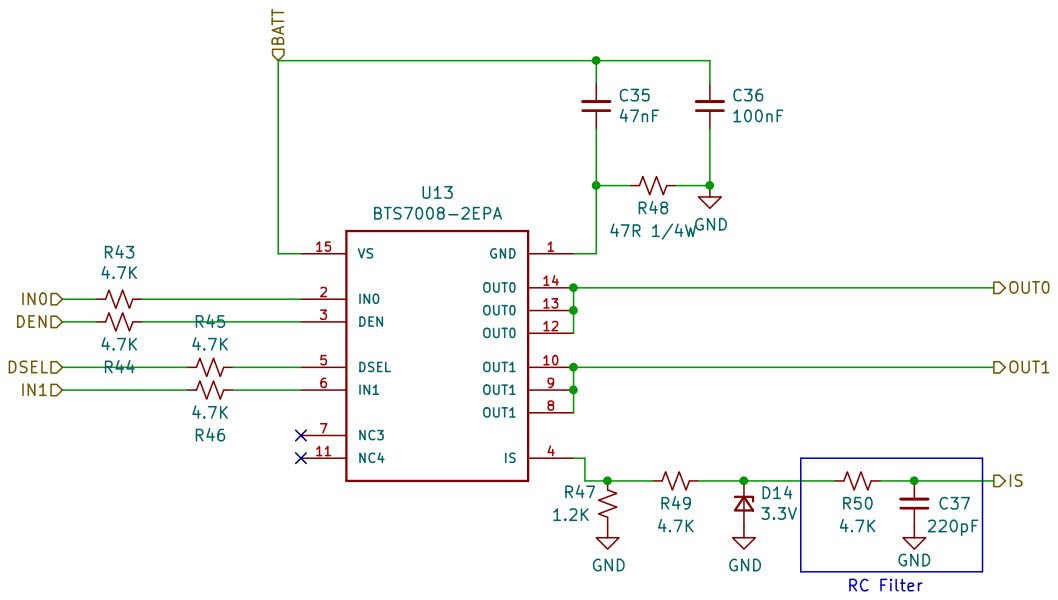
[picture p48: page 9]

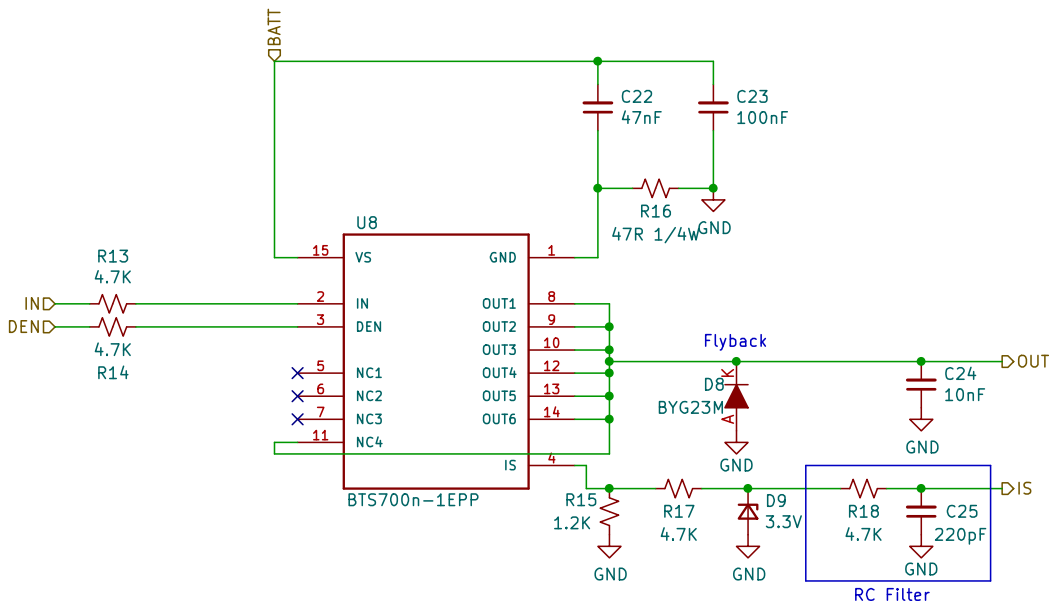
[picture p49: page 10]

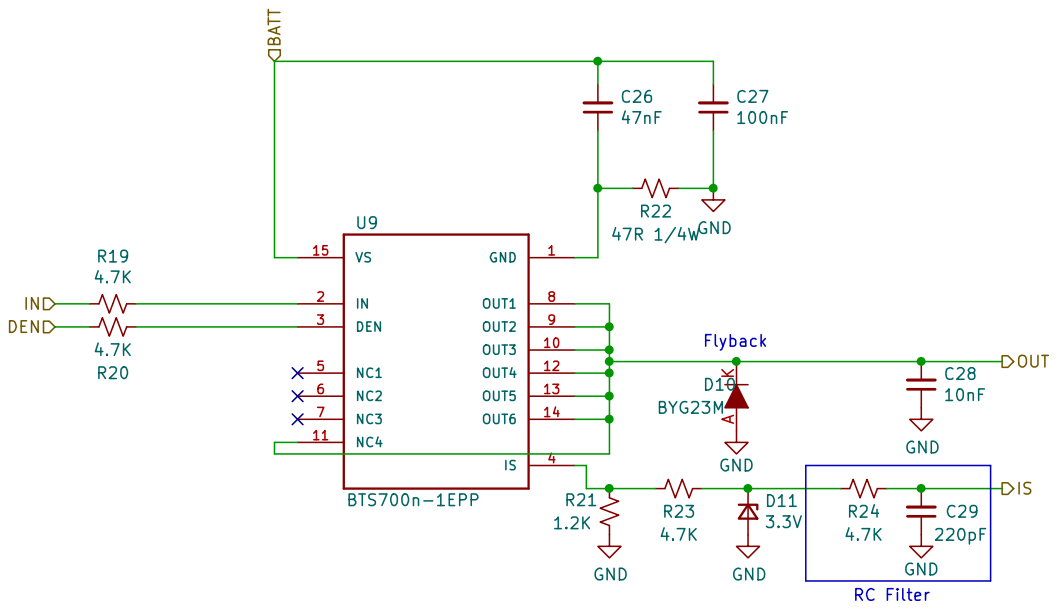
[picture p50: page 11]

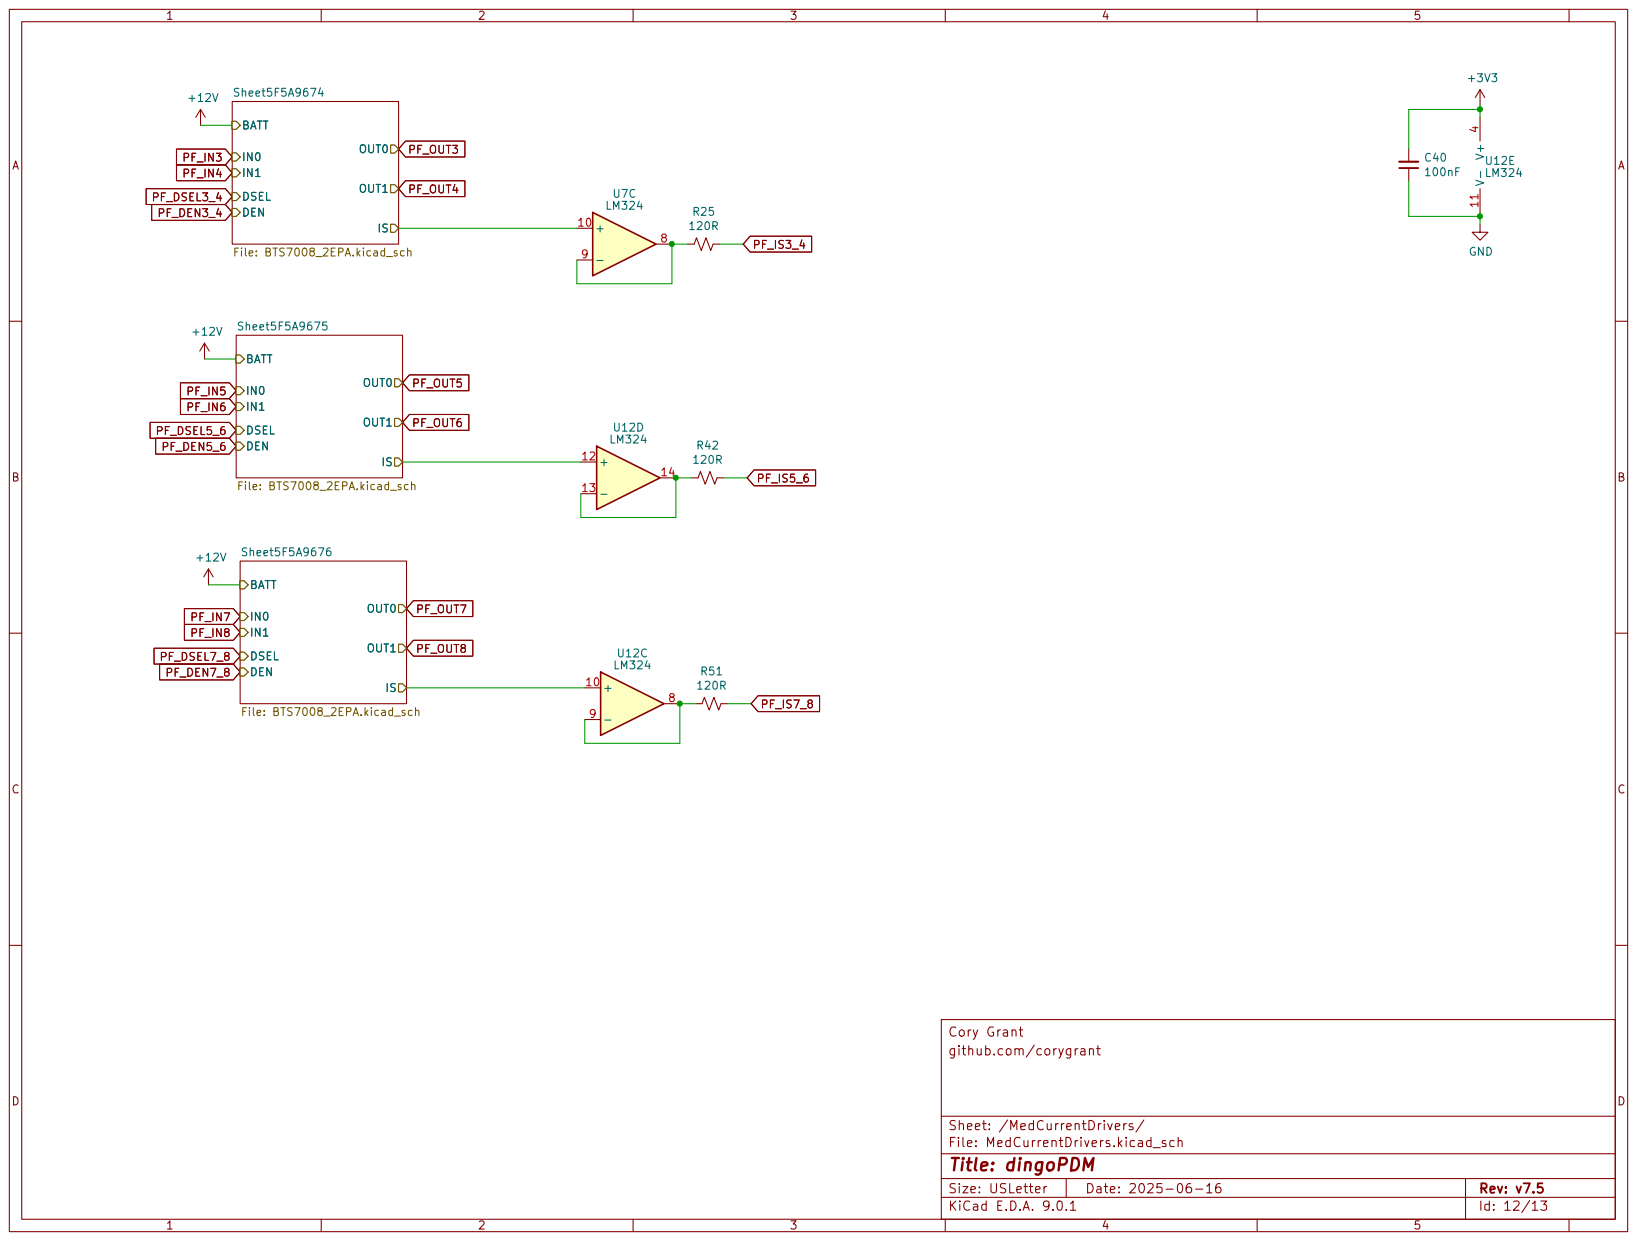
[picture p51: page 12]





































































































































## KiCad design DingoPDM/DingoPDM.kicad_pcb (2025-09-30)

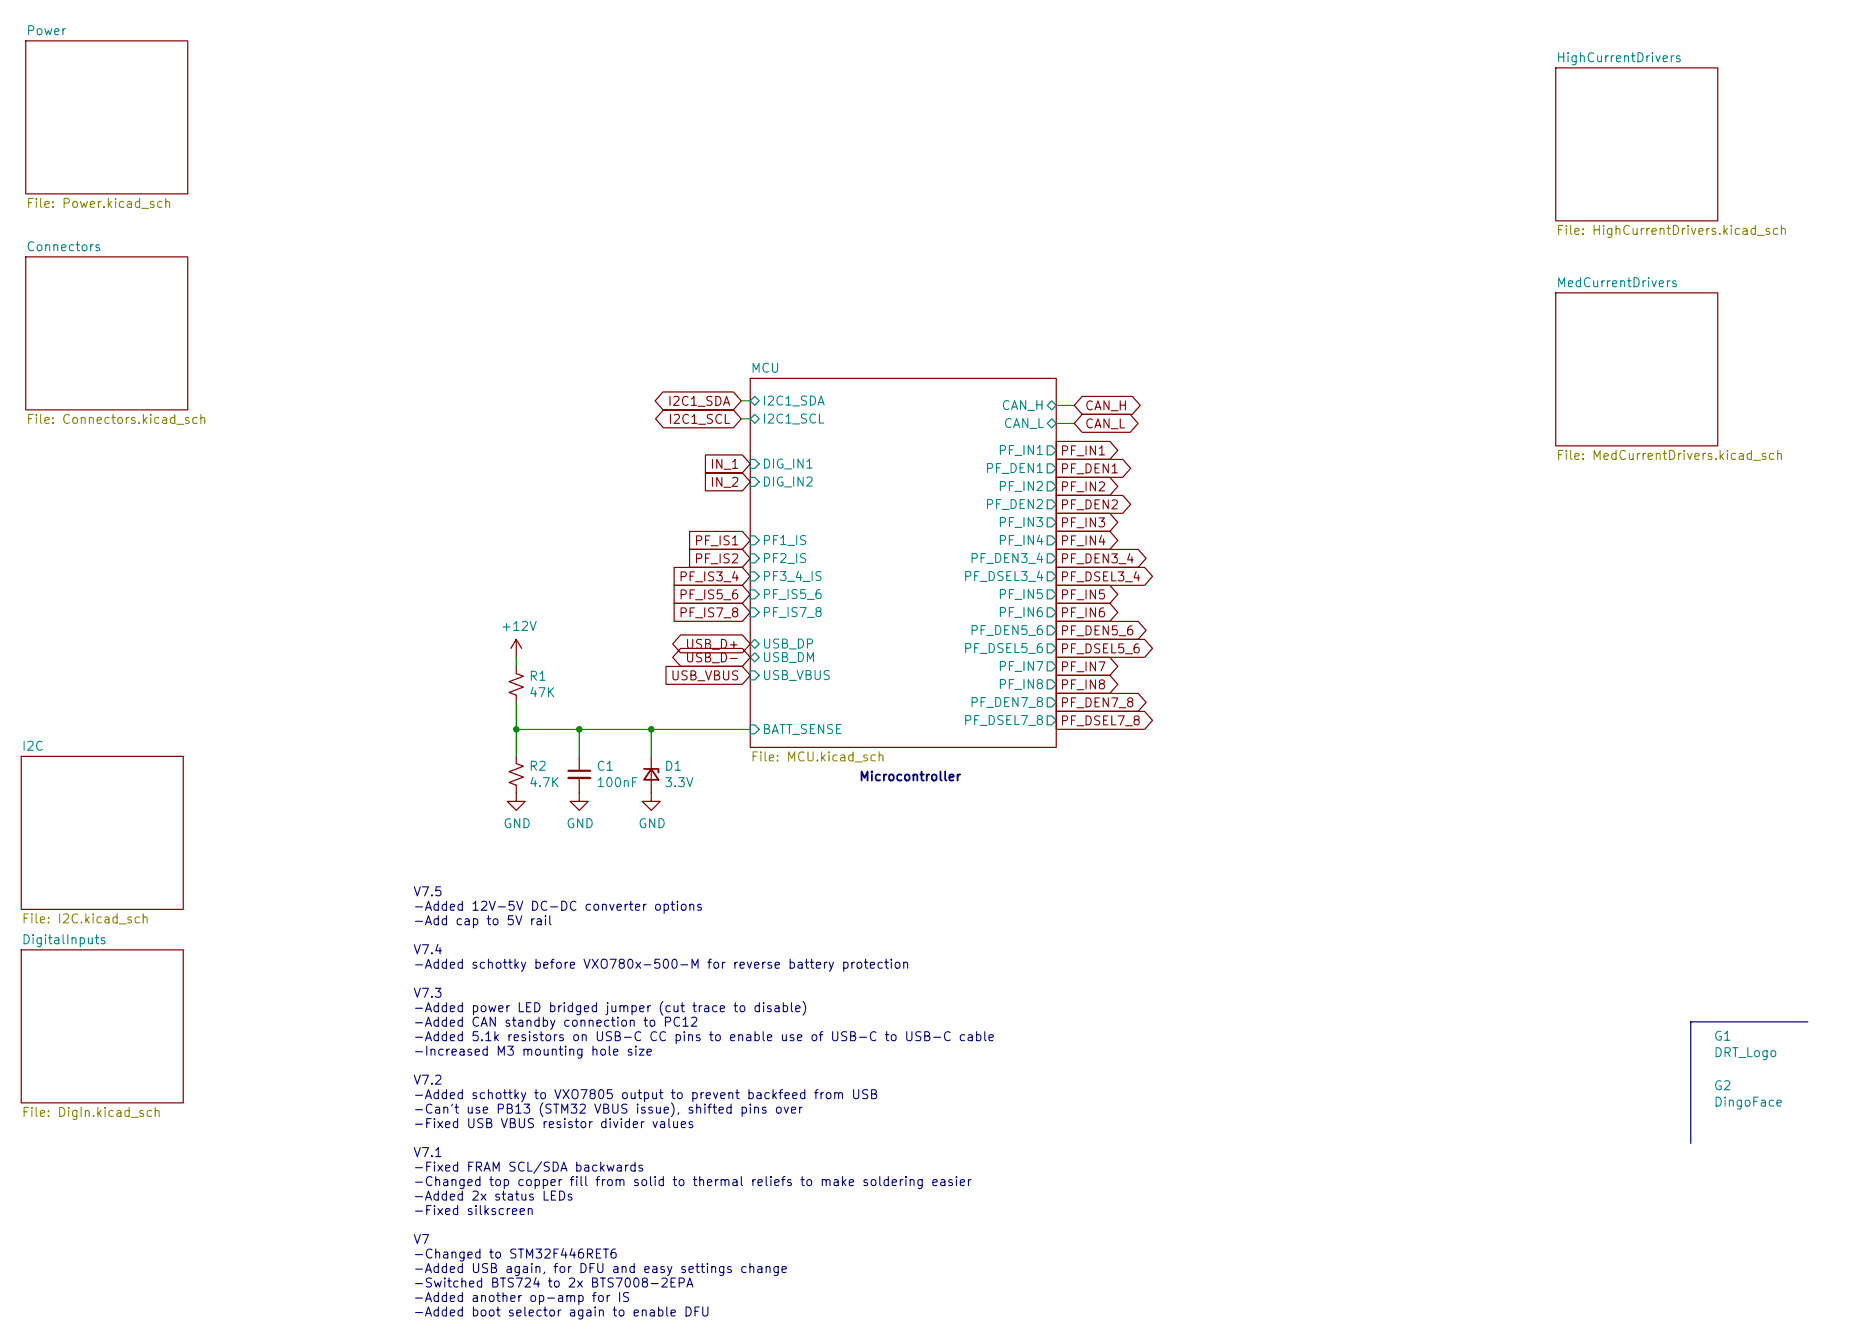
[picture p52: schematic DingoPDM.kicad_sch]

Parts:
C1: 100nF; C_0805_2012Metric; Digi-Key_PN 478-1395-1-ND
D1: 3.3V; D_SOD-323_HandSoldering; Digi-Key_PN 1727-5150-1-ND
G1: DRT_Logo; DRTLogo
G2: DingoFace; DingoFaceNoFill
R1: 47K; R_0805_2012Metric; Digi-Key_PN 311-47.0KCRCT-ND
R2: 4.7K; R_0805_2012Metric; Digi-Key_PN 311-4.70KCRCT-ND

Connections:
+12V: R1.1; also elsewhere on the board
/MCU/BATT_SENSE: C1.1, D1.1 (K), R1.2, R2.1; also elsewhere on the board
GND: C1.2, D1.2 (A), R2.2; also elsewhere on the board

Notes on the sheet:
Microcontroller
V7.5 -Added 12V-5V DC-DC converter options -Add cap to 5V rail V7.4 -Added schottky before VXO780x-500-M for reverse battery protection V7.3 -Added power LED bridged jumper (cut trace to disable) -Added CAN standby connection to PC12 -Added 5.1k resistors on USB-C CC pins to enable use of USB-C to 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

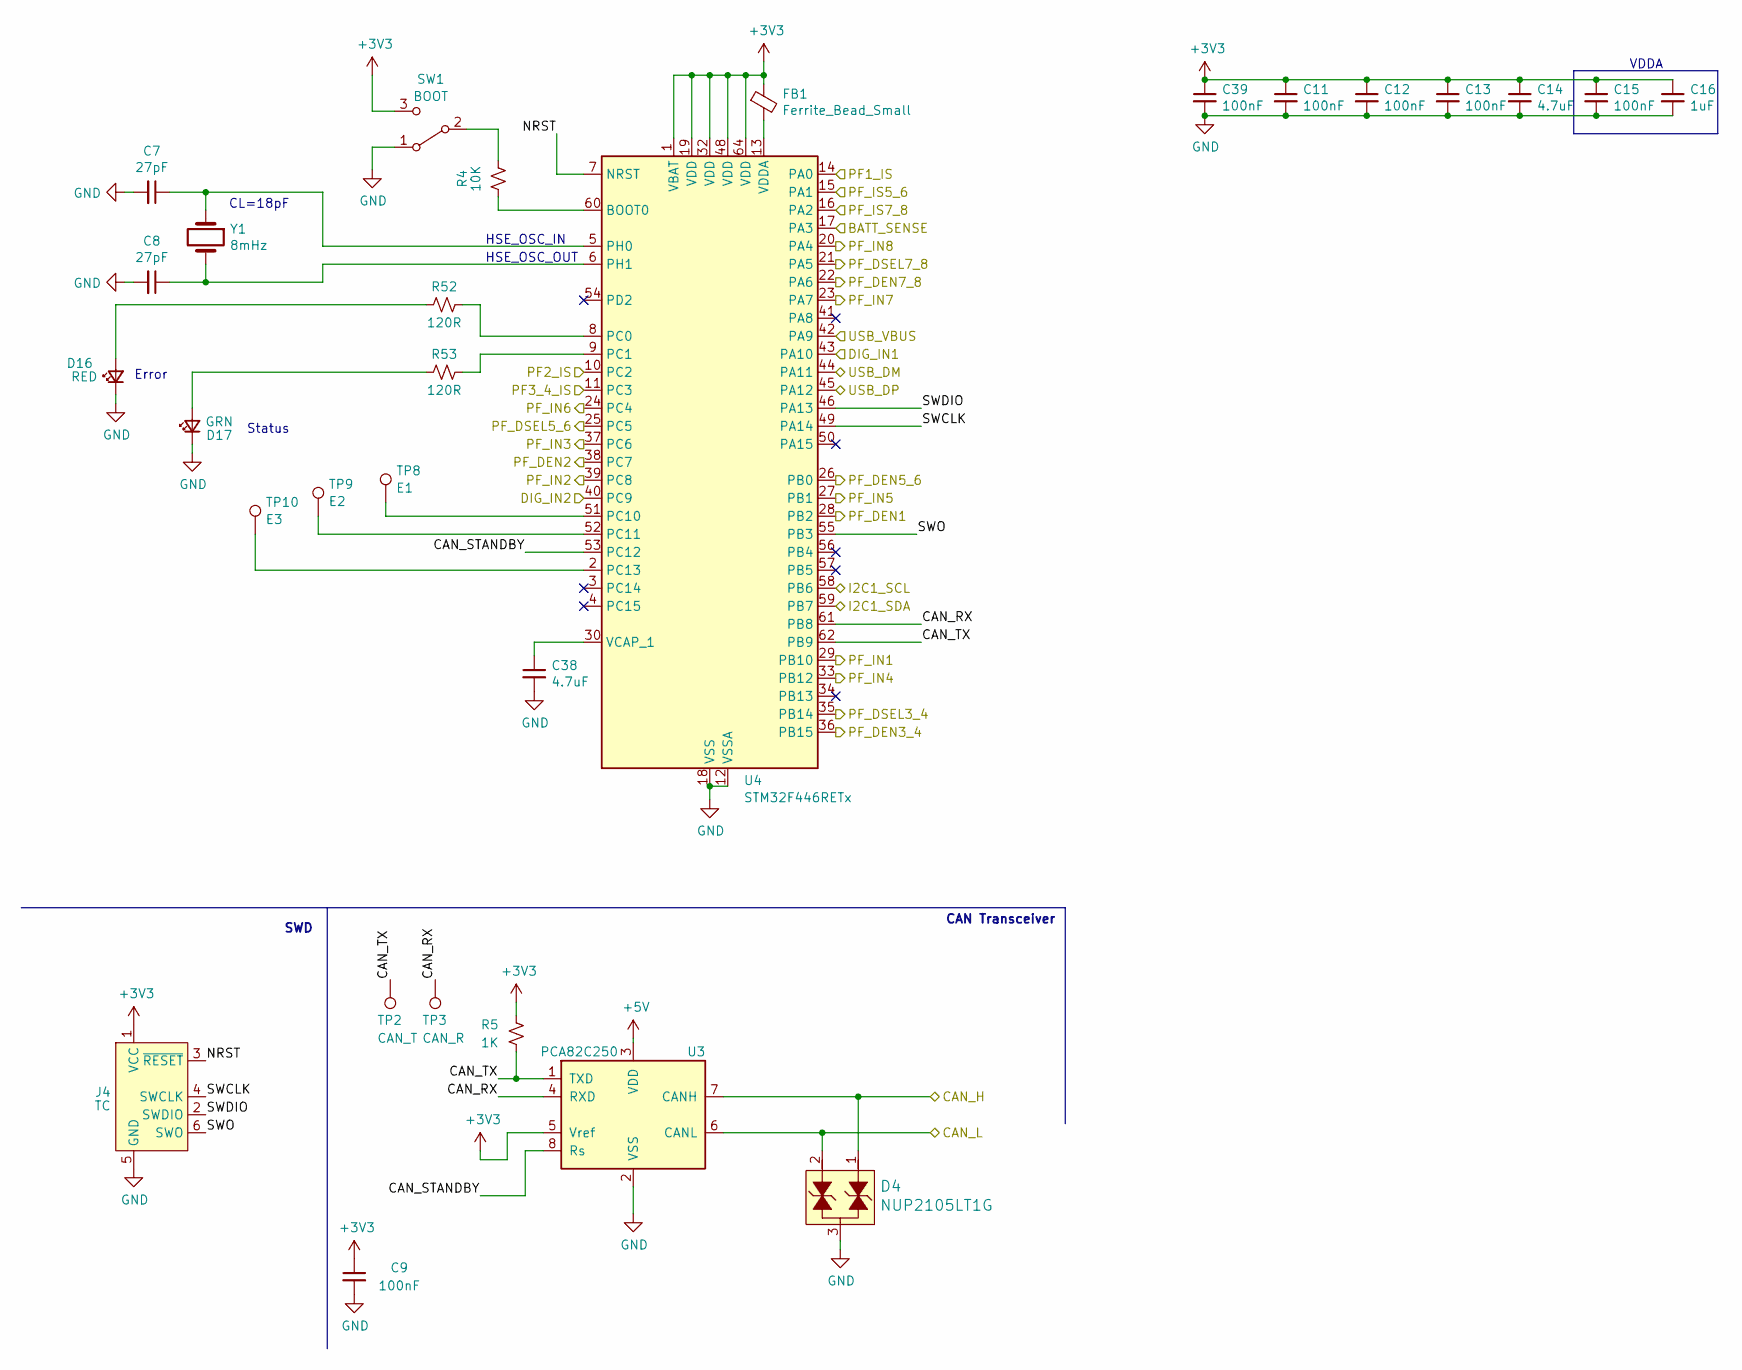
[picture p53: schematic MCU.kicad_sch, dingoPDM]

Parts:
C7, C8: 27pF; C_0805_2012Metric; Digi-Key_PN 478-10518-1-ND
C9, C11, C12, C13, C15, C39: 100nF; C_0805_2012Metric; Digi-Key_PN 478-1395-1-ND
C14, C38: 4.7uF; C_0805_2012Metric; Digi-Key_PN 1276-2873-1-ND
C16: 1uF; C_0805_2012Metric; Digi-Key_PN 311-1365-1-ND
D4: NUP2105LT1G; SOT-23-3; Digi-Key_PN NUP2105LT1GOSCT-ND
D16: RED; LED_0805_2012Metric; Digi-Key_PN 475-1278-1-ND
D17: GRN; LED_0805_2012Metric; Digi-Key_PN 475-1410-1-ND
FB1: Ferrite_Bead_Small; R_0805_2012Metric; Digi-Key_PN 490-1054-1-ND
J4: TC; Tag-Connect_TC2030-IDC-NL_2x03_P1.27mm_Vertical
R4: 10K; R_0805_2012Metric; Digi-Key_PN 311-10.0KCRDKR-ND
R5: 1K; R_0805_2012Metric; Digi-Key_PN 311-1.0KARCT-ND
R52, R53: 120R; R_0805_2012Metric; Digi-Key_PN 311-120CRCT-ND
SW1: BOOT; CJS-1200TB; Digi-Key_PN 563-CJS-1200TB1CT-ND
TP2: CAN_T; TestPoint_Keystone_5000-5004_Miniature
TP3: CAN_R; TestPoint_Keystone_5000-5004_Miniature
TP8: E1; TestPoint_Keystone_5000-5004_Miniature
TP9: E2; TestPoint_Keystone_5000-5004_Miniature
TP10: E3; TestPoint_Keystone_5000-5004_Miniature
U3: PCA82C250; SOIC-8_3.9x4.9mm_P1.27mm; Digi-Key_PN 568-10316-1-ND
U4: STM32F446RETx; LQFP-64_10x10mm_P0.5mm; Digi-Key_PN 497-15376-ND
Y1: 8mHz; Crystal_SMD_5032-2Pin_5.0x3.2mm_HandSoldering; Digi-Key_PN 535-10630-1-ND

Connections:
+3V3: C9.1, C11.1, C12.1, C13.1, C14.1, C15.1, C16.1, C39.1, FB1.1, J4.1 (VCC), R5.2, SW1.3 (C), U3.5 (Vref), U4.1 (VBAT), U4.19 (VDD), U4.32 (VDD), U4.48 (VDD), U4.64 (VDD); also elsewhere on the board
+5V: U3.3 (VDD); also elsewhere on the board
/MCU/BATT_SENSE: U4.17 (PA3); also elsewhere on the board
/MCU/CAN_RX: TP3.1, U3.4 (RXD), U4.61 (PB8)
/MCU/CAN_STANDBY: U3.8 (Rs), U4.53 (PC12)
/MCU/CAN_TX: R5.1, TP2.1, U3.1 (TXD), U4.62 (PB9)
/MCU/NRST: J4.3 (~RESET), U4.7 (NRST)
/MCU/SWCLK: J4.4 (SWCLK), U4.49 (PA14)
/MCU/SWDIO: J4.2 (SWDIO), U4.46 (PA13)
/MCU/SWO: J4.6 (SWO), U4.55 (PB3)
CAN_H: D4.1, U3.7 (CANH); also elsewhere on the board
CAN_L: D4.2, U3.6 (CANL); also elsewhere on the board
GND: C7.2, C8.2, C9.2, C11.2, C12.2, C13.2, C14.2, C15.2, C16.2, C38.2, C39.2, D4.3, D16.1 (K), D17.1 (K), J4.5 (GND), SW1.1 (A), U3.2 (VSS), U4.12 (VSSA), U4.18 (VSS), U4.31 (VSS), U4.47 (VSS), U4.63 (VSS); also elsewhere on the board
I2C1_SCL: U4.58 (PB6); also elsewhere on the board
I2C1_SDA: U4.59 (PB7); also elsewhere on the board
IN_1: U4.43 (PA10); also elsewhere on the board
IN_2: U4.40 (PC9); also elsewhere on the board
unnamed: D16.2 (A), R52.2
unnamed: D17.2 (A), R53.2
unnamed: R4.1, SW1.2 (B)
unnamed: R4.2, U4.60 (BOOT0)
unnamed: R52.1, U4.8 (PC0)
unnamed: R53.1, U4.9 (PC1)
unnamed: TP8.1, U4.51 (PC10)
unnamed: TP9.1, U4.52 (PC11)
unnamed: TP10.1, U4.2 (PC13)
unnamed: C7.1, U4.5 (PH0), Y1.1
unnamed: C8.1, U4.6 (PH1), Y1.2
unnamed: C38.1, U4.30 (VCAP_1)
unnamed: FB1.2, U4.13 (VDDA)
PF_DEN1: U4.28 (PB2); also elsewhere on the board
PF_DEN2: U4.38 (PC7); also elsewhere on the board
PF_DEN3_4: U4.36 (PB15); also elsewhere on the board
PF_DEN5_6: U4.26 (PB0); also elsewhere on the board
PF_DEN7_8: U4.22 (PA6); also elsewhere on the board
PF_DSEL3_4: U4.35 (PB14); also elsewhere on the board
PF_DSEL5_6: U4.25 (PC5); also elsewhere on the board
PF_DSEL7_8: U4.21 (PA5); also elsewhere on the board
PF_IN1: U4.29 (PB10); also elsewhere on the board
PF_IN2: U4.39 (PC8); also elsewhere on the board
PF_IN3: U4.37 (PC6); also elsewhere on the board
PF_IN4: U4.33 (PB12); also elsewhere on the board
PF_IN5: U4.27 (PB1); also elsewhere on the board
PF_IN6: U4.24 (PC4); also elsewhere on the board
PF_IN7: U4.23 (PA7); also elsewhere on the board
PF_IN8: U4.20 (PA4); also elsewhere on the board
PF_IS1: U4.14 (PA0); also elsewhere on the board
PF_IS2: U4.10 (PC2); also elsewhere on the board
PF_IS3_4: U4.11 (PC3); also elsewhere on the board
PF_IS5_6: U4.15 (PA1); also elsewhere on the board
PF_IS7_8: U4.16 (PA2); also elsewhere on the board
USB_D+: U4.45 (PA12); also elsewhere on the board
USB_D-: U4.44 (PA11); also elsewhere on the board
USB_VBUS: U4.42 (PA9); also elsewhere on the board

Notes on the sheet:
SWD
Error
CAN Transceiver
HSE_OSC_IN
CL=18pF
HSE_OSC_OUT
VDDA
Status

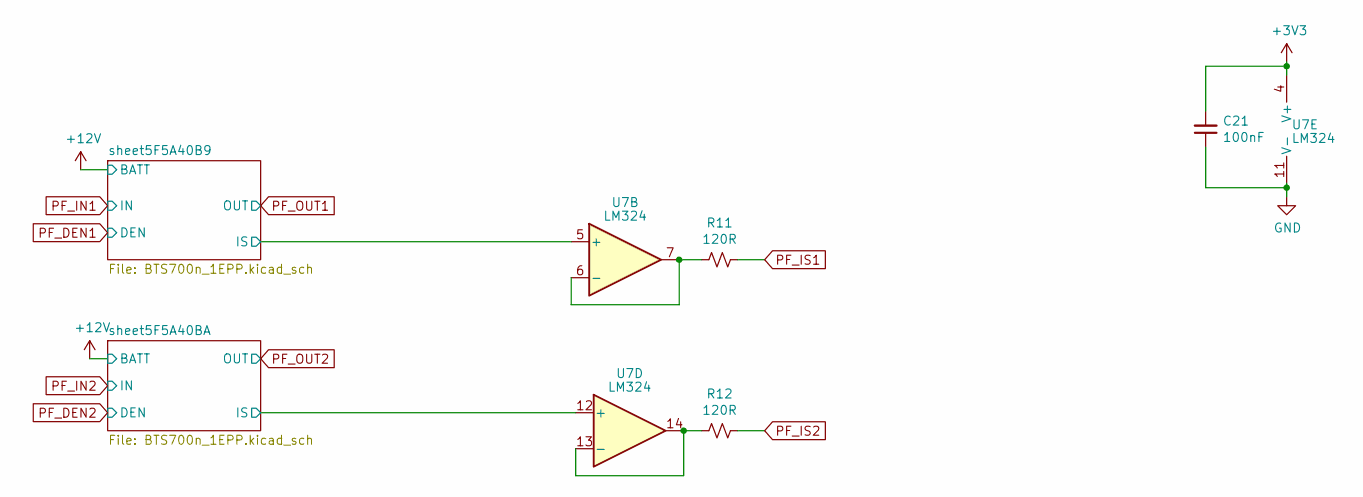
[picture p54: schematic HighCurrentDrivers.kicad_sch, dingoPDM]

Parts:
C21: 100nF; C_0805_2012Metric; Digi-Key_PN 478-1395-1-ND
R11, R12: 120R; R_0805_2012Metric; Digi-Key_PN 311-120CRCT-ND
U7: LM324; TSSOP-14_4.4x5mm_P0.65mm; Digi-Key_PN 497-7330-1-ND

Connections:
+3V3: C21.2, U7.4 (V+); also elsewhere on the board
/HighCurrentDrivers/sheet5F5A40B9/IS: U7.5 (+); also elsewhere on the board
/HighCurrentDrivers/sheet5F5A40BA/IS: U7.12 (+); also elsewhere on the board
GND: C21.1, U7.11 (V-); also elsewhere on the board
unnamed: R11.2, U7.6 (-), U7.7
unnamed: R12.2, U7.13 (-), U7.14
PF_IS1: R11.1; also elsewhere on the board
PF_IS2: R12.1; also elsewhere on the board

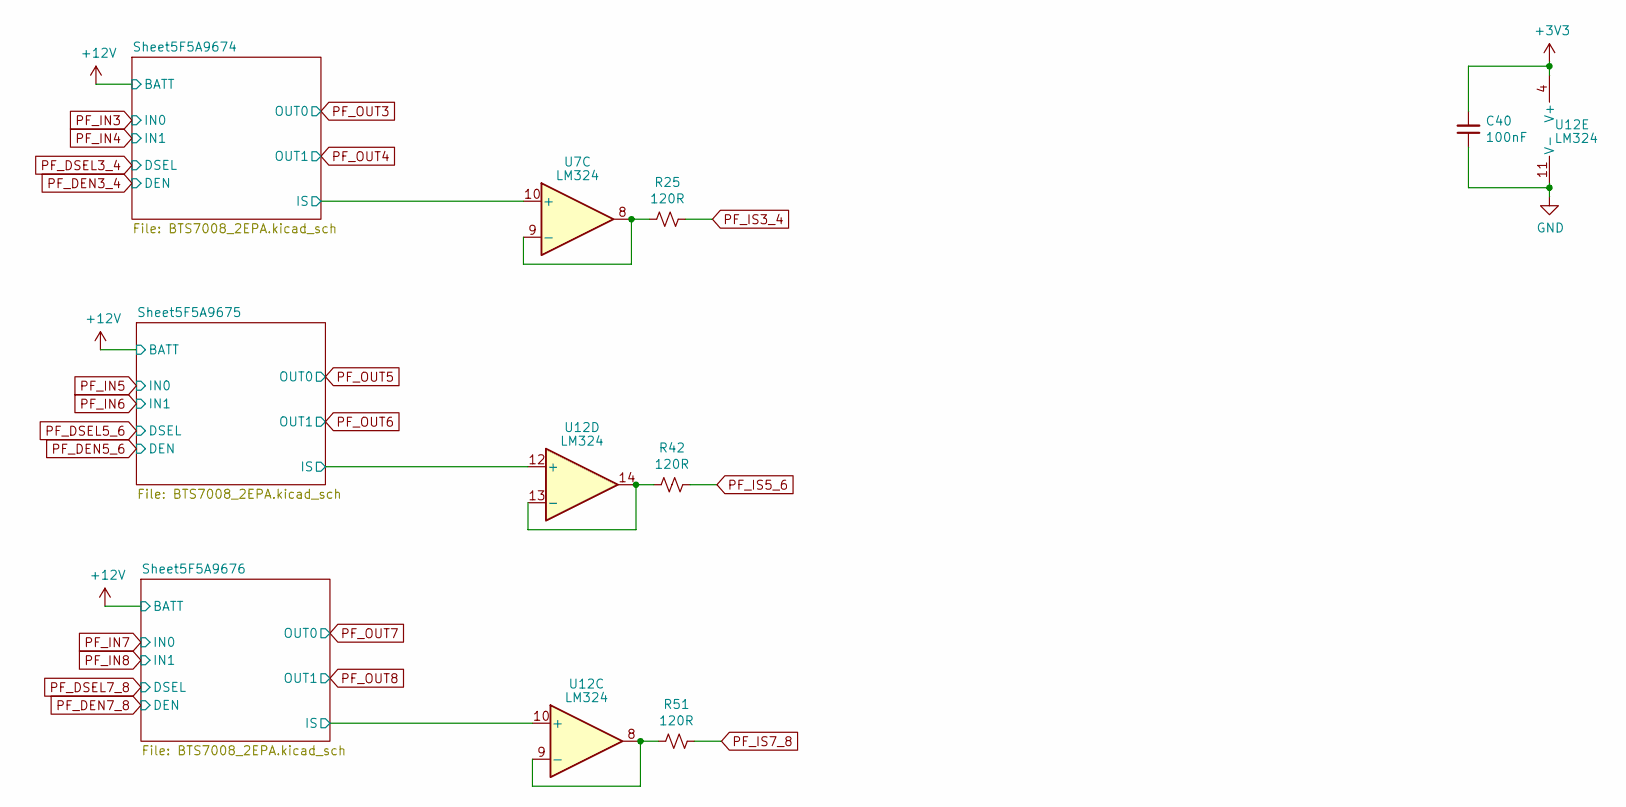
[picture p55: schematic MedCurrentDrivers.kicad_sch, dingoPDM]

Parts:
C40: 100nF; C_0805_2012Metric; Digi-Key_PN 478-1395-1-ND
R25, R42, R51: 120R; R_0805_2012Metric; Digi-Key_PN 311-120CRCT-ND
U7, U12: LM324; TSSOP-14_4.4x5mm_P0.65mm; Digi-Key_PN 497-7330-1-ND

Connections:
+3V3: C40.2, U12.4 (V+); also elsewhere on the board
/MedCurrentDrivers/Sheet5F5A9674/IS: U7.10 (+); also elsewhere on the board
/MedCurrentDrivers/Sheet5F5A9675/IS: U12.12 (+); also elsewhere on the board
/MedCurrentDrivers/Sheet5F5A9676/IS: U12.10 (+); also elsewhere on the board
GND: C40.1, U12.11 (V-); also elsewhere on the board
unnamed: R25.2, U7.8, U7.9 (-)
unnamed: R51.2, U12.8, U12.9 (-)
unnamed: R42.2, U12.13 (-), U12.14
PF_IS3_4: R25.1; also elsewhere on the board
PF_IS5_6: R42.1; also elsewhere on the board
PF_IS7_8: R51.1; also elsewhere on the board

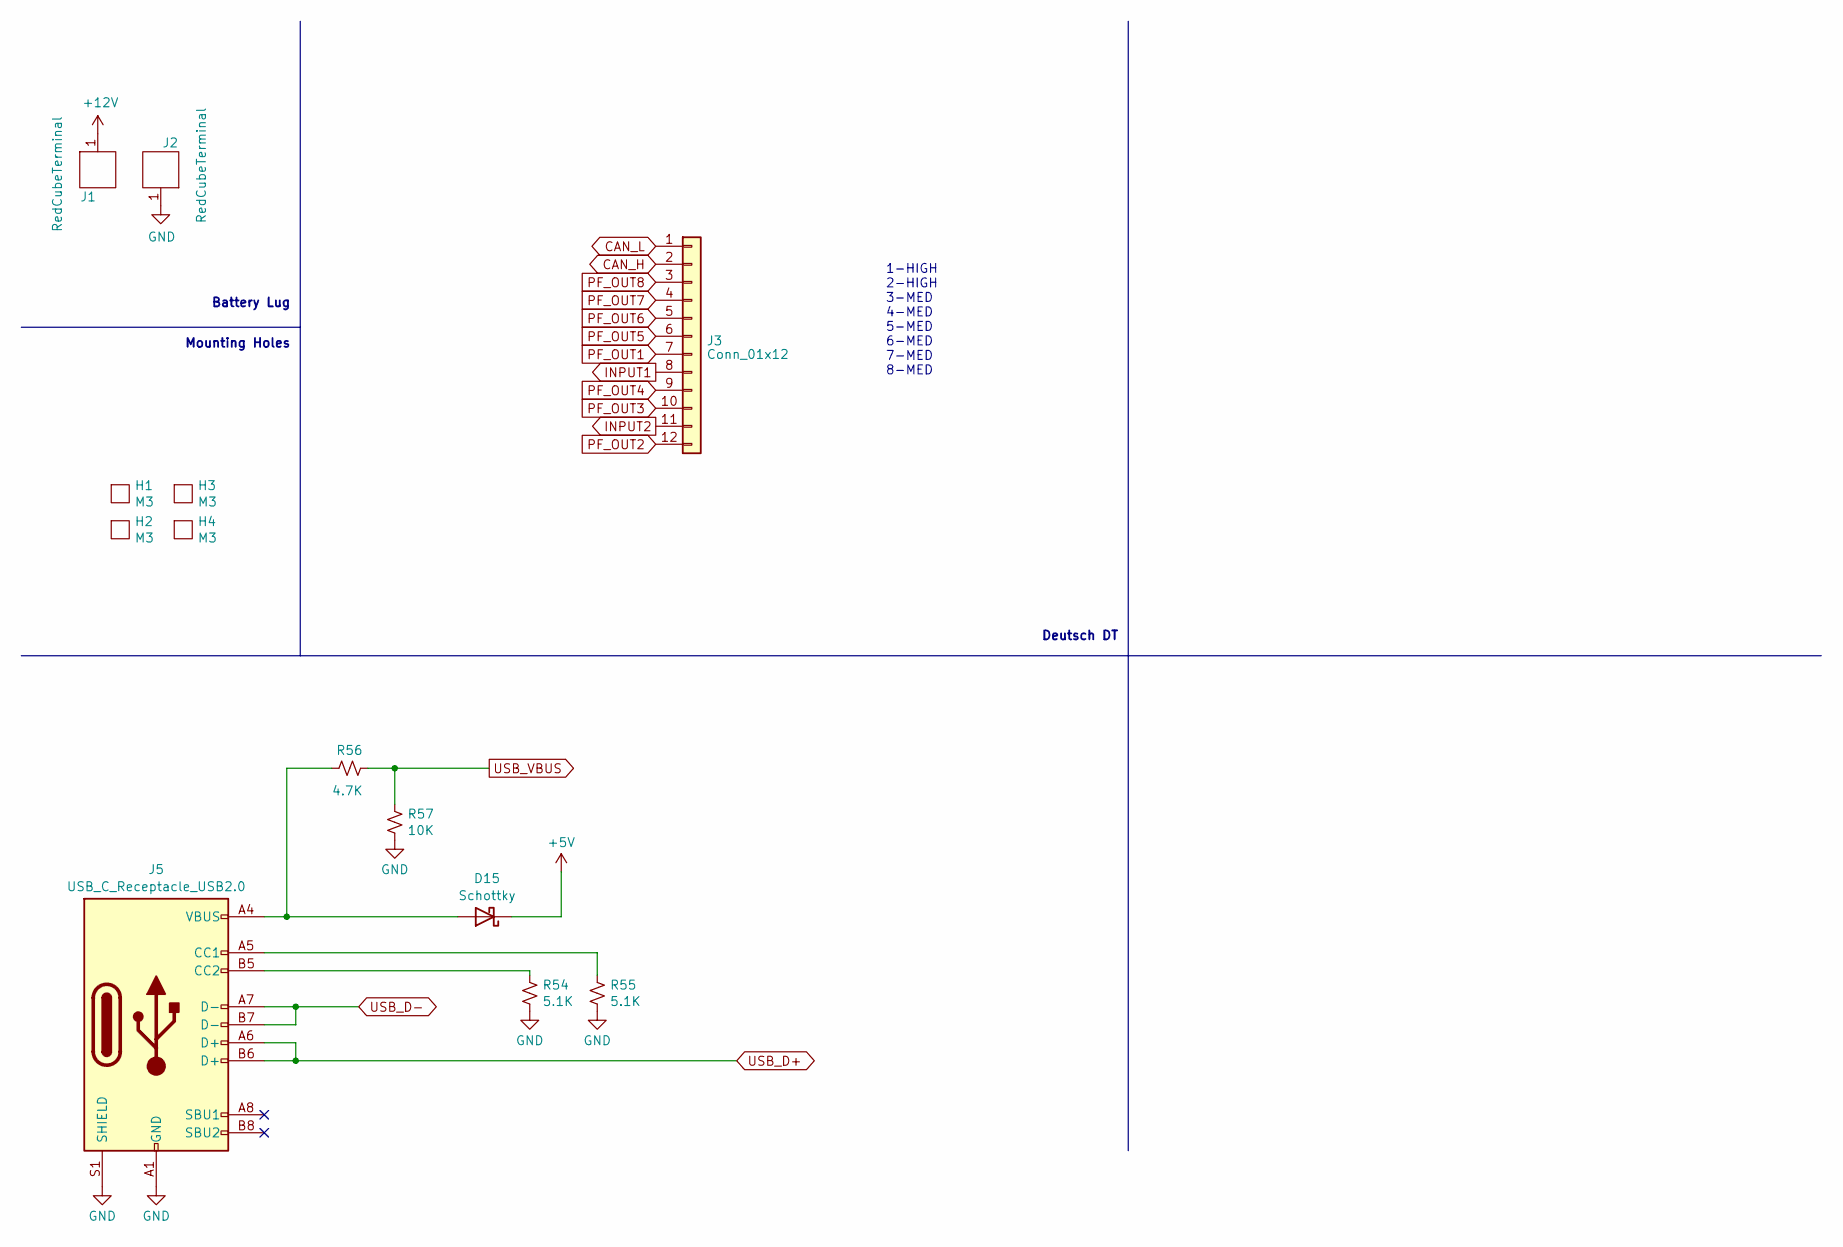
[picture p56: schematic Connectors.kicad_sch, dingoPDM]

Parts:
D15: Schottky; D_SOD-123; Digi-Key_PN 1727-2394-1-ND
H1, H2, H3, H4: M3; MountingHole_3.2mm_M3_ISO7380_Pad
J1, J2: RedCubeTerminal; M6_Hole_8Pin_7461084; Digi-Key_PN 732-3203-ND
J3: Conn_01x12; DT15-12PA; LCSC C5341788
J5: USB_C_Receptacle_USB2.0; USB_C_Receptacle_GCT_USB4085; Digi-Key_PN 2073-USB4085-GF-ACT-ND
R54, R55: 5.1K; R_0805_2012Metric; Digi-Key_PN 311-5.1KARCT-ND
R56: 4.7K; R_0805_2012Metric; Digi-Key_PN 311-4.70KCRCT-ND
R57: 10K; R_0805_2012Metric; Digi-Key_PN 311-10.0KCRDKR-ND

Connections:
+5V: D15.1 (K); also elsewhere on the board
+12V: J1.1; also elsewhere on the board
CAN_H: J3.2; also elsewhere on the board
CAN_L: J3.1; also elsewhere on the board
GND: J2.1, J5.A1 (GND), J5.A12 (GND), J5.B1 (GND), J5.B12 (GND), J5.S1 (SHIELD), R54.2, R55.2, R57.2; also elsewhere on the board
INPUT1: J3.8; also elsewhere on the board
INPUT2: J3.11; also elsewhere on the board
unnamed: D15.2 (A), J5.A4 (VBUS), J5.A9 (VBUS), J5.B4 (VBUS), J5.B9 (VBUS), R56.1
unnamed: J5.A5 (CC1), R55.1
unnamed: J5.B5 (CC2), R54.1
PF_OUT1: J3.7; also elsewhere on the board
PF_OUT2: J3.12; also elsewhere on the board
PF_OUT3: J3.10; also elsewhere on the board
PF_OUT4: J3.9; also elsewhere on the board
PF_OUT5: J3.6; also elsewhere on the board
PF_OUT6: J3.5; also elsewhere on the board
PF_OUT7: J3.4; also elsewhere on the board
PF_OUT8: J3.3; also elsewhere on the board
USB_D+: J5.A6 (D+), J5.B6 (D+); also elsewhere on the board
USB_D-: J5.A7 (D-), J5.B7 (D-); also elsewhere on the board
USB_VBUS: R56.2, R57.1; also elsewhere on the board

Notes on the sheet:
1-HIGH 2-HIGH 3-MED 4-MED 5-MED 6-MED 7-MED 8-MED
Deutsch DT
Battery Lug
Mounting Holes

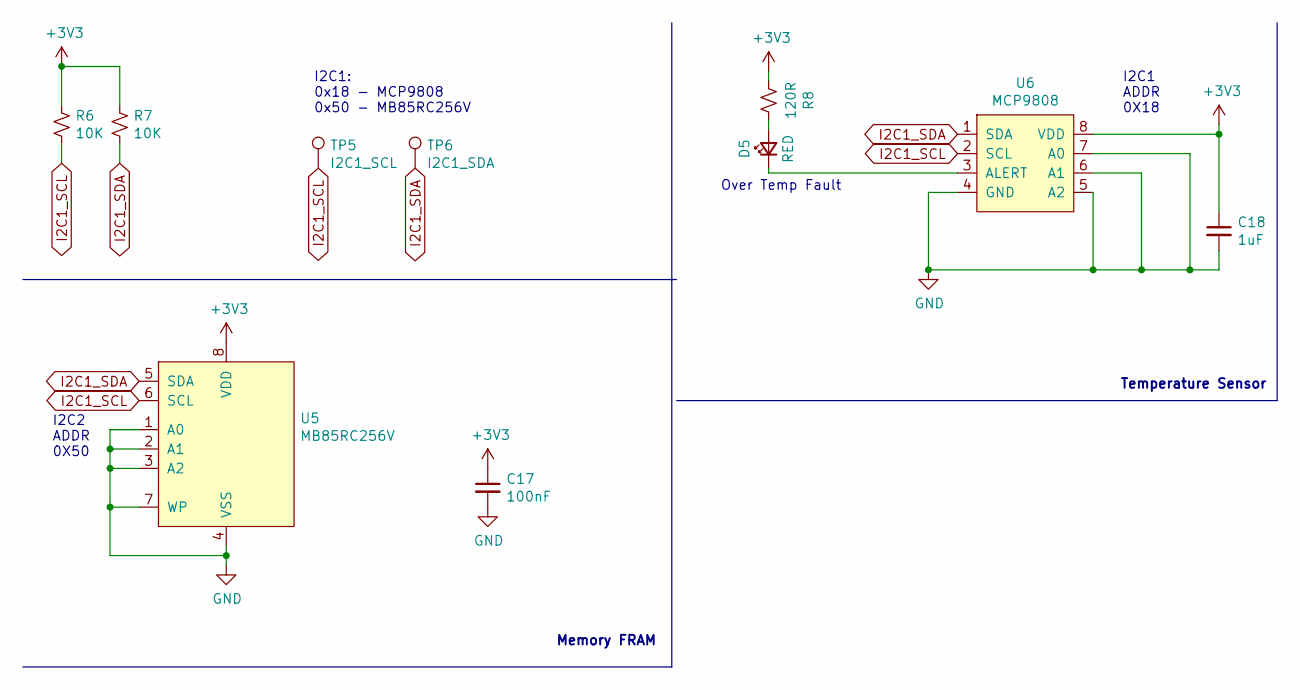
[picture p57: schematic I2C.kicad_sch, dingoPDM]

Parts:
C17: 100nF; C_0805_2012Metric; Digi-Key_PN 478-1395-1-ND
C18: 1uF; C_0805_2012Metric; Digi-Key_PN 311-1365-1-ND
D5: RED; LED_0805_2012Metric; Digi-Key_PN 475-1278-1-ND
R6, R7: 10K; R_0805_2012Metric; Digi-Key_PN 311-10.0KCRDKR-ND
R8: 120R; R_0805_2012Metric; Digi-Key_PN 311-120CRCT-ND
TP5: I2C1_SCL; TestPoint_Keystone_5000-5004_Miniature
TP6: I2C1_SDA; TestPoint_Keystone_5000-5004_Miniature
U5: MB85RC256V; SOIC-8_3.9x4.9mm_P1.27mm; Digi-Key_PN 865-1261-1-ND
U6: MCP9808; MSOP-8_3x3mm_P0.65mm; Digi-Key_PN MCP9808T-E/MSCT-ND

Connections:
+3V3: C17.1, C18.1, R6.1, R7.1, R8.2, U5.8 (VDD), U6.8 (VDD); also elsewhere on the board
GND: C17.2, C18.2, U5.1 (A0), U5.2 (A1), U5.3 (A2), U5.4 (VSS), U5.7 (WP), U6.4 (GND), U6.5 (A2), U6.6 (A1), U6.7 (A0); also elsewhere on the board
I2C1_SCL: R6.2, TP5.1, U5.6 (SCL), U6.2 (SCL); also elsewhere on the board
I2C1_SDA: R7.2, TP6.1, U5.5 (SDA), U6.1 (SDA); also elsewhere on the board
unnamed: D5.2 (A), R8.1
unnamed: D5.1 (K), U6.3 (ALERT)

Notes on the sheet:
I2C1 ADDR 0X18
I2C2 ADDR 0X50
Over Temp Fault
Temperature Sensor
I2C1: 0x18 - MCP9808 0x50 - MB85RC256V
Memory FRAM

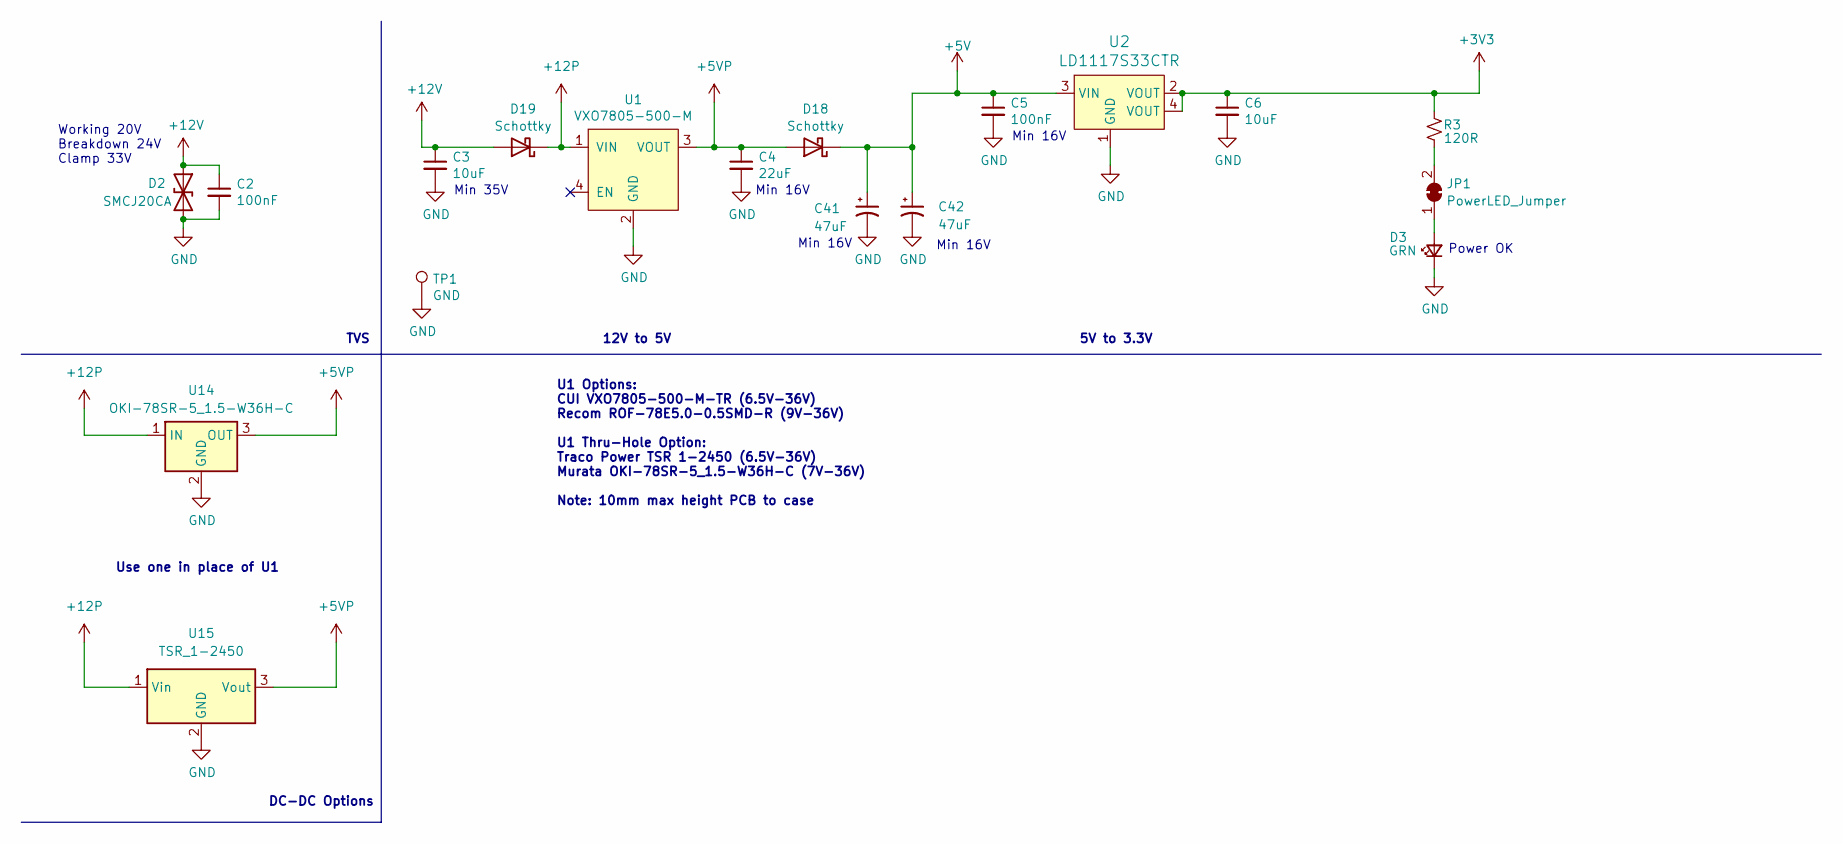
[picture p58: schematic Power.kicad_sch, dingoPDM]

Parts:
C2, C5: 100nF; C_0805_2012Metric; Digi-Key_PN 478-1395-1-ND
C3, C6: 10uF; C_0805_2012Metric; Digi-Key_PN 445-11516-1-ND
C4: 22uF; C_0805_2012Metric; Digi-Key_PN 490-10749-1-ND
C41, C42: 47uF; C_2220_5750Metric; Digi-Key_PN 445-7935-1-ND
D2: SMCJ20CA; DO-214AB_TVS; Digi-Key_PN SMCJ20CABCT-ND
D3: GRN; LED_0805_2012Metric; Digi-Key_PN 475-1410-1-ND
D18, D19: Schottky; D_SOD-123; Digi-Key_PN 1727-2394-1-ND
JP1: PowerLED_Jumper; SolderJumper-2_P1.3mm_Bridged_RoundedPad1.0x1.5mm
R3: 120R; R_0805_2012Metric; Digi-Key_PN 311-120CRCT-ND
TP1: GND; TestPoint_Keystone_5000-5004_Miniature
U1: VXO7805-500-M; VXO78x-500-M; Digi-Key_PN 102-VXO7805-500-M-CT-ND
U2: LD1117S33CTR; SOT-223; Digi-Key_PN 497-1241-1-ND
U14: OKI-78SR-5_1.5-W36H-C; Converter_DCDC_Murata_OKI-78SR_Horizontal; Digi-Key_PN 811-2692-ND
U15: TSR_1-2450; Converter_DCDC_TRACO_TSR-1_THT; Digi-Key_PN 1951-2747-ND

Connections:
+3V3: C6.1, R3.2, U2.2 (VOUT), U2.4 (VOUT); also elsewhere on the board
+5V: C5.1, C41.1, C42.1, D18.1 (K), U2.3 (VIN); also elsewhere on the board
+5VP: C4.1, D18.2 (A), U1.3 (VOUT), U14.3 (OUT), U15.3 (Vout)
+12P: D19.1 (K), U1.1 (VIN), U14.1 (IN), U15.1 (Vin)
+12V: C2.1, C3.1, D2.1 (A1), D19.2 (A); also elsewhere on the board
GND: C2.2, C3.2, C4.2, C5.2, C6.2, C41.2, C42.2, D2.2 (A2), D3.1 (K), TP1.1, U1.2 (GND), U2.1 (GND), U14.2 (GND), U15.2 (GND); also elsewhere on the board
unnamed: D3.2 (A), JP1.1 (A)
unnamed: JP1.2 (B), R3.1

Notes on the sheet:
Min 16V
TVS
Min 35V
Power OK
5V to 3.3V
U1 Options: CUI VXO7805-500-M-TR (6.5V-36V) Recom ROF-78E5.0-0.5SMD-R (9V-36V) U1 Thru-Hole Option: Traco Power TSR 1-2450 (6.5V-36V) Murata OKI-78SR-5_1.5-W36H-C (7V-36V) Note: 10mm max height PCB to case
12V to 5V
DC-DC Options
Use one in place of U1
Working 20V Breakdown 24V Clamp 33V

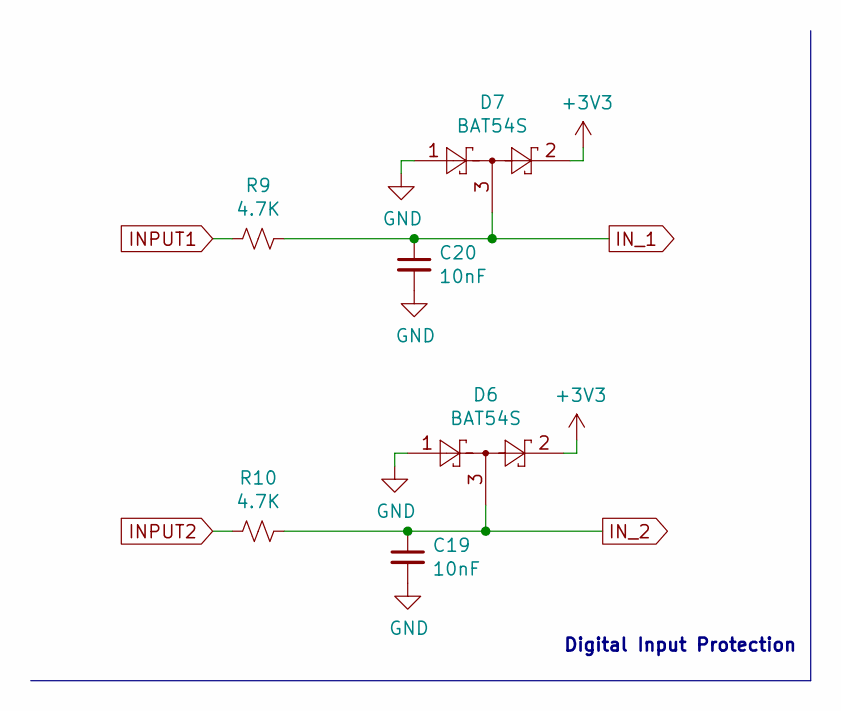
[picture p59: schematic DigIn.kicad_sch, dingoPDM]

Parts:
C19, C20: 10nF; C_0805_2012Metric; Digi-Key_PN 311-1136-1-ND
D6, D7: BAT54S; SOT-23; Digi-Key_PN BAT54SLT1GOSCT-ND
R9, R10: 4.7K; R_0805_2012Metric; Digi-Key_PN 311-4.70KCRCT-ND

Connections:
+3V3: D6.2, D7.2; also elsewhere on the board
GND: C19.2, C20.2, D6.1, D7.1; also elsewhere on the board
INPUT1: R9.2; also elsewhere on the board
INPUT2: R10.2; also elsewhere on the board
IN_1: C20.1, D7.3, R9.1; also elsewhere on the board
IN_2: C19.1, D6.3, R10.1; also elsewhere on the board

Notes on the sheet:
Digital Input Protection

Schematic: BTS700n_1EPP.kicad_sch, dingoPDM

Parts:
C22: 47nF; C_0805_2012Metric; Digi-Key_PN 399-1166-1-ND
C23: 100nF; C_0805_2012Metric; Digi-Key_PN 478-1395-1-ND
C24: 10nF; C_0805_2012Metric; Digi-Key_PN 311-1136-1-ND
C25: 220pF; C_0805_2012Metric; Digi-Key_PN 399-1138-1-ND
D8: BYG23M; DO-214AC; Digi-Key_PN BYG23M-E3/TR3GICT-ND
D9: 3.3V; D_SOD-323_HandSoldering; Digi-Key_PN 1727-5150-1-ND
R13, R14, R17, R18: 4.7K; R_0805_2012Metric; Digi-Key_PN 311-4.70KCRCT-ND
R15: 1.2K; R_0805_2012Metric; Digi-Key_PN 311-1.20KCRCT-ND
R16: 47R 1/4W; R_1206_3216Metric; Digi-Key_PN 311-47.0FRCT-ND
U8: BTS700n-1EPP; TDSO-14; Digi-Key_PN BTS70021EPPXUMA1CT-ND

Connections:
+12V: C22.2, C23.2, U8.15 (VS); also elsewhere on the board
/HighCurrentDrivers/sheet5F5A40B9/IS: C25.2, R18.1; also elsewhere on the board
GND: C23.1, C24.1, C25.1, D8.A, D9.2 (A), R15.2, R16.1; also elsewhere on the board
unnamed: D9.1 (K), R17.1, R18.2
unnamed: R14.1, U8.3 (DEN)
unnamed: C22.1, R16.2, U8.1 (GND)
unnamed: R13.1, U8.2 (IN)
unnamed: R15.1, R17.2, U8.4 (IS)
PF_DEN1: R14.2; also elsewhere on the board
PF_IN1: R13.2; also elsewhere on the board
PF_OUT1: C24.2, D8.K, U8.8 (OUT1), U8.9 (OUT2), U8.10 (OUT3), U8.11 (NC4), U8.12 (OUT4), U8.13 (OUT5), U8.14 (OUT6); also elsewhere on the board

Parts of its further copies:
C26: 47nF; C_0805_2012Metric; Digi-Key_PN 399-1166-1-ND
C27: 100nF; C_0805_2012Metric; Digi-Key_PN 478-1395-1-ND
C28: 10nF; C_0805_2012Metric; Digi-Key_PN 311-1136-1-ND
C29: 220pF; C_0805_2012Metric; Digi-Key_PN 399-1138-1-ND
D10: BYG23M; DO-214AC; Digi-Key_PN BYG23M-E3/TR3GICT-ND
D11: 3.3V; D_SOD-323_HandSoldering; Digi-Key_PN 1727-5150-1-ND
R19, R20, R23, R24: 4.7K; R_0805_2012Metric; Digi-Key_PN 311-4.70KCRCT-ND
R21: 1.2K; R_0805_2012Metric; Digi-Key_PN 311-1.20KCRCT-ND
R22: 47R 1/4W; R_1206_3216Metric; Digi-Key_PN 311-47.0FRCT-ND
U9: BTS700n-1EPP; TDSO-14; Digi-Key_PN BTS70021EPPXUMA1CT-ND

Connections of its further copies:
+12V: C26.2, C27.2, U9.15 (VS); also elsewhere on the board
/HighCurrentDrivers/sheet5F5A40BA/IS: C29.2, R24.1; also elsewhere on the board
GND: C27.1, C28.1, C29.1, D10.A, D11.2 (A), R21.2, R22.1; also elsewhere on the board
unnamed: D11.1 (K), R23.1, R24.2
unnamed: R20.1, U9.3 (DEN)
unnamed: C26.1, R22.2, U9.1 (GND)
unnamed: R19.1, U9.2 (IN)
unnamed: R21.1, R23.2, U9.4 (IS)
PF_DEN2: R20.2; also elsewhere on the board
PF_IN2: R19.2; also elsewhere on the board
PF_OUT2: C28.2, D10.K, U9.8 (OUT1), U9.9 (OUT2), U9.10 (OUT3), U9.11 (NC4), U9.12 (OUT4), U9.13 (OUT5), U9.14 (OUT6); also elsewhere on the board

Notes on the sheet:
RC Filter
Flyback

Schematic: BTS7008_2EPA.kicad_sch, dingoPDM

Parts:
C10: 47nF; C_0805_2012Metric; Digi-Key_PN 399-1166-1-ND
C33: 100nF; C_0805_2012Metric; Digi-Key_PN 478-1395-1-ND
C34: 220pF; C_0805_2012Metric; Digi-Key_PN 399-1138-1-ND
D13: 3.3V; D_SOD-323_HandSoldering; Digi-Key_PN 1727-5150-1-ND
R34, R35, R36, R37, R40, R41: 4.7K; R_0805_2012Metric; Digi-Key_PN 311-4.70KCRCT-ND
R38: 1.2K; R_0805_2012Metric; Digi-Key_PN 311-1.20KCRCT-ND
R39: 47R 1/4W; R_1206_3216Metric; Digi-Key_PN 311-47.0FRCT-ND
U10: BTS7008-2EPA; TDSO-14; Digi-Key_PN BTS70082EPAXUMA1CT-ND

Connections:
+12V: C10.2, C33.2, U10.15 (VS); also elsewhere on the board
/MedCurrentDrivers/Sheet5F5A9675/IS: C34.2, R41.1; also elsewhere on the board
GND: C33.1, C34.1, D13.2 (A), R38.2, R39.1; also elsewhere on the board
unnamed: D13.1 (K), R40.1, R41.2
unnamed: R35.1, U10.3 (DEN)
unnamed: R36.2, U10.5 (DSEL)
unnamed: C10.1, R39.2, U10.1 (GND)
unnamed: R34.1, U10.2 (IN0)
unnamed: R37.1, U10.6 (IN1)
unnamed: R38.1, R40.2, U10.4 (IS)
PF_DEN5_6: R35.2; also elsewhere on the board
PF_DSEL5_6: R36.1; also elsewhere on the board
PF_IN5: R34.2; also elsewhere on the board
PF_IN6: R37.2; also elsewhere on the board
PF_OUT5: U10.12 (OUT0), U10.13 (OUT0), U10.14 (OUT0); also elsewhere on the board
PF_OUT6: U10.8 (OUT1), U10.9 (OUT1), U10.10 (OUT1); also elsewhere on the board

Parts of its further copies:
C30, C35: 47nF; C_0805_2012Metric; Digi-Key_PN 399-1166-1-ND
C31, C36: 100nF; C_0805_2012Metric; Digi-Key_PN 478-1395-1-ND
C32, C37: 220pF; C_0805_2012Metric; Digi-Key_PN 399-1138-1-ND
D12, D14: 3.3V; D_SOD-323_HandSoldering; Digi-Key_PN 1727-5150-1-ND
R26, R27, R28, R29, R32, R33, R43, R44, R45, R46, R49, R50: 4.7K; R_0805_2012Metric; Digi-Key_PN 311-4.70KCRCT-ND
R30, R47: 1.2K; R_0805_2012Metric; Digi-Key_PN 311-1.20KCRCT-ND
R31, R48: 47R 1/4W; R_1206_3216Metric; Digi-Key_PN 311-47.0FRCT-ND
U11, U13: BTS7008-2EPA; TDSO-14; Digi-Key_PN BTS70082EPAXUMA1CT-ND

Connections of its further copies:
+12V: C30.2, C31.2, C35.2, C36.2, U11.15 (VS), U13.15 (VS); also elsewhere on the board
/MedCurrentDrivers/Sheet5F5A9674/IS: C32.2, R33.1; also elsewhere on the board
/MedCurrentDrivers/Sheet5F5A9676/IS: C37.2, R50.1; also elsewhere on the board
GND: C31.1, C32.1, C36.1, C37.1, D12.2 (A), D14.2 (A), R30.2, R31.1, R47.2, R48.1; also elsewhere on the board
unnamed: D12.1 (K), R32.1, R33.2
unnamed: D14.1 (K), R49.1, R50.2
unnamed: R27.1, U11.3 (DEN)
unnamed: R28.2, U11.5 (DSEL)
unnamed: C30.1, R31.2, U11.1 (GND)
unnamed: R26.1, U11.2 (IN0)
unnamed: R29.1, U11.6 (IN1)
unnamed: R30.1, R32.2, U11.4 (IS)
unnamed: R44.1, U13.3 (DEN)
unnamed: R45.2, U13.5 (DSEL)
unnamed: C35.1, R48.2, U13.1 (GND)
unnamed: R43.1, U13.2 (IN0)
unnamed: R46.1, U13.6 (IN1)
unnamed: R47.1, R49.2, U13.4 (IS)
PF_DEN3_4: R27.2; also elsewhere on the board
PF_DEN7_8: R44.2; also elsewhere on the board
PF_DSEL3_4: R28.1; also elsewhere on the board
PF_DSEL7_8: R45.1; also elsewhere on the board
PF_IN3: R26.2; also elsewhere on the board
PF_IN4: R29.2; also elsewhere on the board
PF_IN7: R43.2; also elsewhere on the board
PF_IN8: R46.2; also elsewhere on the board
PF_OUT3: U11.12 (OUT0), U11.13 (OUT0), U11.14 (OUT0); also elsewhere on the board
PF_OUT4: U11.8 (OUT1), U11.9 (OUT1), U11.10 (OUT1); also elsewhere on the board
PF_OUT7: U13.12 (OUT0), U13.13 (OUT0), U13.14 (OUT0); also elsewhere on the board
PF_OUT8: U13.8 (OUT1), U13.9 (OUT1), U13.10 (OUT1); also elsewhere on the board

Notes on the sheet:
RC Filter

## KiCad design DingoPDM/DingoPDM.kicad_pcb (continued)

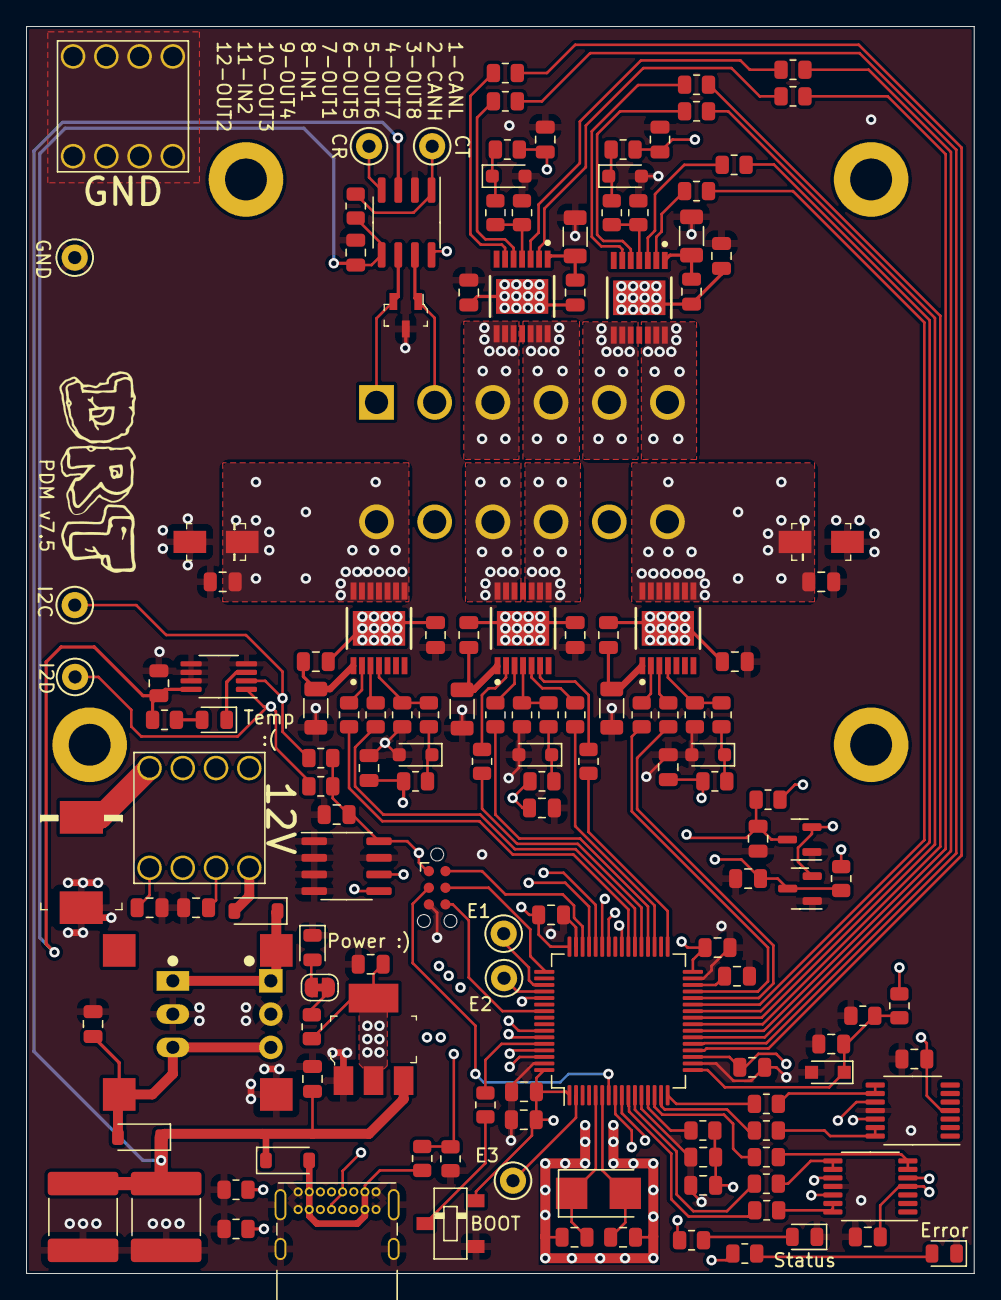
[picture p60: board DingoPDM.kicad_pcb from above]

Board: 4 copper layers, 72.4 x 95.2 mm, 156 parts (1 on the bottom side), 115 nets.

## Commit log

2021-04-10 Reorganizing files
    [Analog.sch, BTS7002_1EPP.sch, BTS7008_2EPA.sch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]
2022-06-17 V3 As Built
    [BTS7008_2EPA.kicad_sch, BTS700n_1EPP.kicad_sch, Connectors.kicad_sch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]
2022-10-15 Kicad V6 updates
2022-12-07 Swapped to AMPSEAL 14 pins
    [BTS7008_2EPA.kicad_sch, BTS700n_1EPP.kicad_sch, Connectors.kicad_sch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]
2022-12-07 Removed unused IRQs, added pd res on PF GPIO reset
    [BTS7008_2EPA.kicad_sch, BTS700n_1EPP.kicad_sch, DingoPDM.kicad_sch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]
2022-12-13 layout finished
    [BTS7008_2EPA.kicad_sch, BTS700n_1EPP.kicad_sch, Connectors.kicad_sch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]
2023-01-05 Removed files from the index (now ignored)
    [DingoPDM_DK_bom_v2.csv, DingoPDM_DK_bom_v3.csv, DingoPDM_bom_v2.csv]
2023-02-06 Moved folders
    [DingoPDM.kicad_sch, MCU.kicad_sch]
2023-02-09 Removed old notes
    [DingoPDM_bom_v2.xls]
2023-02-09 Updated gerbers
    [DingoPDM-B_Cu.gbl, DingoPDM-B_Mask.gbs, DingoPDM-B_Silkscreen.gbo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]
2023-02-10 Added export, fixed some PNs
    [Connectors.kicad_sch, I2C.kicad_sch, MCU.kicad_sch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]
2023-02-23 V5 changes
    Changed tracks/clearances/DRC to meet JLCPCB 2oz rules. Changed on switch to 12V input. Switched to TagConnect
    [BTS7008_2EPA.kicad_sch, BTS700n_1EPP.kicad_sch, Connectors.kicad_sch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]
2023-02-24 Documentation cleanup
    [BTS7008_2EPA.kicad_sch, BTS700n_1EPP.kicad_sch, Connectors.kicad_sch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]
2023-02-24 V5 As Built
    -Changed ADS1015 to MAX11613EUA+T due to supply issues
    -Changed PCB to match JLCPCB 2oz rules
    -Changed ON_SW input to 12V switched
    -Switched to TagConnect TC2030
    -Changed pin positions of GND, IN1, IN2
    [BTS7008_2EPA.kicad_sch, BTS700n_1EPP.kicad_sch, Connectors.kicad_sch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]
2023-02-24 No black soldermask with 2oz available at JLCPCB
2023-03-11 Incorrect PN for some diodes and resistors
    [BTS7008_2EPA.kicad_sch, BTS700n_1EPP.kicad_sch, DingoPDM.kicad_sch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]
2023-03-11 Wrong opto-isolator part number
    [DingoPDM_HW_V5_BOM.csv, Power.kicad_sch]
2023-04-02 Changed schematic sheet size to letter
    [BTS7008_2EPA.kicad_sch, BTS700n_1EPP.kicad_sch, Connectors.kicad_sch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]
2023-04-02 Added black/white and dark PDF schematics
2023-04-02 Update to Kicad 7.0.1
2023-05-04 Added V5 case design
    [Connectors.kicad_sch, DingoPDM_V5_Case.stl, DingoPDM_V5_Case_BOM.csv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]
2023-07-28 Redesigned to a smaller unit
    4x high current, 2x med current, 4x low current, 2x digital inputs
    [BTS7008_2EPA.kicad_sch, BTS700n_1EPP.kicad_sch, Connectors.kicad_sch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]
2023-08-01 Added documentation, finished and cleaned design
    [BTS7008_2EPA.kicad_sch, BTS700n_1EPP.kicad_sch, Connectors.kicad_sch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]
2023-08-19 Changed to STM32F446RE
    [BTS7008_2EPA.kicad_sch, Connectors.kicad_sch, DingoPDM.kicad_pcb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]
2023-08-20 Routed V7
    [DigIn.kicad_sch, DingoPDM.kicad_pcb, HighCurrentDrivers.kicad_sch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]
2023-08-21 Small edits
    [BTS7008_2EPA.kicad_sch, BTS700n_1EPP.kicad_sch, Connectors.kicad_sch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]
2023-08-21 Updated V7 Exports
    [Connectors.kicad_sch, DingoPDM_HW_V7_BOM.csv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]
2023-08-21 Small updates
    [DingoPDM.kicad_pcb]
2023-09-05 V7.1 Fixes
    SDA/SCL mixed up on FRAM, added status LEDs, switched to thermal relief zones
    [BTS7008_2EPA.kicad_sch, BTS700n_1EPP.kicad_sch, Baseplate.step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]
2023-09-12 Add diode, disconnect PB13, fix USB VBUS
    [BTS7008_2EPA.kicad_sch, BTS700n_1EPP.kicad_sch, Baseplate.step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]
2023-09-12 Fixed local machine 3D model issue
    [7461084_Download_STP_7461084_rev1.stp, ABM3.STEP, CJS-1200TB.stp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]
2023-11-26 Trying out Github pages and mkdocs material
2023-11-28 Removing duplicate and old documentation
    [DingoPDM_Case_BOM.csv, DingoPDM_V5_Case.stl, DingoPDM_V5_Case_BOM.csv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]
2023-11-29 New PCB image and cleaning up mkdocs
2023-12-01 Status and Error LED part num switched
    [DingoPDM.kicad_pcb, DingoPDM_HW_V7_2_BOM.csv, MCU.kicad_sch]
2023-12-07 Incorrect screw length
2024-02-04 Updated case design
    Added light pipes, label and fixed height due to thermal pad material
    [Case.step]
2024-02-05 Mounting holes and bad image
    [Case.step]
2024-03-21 Updated JLC zener diode part and batt volt divider
    The previous zener diode had too low of a breakdown zener voltage.
    The previous voltage divider was also too high of an output voltage, swapped R2 to lower the max voltage to well below the breakdown zener voltage
    [BTS7008_2EPA.kicad_sch, BTS700n_1EPP.kicad_sch, DingoPDM.kicad_sch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]
2024-03-25 Update JLC part numbers for in stock ones
    [BTS7008_2EPA.kicad_sch, BTS700n_1EPP.kicad_sch, DingoPDM_HW_V7_2_BOM.csv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]
2024-04-24 Fixed error in case model
    #8
2024-05-08 Fixed missing silkscreen values
    BOOT, E1, E2, E3 labels were missing
2024-05-10 Fixed Case.step
    Previous model was the whole assembly
2024-05-27 Fixed USB, power LED and CAN standby
    And increased screw hole size
    #9, #11, #12, #13
    [BTS7008_2EPA.kicad_sch, BTS700n_1EPP.kicad_sch, Baseplate.step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]
2024-06-17 LED and error information added
2024-09-03 Added diode for reverse battery protection
    #14
    [Baseplate.step, Case.step, DingoPDM.kicad_pcb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]
2024-09-06 Updated to Kicad 8
    [BTS7008_2EPA.kicad_sch, BTS700n_1EPP.kicad_sch, Connectors.kicad_sch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]
2024-12-31 add wiring aid stl model
    [DingoPDM_V7_WiringAid.stl]
2025-01-24 updated wiring aid stl
    [DingoPDM_V7_WiringAid.stl]
2025-03-05 docs, add mkdocs charts
    [dingopdm_stresstest.csv]
2025-03-10 add pwm thermal tests
    [dingopdm_stresstest.csv]
2025-03-11 docs - more thermal tests
    [dingopdm_stresstest.csv, dingopdm_stresstest_reduced.csv]
2025-03-12 docs - thermal degrees f to c
    [dingopdm_stresstest.csv, dingopdm_stresstest_reduced.csv]
2025-03-12 docs - changing thermal chart type
    [dingopdm_stresstest.csv, dingopdm_stresstest_reduced.csv]
2025-03-13 docs - add interactive to thermal chart
    [dingopdm_stresstest.csv, dingopdm_stresstest_reduced.csv]
2025-04-17 docs - add to firmware
    [Connectors.kicad_sch, DingoPDM.kicad_pcb, MCU.kicad_sch]
2025-04-17 undo accidental changes to kicad
    [Connectors.kicad_sch, DingoPDM.kicad_pcb, MCU.kicad_sch]
2025-04-24 update to kicad 9.0.1
    [BTS7008_2EPA.kicad_sch, BTS700n_1EPP.kicad_sch, Connectors.kicad_sch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]
2025-04-30 docs - add wiring example
2025-05-07 add DC-DC converter options
    [BTS7008_2EPA.kicad_sch, BTS700n_1EPP.kicad_sch, Connectors.kicad_sch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]
2025-06-17 add 5v cap
    [BTS7008_2EPA.kicad_sch, BTS700n_1EPP.kicad_sch, Connectors.kicad_sch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]
2025-06-17 add v7.5 exports
    [Baseplate.step, Case.step, Connectors.kicad_sch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]
2025-06-17 add dark schematic
2025-06-17 switch to ceramic caps
    [Connectors.kicad_sch, DingoPDM.kicad_pcb, Power.kicad_sch]
2025-06-17 updated silk version
    [DingoPDM.kicad_pcb]
2025-07-07 update part nums, remove custom drc, add max thermal
    [Connectors.kicad_sch, Power.kicad_sch, dingopdmmax_stresstest.csv]
2025-08-19 move footprints to project library
    [BTS7008_2EPA.kicad_sch, BTS700n_1EPP.kicad_sch, Connectors.kicad_sch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]
2025-09-30 docs - add iboms
    [Connectors.kicad_sch, DingoPDM.kicad_pcb, Power.kicad_sch]
2025-09-30 PCB Checklist added.
2025-09-30 docs - update pwm can msg
2026-01-24 docs - add den pin
2026-06-20 add paleppp case design
    [Baseplate.3mf, Baseplate.dxf, Baseplate.step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]
2026-08-17 routing inputs
    [BTS70012-1ESP.kicad_sch, CAN.kicad_sch, DTM_12Pins.step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]
2026-09-26 fix tvs jlc pn, #25
    update to kicad v10
    [BTS7008_2EPA.kicad_sch, BTS700n_1EPP.kicad_sch, Connectors.kicad_sch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]
2026-09-26 update old v6 bom, tvs jlc pn, #25
    [DingoPDM_HW_V6_BOM.csv, DingoPDM_HW_V6_BOM_Grouped.csv]

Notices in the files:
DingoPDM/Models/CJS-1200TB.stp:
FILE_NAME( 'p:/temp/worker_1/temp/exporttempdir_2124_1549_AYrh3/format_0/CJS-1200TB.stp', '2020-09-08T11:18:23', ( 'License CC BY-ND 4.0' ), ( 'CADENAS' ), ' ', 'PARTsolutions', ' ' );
